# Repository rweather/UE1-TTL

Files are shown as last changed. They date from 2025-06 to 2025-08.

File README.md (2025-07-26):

UE1 Computer in TTL
===================

## What is this?

This is an implementation of the [Usagi Electric UE1 vacuum tube computer architecture](https://github.com/Nakazoto/UEVTC/wiki)
in TTL logic.  It runs the same code as the original.

Here is the top and bottom of the version 1 prototype, just after running the
Fibonacci example (click for a larger image):

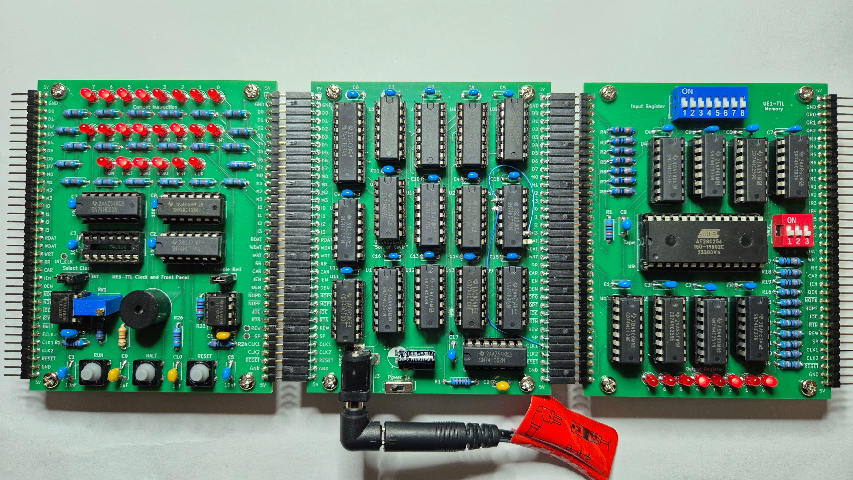
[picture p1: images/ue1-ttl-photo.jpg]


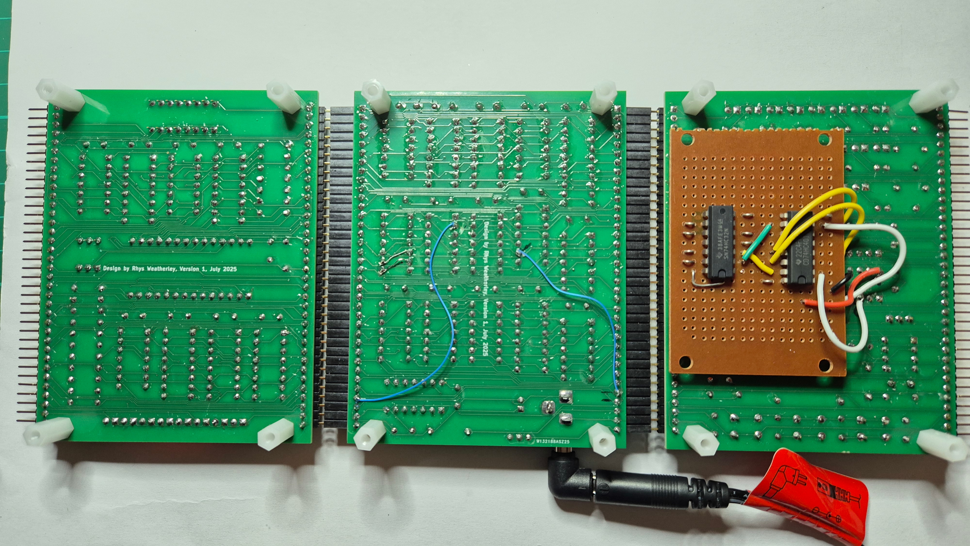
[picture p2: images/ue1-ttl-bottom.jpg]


I made some mistakes in the version 1 prototype that needed bodging.
The schematics and gerbers below have been updated to include the fixes.

## Specifications

* TTL logic, 555 timers, and EEPROM chips only.  No cheating with a modern
  microcontroller running an emulator.
* 1-bit processor core based on the UE14500 instruction set.
* 8-bit scratch register (general-purpose RAM).
* 8-bit output register.
* 7-bit input register.
* EEPROM that stores up to 8 program "tapes", each up to 4096 instructions.
  DIP switches select which program to run.
* 555-based clock that runs at frequencies between 0.7Hz and 480Hz.
* Run, Halt, and Reset buttons to control the computer.
* Blinkenlichten!
* Bell buzzer.
* Runs off a single 5V DC supply.

The computer is split across three PCB's, because:

* PCB's less than 100mm x 100mm in size are cheaper to get made.
* The aspect ratio of the boards is close to those of the wooden backing
  boards in the original UE1 to provide a similar visual aesthetic
  (although I need 3 boards compared with the original 2).
* It is easier to upgrade one of the boards without having to re-spin
  the other boards.

## Technical information

* [Theory of operation](doc/theory_of_operation.md)
* [Signals on the edge connectors](doc/edge_connectors.md)

### Clock and front panel board

* [Schematics](schematics/UE1-TTL-Clock/PDF/UE1-TTL-Clock.pdf)
* [Gerbers](schematics/UE1-TTL-Clock/Gerber)
* [Assembling and testing](doc/testing_clock.md)
* [Version 1 mistakes](doc/testing_clock.md#version-1-mistakes)

### Processor board

* [Schematics](schematics/UE14500-TTL/PDF/UE14500-TTL.pdf)
* [Gerbers](schematics/UE14500-TTL/Gerber)
* [Assembling and testing](doc/testing_processor.md)
* [Version 1 mistakes](doc/testing_processor.md#version-1-mistakes)

### Memory and I/O board

* [Schematics](schematics/UE1-TTL-Memory/PDF/UE1-TTL-Memory.pdf)
* [Gerbers](schematics/UE1-TTL-Memory/Gerber)
* [Assembling and testing](doc/testing_memory.md)
* [Version 1 mistakes](doc/testing_memory.md#version-1-mistakes)

## Programming the computer

To reprogram the computer it is necessary to remove the 32K AT28C256 tape
EEPROM from the memory board and flash in a new set of tape images using an
EEPROM programmer.

There can be up to 8 programs in the EEPROM, with DIP switches to select
which program to run.  Each program is up to 4096 instructions long,
which corresponds to about 10m of paper tape.  Each instruction consists
of a 4-bit opcode and a 4-bit memory address just like in the vacuum tube
based UE1.

Pad shorter programs with NOP0 instructions or replicate the program
multiple times to fill up the 4096 bytes of space.  There is a new
"rewind" opcode that can be used to loop short programs without
excessive NOP0's.  See the next section.

The "programs" directory contains some sample programs, together with a
Python script to pack up to 8 binaries into a single 32K EEPROM image.

## Instruction set

This computer uses the same [instruction set](https://github.com/Nakazoto/UEVTC/wiki/UE14500-Processor)
as the original computer.  The only difference is the introduction of a
"rewind" opcode which is encoded as "NOP0" with a memory address between
8 and 15 - bytes $08 to $0F in hexadecimal.

The rewind opcode causes the 12-bit program counter to reset back to 0
immediately, rather than waiting for the program counter to wrap around.
This can be convenient for short looping programs to avoid a long wait
for the loop to restart.

## Parts lists

In the parts lists below, "RLED" refers to the inline series resistor
for the LED's.  The value depends upon the type of LED you have, and can
be calculated from the LED's voltage drop (VLED) and rated current (ILED)
as follows:

    RLED = (5 - VLED) / ILED

For example, if your LED is rated for 1.9V and 10mA, then RLED should be
at least (5 - 1.9) / 0.01 = 310 ohms.  A 330 ohm resistor will do.
I recommend using LED's with 2mA or less current rating to avoid putting
too much strain on the TTL logic outputs.  I used 2mA LED's and RLED =
1800 ohms.

The IC's are listed as 74LS series, but you can use 74HC series instead.
Use the same series for all chips.

Parts lists for individual boards are listed first, and then a combined
parts list for the whole computer.

### Clock and front panel board

* 2 x 555 timer
* 1 x 74HC4017 decade counter
* 1 x 74LS74 dual D flip-flop
* 1 x 74LS02 quad NOR gate
* 1 x 74LS132 quad NAND gate with Schmitt trigger
* 2 x 10nF ceramic or monolithic capacitor
* 4 x 100nF ceramic or monolithic capacitor
* 4 x 1uF ceramic or monolithic capacitor
* 1 x 1M trimpot
* 2 x 1K resistor
* 1 x 3K3 resistor
* 1 x 4K7 resistor
* 1 x 10K resistor
* 1 x 100K resistor
* 22 x RLED resistor
* 22 x 3mm LED (colour of your choice)
* 1 x Buzzer with 7.6mm pin pitch
* 3 x 6mm momentary push button
* 1 x 3-way 2.54mm pin header
* 1 x 2-way 2.54mm pin header
* 2 x 2.54mm jumper
* 2 x 36-pin right-angle terminal header
* 2 x 8-pin DIP socket
* 3 x 14-pin DIP socket
* 1 x 16-pin DIP socket

### Processor board

* 3 x 74LS00 quad NAND gate
* 3 x 74LS02 quad NOR gate
* 2 x 74LS08 quad AND gate
* 3 x 74LS74 dual D flip-flop
* 1 x 74LS86 quad XOR gate
* 2 x 74LS138 3-to-8 line decoder
* 1 x 74LS251 8-line to 1-line multiplexer
* 1 x 74LS374 8-bit register
* 1 x 100uF electrolytic capacitor
* 1 x 1uF ceramic or monolithic capacitor
* 16 x 100nF ceramic or monolithic capacitor
* 1 x 10K resistor
* 1 x SPDT 2.54mm slide switch
* 1 x 2.5mm DC barrel jack
* 2 x 36-pin right-angle terminal socket
* 12 x 14-pin DIP socket
* 3 x 16-pin DIP socket
* 1 x 20-pin DIP socket

### Memory and I/O board

* 1 x AT28C256 32K x 8 EEPROM
* 1 x 74LS32 quad OR gate
* 1 x 74LS139 dual 2-to-4 line decoder
* 2 x 74LS251 8-line to 1-line multiplexer
* 2 x 74LS259 8-bit addressable latch
* 2 x 74LS393 dual binary 4-bit counter
* 9 x 100nF ceramic or monolithic capacitor
* 1 x 10K resistor
* 10 x 100K resistor
* 8 x RLED resistor
* 8 x 3mm LED (colour of your choice)
* 1 x 8-way DIP switches
* 1 x 3-way DIP switches
* 2 x 36-pin right-angle terminal header
* 3 x 14-pin DIP socket
* 5 x 16-pin DIP socket
* 1 x 28-pin DIP socket (15.24mm pitch width)

I recommend using a socket for the 28-pin EEPROM even if you don't use
sockets for the other chips.  You will need to easily remove the EEPROM to
reprogram it.

## Combined part list

This section combines all three lists into one to make it easier to
order the parts for the whole computer.  As stated before, 74HC series
chips can be used in place of 74LS.

* 1 x AT28C256 32K x 8 EEPROM
* 2 x 555 timer
* 1 x 74HC4017 decade counter
* 3 x 74LS00 quad NAND gate
* 4 x 74LS02 quad NOR gate
* 2 x 74LS08 quad AND gate
* 1 x 74LS32 quad OR gate
* 4 x 74LS74 dual D flip-flop
* 1 x 74LS86 quad XOR gate
* 1 x 74LS132 quad NAND gate with Schmitt trigger
* 2 x 74LS138 3-to-8 line decoder
* 1 x 74LS139 dual 2-to-4 line decoder
* 3 x 74LS251 8-line to 1-line multiplexer
* 2 x 74LS259 8-bit addressable latch
* 1 x 74LS374 8-bit register
* 2 x 74LS393 dual binary 4-bit counter
* 1 x 100uF electrolytic capacitor
* 5 x 1uF ceramic or monolithic capacitor
* 2 x 10nF ceramic or monolithic capacitor
* 29 x 100nF ceramic or monolithic capacitor
* 1 x 1M trimpot
* 2 x 1K resistor
* 1 x 3K3 resistor
* 1 x 4K7 resistor
* 3 x 10K resistor
* 11 x 100K resistor
* 30 x RLED resistor
* 30 x 3mm LED (colour of your choice)
* 1 x SPDT 2.54mm slide switch
* 1 x 2.5mm DC barrel jack
* 1 x Buzzer with 7.6mm pin pitch
* 3 x 6mm momentary push button
* 1 x 3-way 2.54mm pin header
* 1 x 2-way 2.54mm pin header
* 2 x 2.54mm jumper
* 1 x 8-way DIP switches
* 1 x 3-way DIP switches
* 4 x 36-pin terminal header (for clock and memory boards)
* 2 x 36-pin terminal socket (for CPU board)
* 2 x 8-pin DIP socket
* 18 x 14-pin DIP socket
* 9 x 16-pin DIP socket
* 1 x 20-pin DIP socket
* 1 x 28-pin DIP socket (15.24mm pitch width)

I recommend using a socket for the 28-pin EEPROM even if you don't use
sockets for the other chips.  You will need to easily remove the EEPROM to
reprogram it.

## License

<p xmlns:cc="http://creativecommons.org/ns#" xmlns:dct="http://purl.org/dc/terms/"><span property="dct:title">UE1 TTL</span> by <span property="cc:attributionName">Rhys Weatherley</span> is licensed under <a href="http://creativecommons.org/licenses/by-nc-sa/4.0/?ref=chooser-v1" target="_blank" rel="license noopener noreferrer" style="display:inline-block;">Attribution-NonCommercial-ShareAlike 4.0 International</a></p>

## Contact

For more information on this project, to report bugs, or to suggest
improvements, please contact the author Rhys Weatherley via
[email](mailto:rhys.weatherley@gmail.com).

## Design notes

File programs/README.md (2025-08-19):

This directory contains a 32K ROM image `UE1TEST.ROM` that can be used
to test the functionality of the UE1-TTL computer.

The ROM can hold up to eight programs, that are selected using DIP
switches on the memory board:

* 0 - UE1FIBO - Calculates the Fibonacci sequence up to 21, by Usagi Electric.
* 1 - UE1MATH - Performs addition and subtraction, by Usagi Electric.
* 2 - UE1\_DIAPER1 - Tests the entire instruction set except input and output.
* 3 - UE1\_DIAPER2 - Tests input and output.
* 4 - MUL5X5 - Multiplies two 5-bit numbers to produce a 10-bit result.
* 5 - DIV8x4 - Divides an 8-bit number by a 4-bit number to give an 8-bit quotient and a 4-bit remainder.
* 6 - UE1LIFE - 1-D game of life by decle.
* 7 - Rabbit example.

The Python script `ue1-ttl-pack.py` packs eight program images into a
single 32K ROM image.  It can be used to create ROM images with new programs.

The Rabbit example (program 7) is intended for use with an 8x8 dot matrix
LED display module that uses the MAX7221 LED driver chip.  The 3594
instructions of the program bit-bang out the SPI commands for displaying
"HELLORLD" followed by a picture of a rabbit.  See the Python script
"rabbit-gen.py" for more information on how to wire up the module.

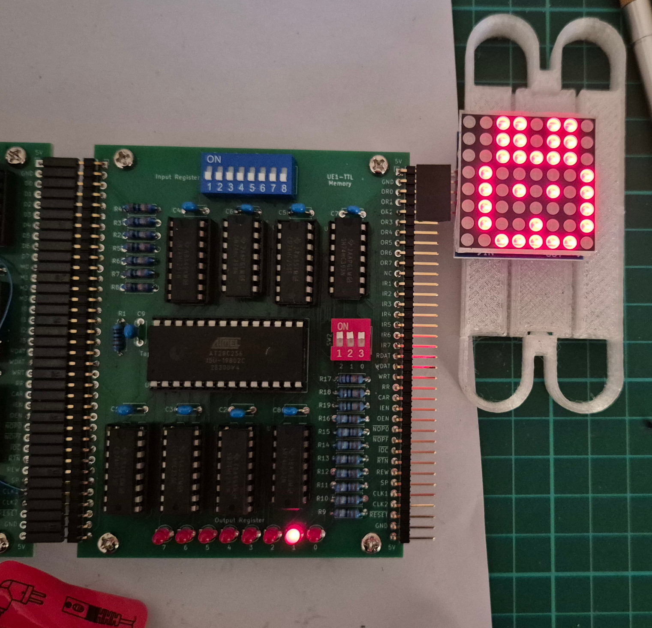
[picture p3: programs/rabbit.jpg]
UE1 Rabbit


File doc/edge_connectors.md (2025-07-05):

Signals on the Edge Connectors
==============================

The signals on the edge connectors are mostly passed as-is through to
each board.  There are some exceptions on the left-hand side of the
clock board and on the right-hand side of the memory board.

In the table below, "A/B" indicates that the pin has function "A" on
the left-hand side of a board and function "B" on the right-hand
side of a board.  "NC" indicates "not connected".

<table border="1">
<tr><td><b>Pin</b></td><td><b>Clock</b></td><td><b>Processor</b></td><td><b>Memory</b></td><td><b>Description</b></td></tr>
<tr><td>1</td><td>5V</td><td>5V</td><td>5V</td><td>Power</td></tr>
<tr><td>2</td><td>GND</td><td>GND</td><td>GND</td><td>Ground</td></tr>
<tr><td>3</td><td>D0</td><td>D0</td><td>D0/OR0</td><td>Bit 0 of the unbuffered tape instruction, or output register bit 0</td></tr>
<tr><td>4</td><td>D1</td><td>D1</td><td>D1/OR0</td><td>Bit 1 of the unbuffered tape instruction, or output register bit 1</td></tr>
<tr><td>5</td><td>D2</td><td>D2</td><td>D2/OR0</td><td>Bit 2 of the unbuffered tape instruction, or output register bit 2</td></tr>
<tr><td>6</td><td>D3</td><td>D3</td><td>D3/OR0</td><td>Bit 3 of the unbuffered tape instruction, or output register bit 3</td></tr>
<tr><td>7</td><td>D4</td><td>D4</td><td>D4/OR0</td><td>Bit 4 of the unbuffered tape instruction, or output register bit 4</td></tr>
<tr><td>8</td><td>D5</td><td>D5</td><td>D5/OR0</td><td>Bit 5 of the unbuffered tape instruction, or output register bit 5</td></tr>
<tr><td>9</td><td>D6</td><td>D6</td><td>D6/OR0</td><td>Bit 6 of the unbuffered tape instruction, or output register bit 6</td></tr>
<tr><td>10</td><td>D7</td><td>D7</td><td>D7/OR0</td><td>Bit 7 of the unbuffered tape instruction, or output register bit 7</td></tr>
<tr><td>11</td><td>MEM0</td><td>MEM0</td><td>MEM0/NC</td><td>Bit 0 of the buffered memory address</td></tr>
<tr><td>12</td><td>MEM1</td><td>MEM1</td><td>MEM1/IR1</td><td>Bit 1 of the buffered memory address, or input register bit 1</td></tr>
<tr><td>13</td><td>MEM2</td><td>MEM2</td><td>MEM2/IR2</td><td>Bit 2 of the buffered memory address, or input register bit 2</td></tr>
<tr><td>14</td><td>MEM3</td><td>MEM3</td><td>MEM3/IR3</td><td>Bit 3 of the buffered memory address, or input register bit 3</td></tr>
<tr><td>15</td><td>INST0</td><td>INST0</td><td>NC/IR4</td><td>Bit 0 of the buffered instruction opcode, or input register bit 4</td></tr>
<tr><td>16</td><td>INST1</td><td>INST1</td><td>NC/IR5</td><td>Bit 1 of the buffered instruction opcode, or input register bit 5</td></tr>
<tr><td>17</td><td>INST2</td><td>INST2</td><td>NC/IR6</td><td>Bit 2 of the buffered instruction opcode, or input register bit 6</td></tr>
<tr><td>18</td><td>INST3</td><td>INST3</td><td>NC/IR7</td><td>Bit 3 of the buffered instruction opcode, or input register bit 7</td></tr>
<tr><td>19</td><td>RD_DATA</td><td>RD_DATA</td><td>RD_DATA</td><td>Read data line, output from memory, input to processor</td></tr>
<tr><td>20</td><td>WR_DATA</td><td>WR_DATA</td><td>WR_DATA</td><td>Write data line, output from processor, input to memory</td></tr>
<tr><td>21</td><td>WRITE</td><td>WRITE</td><td>WRITE</td><td>Write control signal to memory, latch on falling edge</td></tr>
<tr><td>22</td><td>RR</td><td>RR</td><td>RR</td><td>State of the result register RR</td></tr>
<tr><td>23</td><td>CAR</td><td>CAR</td><td>CAR</td><td>State of the carry register CAR</td></tr>
<tr><td>24</td><td>IEN</td><td>IEN</td><td>IEN</td><td>State of the input enable register IEN</td></tr>
<tr><td>25</td><td>OEN</td><td>OEN</td><td>OEN</td><td>State of the output enable register OEN</td></tr>
<tr><td>26</td><td>OP_NOP0</td><td>OP_NOP0</td><td>OP_NOP0</td><td>Low when a NOP0 instruction is being executed</td></tr>
<tr><td>27</td><td>OP_NOPF</td><td>OP_NOPF</td><td>OP_NOPF</td><td>Low when a NOPF/HLT instruction is being executed</td></tr>
<tr><td>28</td><td>OP_IOC</td><td>OP_IOC</td><td>OP_IOC</td><td>Low when a IOC/BEL instruction is being executed</td></tr>
<tr><td>29</td><td>OP_RTN</td><td>OP_RTN</td><td>OP_RTN</td><td>Low when a RTN instruction is being executed</td></tr>
<tr><td>30</td><td>HALTED/REWIND</td><td>REWIND</td><td>REWIND</td><td>High when a rewind instruction is being executed, or the active-low halt signal on the left-hand side of the clock board</td></tr>
<tr><td>31</td><td>EXT_CLK/SPARE</td><td>SPARE</td><td>SPARE</td><td>Spare signal that is passed to all boards, or the external clock on the left-hand side of the clock board</td></tr>
<tr><td>32</td><td>CLK1</td><td>CLK1</td><td>CLK1</td><td>CLK1 pulse for the two-phase clock</td></tr>
<tr><td>33</td><td>CLK2</td><td>CLK2</td><td>CLK2</td><td>CLK2 pulse for the two-phase clock</td></tr>
<tr><td>34</td><td>RESET</td><td>RESET</td><td>RESET</td><td>Active-low signal to reset the system</td></tr>
<tr><td>35</td><td>GND</td><td>GND</td><td>GND</td><td>Ground</td></tr>
<tr><td>36</td><td>5V</td><td>5V</td><td>5V</td><td>Power</td></tr>
</table>

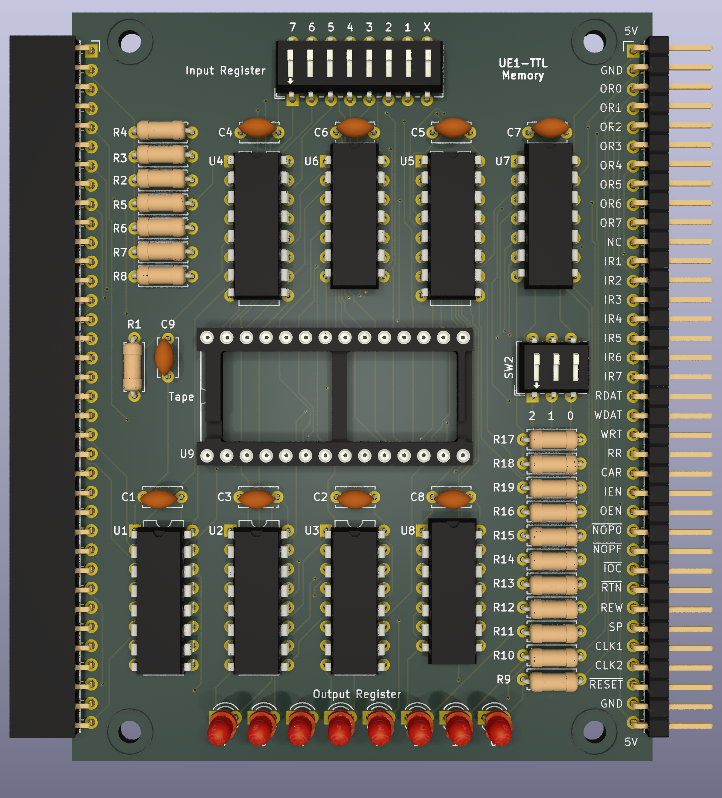
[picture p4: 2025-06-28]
images/kicad-3d-memory-board.png

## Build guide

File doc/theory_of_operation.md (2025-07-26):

UE1 TTL Computer Theory of Operation
====================================

## Overview

This page explains the theory of operation of the TTL version of the UE1.

The design is not gate-compatible with the original NOR gate heavy
vacuum tube computer.  I wimped out and used dedicated TTL chips for
flip-flops, AND/OR/NAND/XOR gates, multiplexers, decoders, memory chips, etc.
The design runs the same code, but not in the same way.

In the sections below, "P/Un" is used to refer to IC's on the processor
board, "C/Un" is used to refer to IC's on the clock board, and
"M/Un" is used to refer to IC's on the memory board.

## Clock

The processor requires a two-phase clock, delivered on the CLK1 and CLK2
pins of the edge connector.  The waveforms look like this:

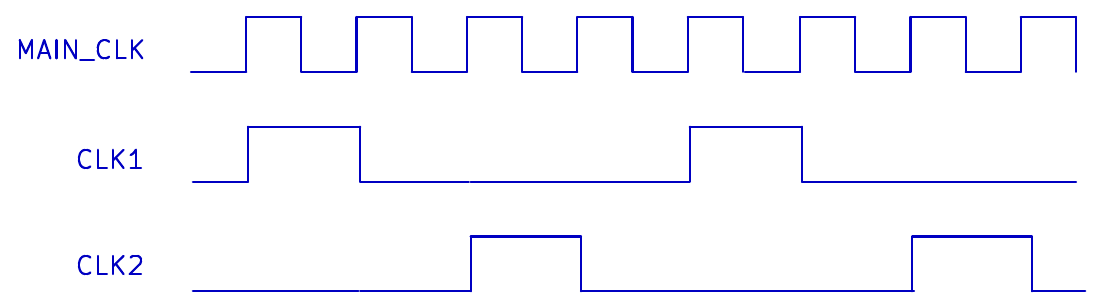
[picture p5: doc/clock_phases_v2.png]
Clock Phases


* Rising edge of CLK1 - Load the next instruction into the instruction register.
* Falling edge of CLK1 - Perform the instruction; update registers and memory.
* Rising edge of CLK2 - Update the SKIP register.
* Falling edge of CLK2 - Increment the program counter / tape position.

The original UE1 also has a two-phase clock, which it achieves with an
RC delay on CLK1 to produce CLK2.  The two clock pulses overlap which
makes it closer to one clock cycle per instruction than my design.

The clock board derives CLK1 and CLK2 from the MAIN\_CLK signal.
C/U3 on the clock board is a 555 timer that provides the MAIN\_CLK
between 0.7Hz and 480Hz.  This is divided by four by C/U2 to create
CLK1 and CLK2:

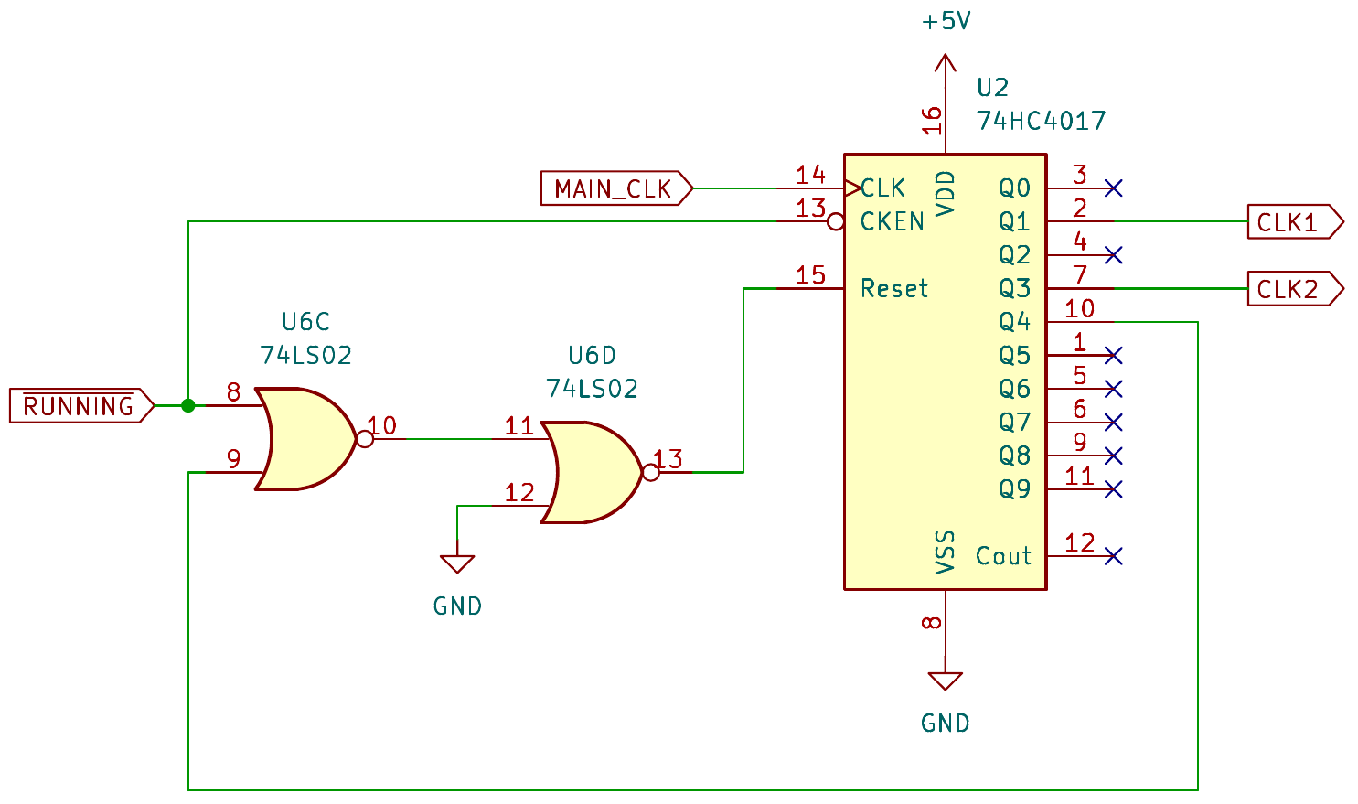
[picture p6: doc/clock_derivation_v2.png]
Clock Derivation


The /RUNNING signal forces both clocks to zero when the machine halts
by holding C/U2 in reset and disabling the clock input.  The clock
resumes with CLK1 preceding CLK2 when /RUNNING goes high.

If /RUNNING goes high in the middle of a CLK1 pulse or before the rising
edge of CLK2, then the current instruction will be only partially executed.

The maximum CPU speed is 120 instructions per second.  If you want to run the
computer faster than that, there are two options:

* Change C4 in the clock circuit from 1uF to something smaller.  Changing it
  to 100nF will give a 10x improvement in performance.
* Move the "Select Clock" jumper to the EXT position and inject your
  own MAIN\_CLK from off-board.

My previous clock design in version 1 used a 74LS74 flip-flop and AND gates to
generate CLK1 and CLK2 with a divide-by-two setup:

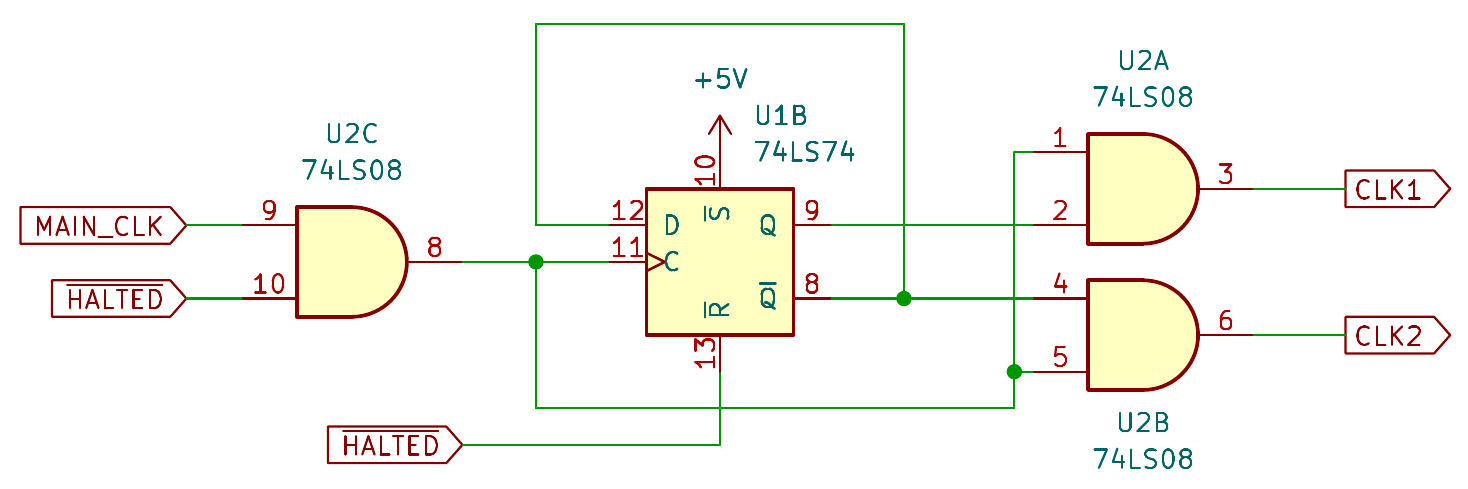
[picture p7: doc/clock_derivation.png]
Clock Derivation Version 1


This caused clock gitches all over the place, causing double increments on
the program counter, false memory writes, and other problems.  The waveform
looked something like this:

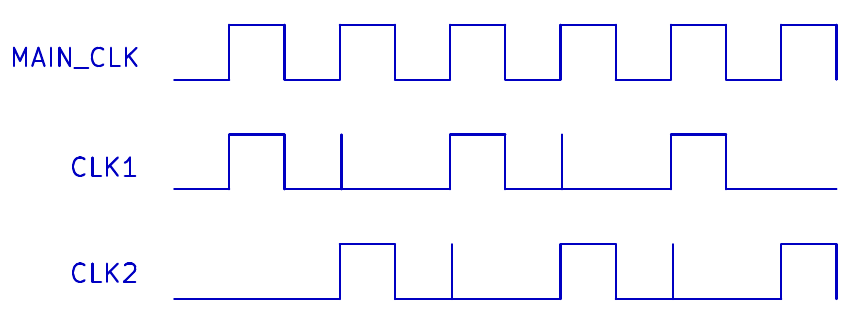
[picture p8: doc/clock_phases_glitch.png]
Glitching Clock Phases


Never gate your clock!  I know that now!

## Run/Stop Control

The Run/Stop circuit on the clock board handles the "Run" and "Halt"
push buttons.  When the computer resets at power-on, the system
will eventually settle into a state with /HALTED low and /RUNNING high.
Pressing "Run" will change /RUNNING to low, /HALTED to high, and the
two-phase clock will start ticking.

The "Reset" button is on the clock board, but its RC network is on
the CPU board.  "Run", "Halt", and "Reset" have different R values in
their RC networks.  All of them will be low at power-on, with "Run"
going high first, then "Halt", and finally "Reset".

Pressing "Reset" will halt the computer, reset all registers, and set
the program counter back to zero.  Pressing "Halt" halts the computer
but preserves the registers and program counter.

C/U5 interlocks the "Run" and "Halt" buttons so that if both are
pressed at the same time, "Halt" will win the battle.  The /NOPF
signal from the CPU board will cause the system to halt on the
falling edge of CLK2.  C/U5 consists of Schmitt-triggered NAND gates to
ensure that the /RUN and /STOP signals are nice and square.

There is a bug with this design.  If the "Run" button is held down,
the program will run until halt and then start running again.  "Run" and
"Halt" should only act on a low-going edge, not on a low level.
Press "Run" fast enough and it isn't an issue, for now.

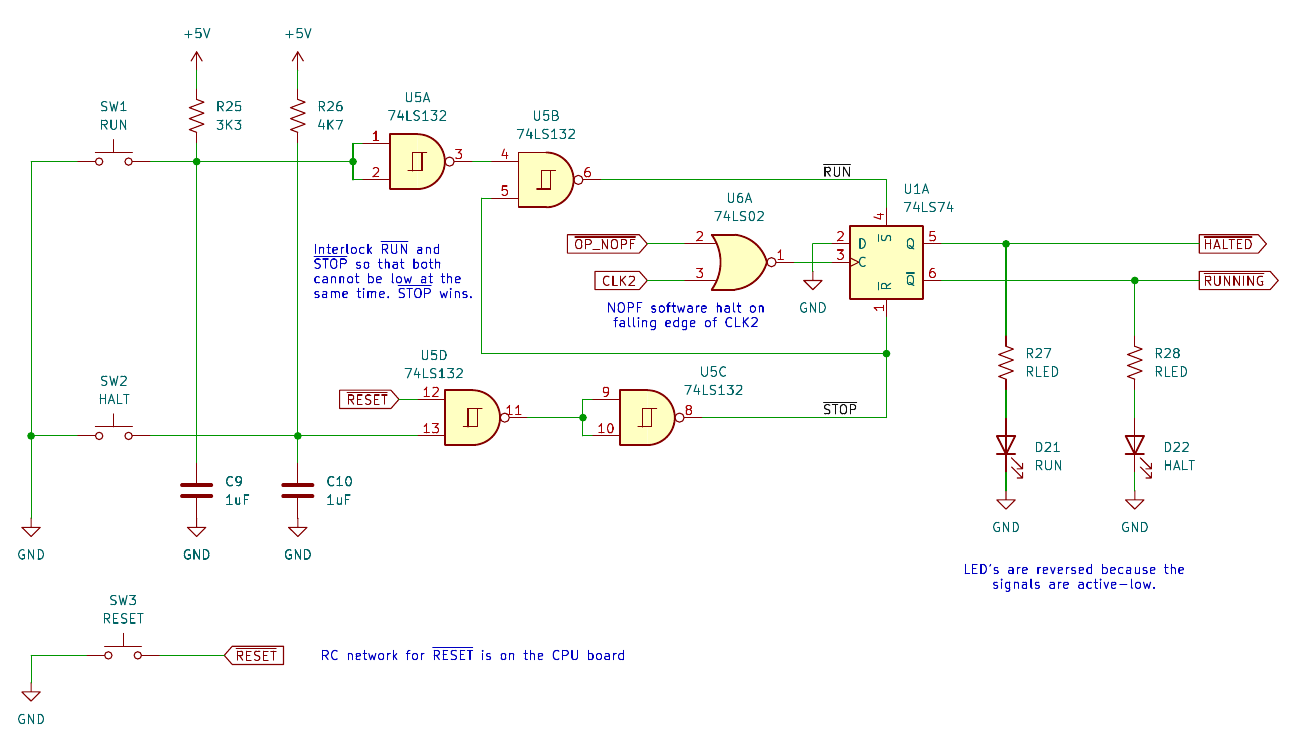
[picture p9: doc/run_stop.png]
Run/Stop Control


## Single-Stepping

The clock board does not have a method to single-step instructions,
as at the time I could not figure out how to generate a single pair of
CLK1/CLK2 pulses and then stop.

For debugging, you can hook up an external clock using a push button.
The button needs to be pressed four times to execute a single
instruction.  This is what the circuit looks like:

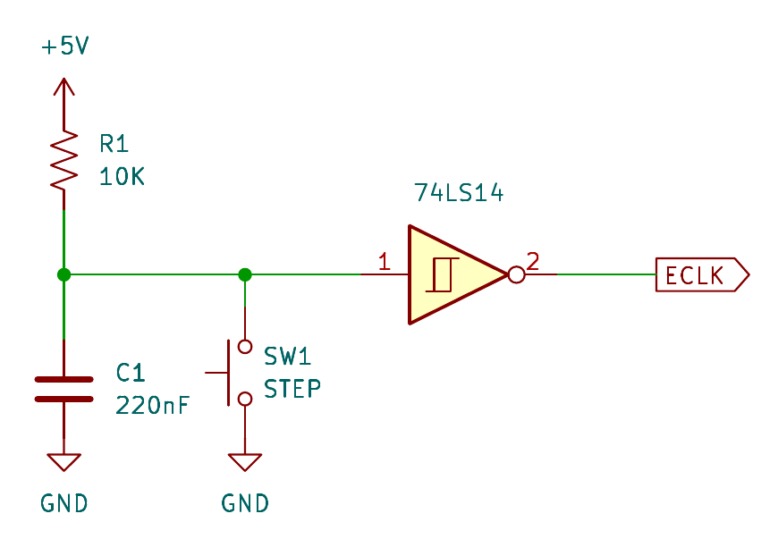
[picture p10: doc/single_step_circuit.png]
Single-Step


Shift the "Select Clock" jumper to the EXT side of the 3-pin header
to use this setup.

## Instruction Register

On the rising edge of CLK1, the next instruction is loaded into P/U4, a
74LS374 8-bit register.  The instruction data itself comes from the
memory board on the D0 to D7 pins.  P/U4 buffers the instruction and
makes the buffered memory address available to the memory board on
MEM0 to MEM3.

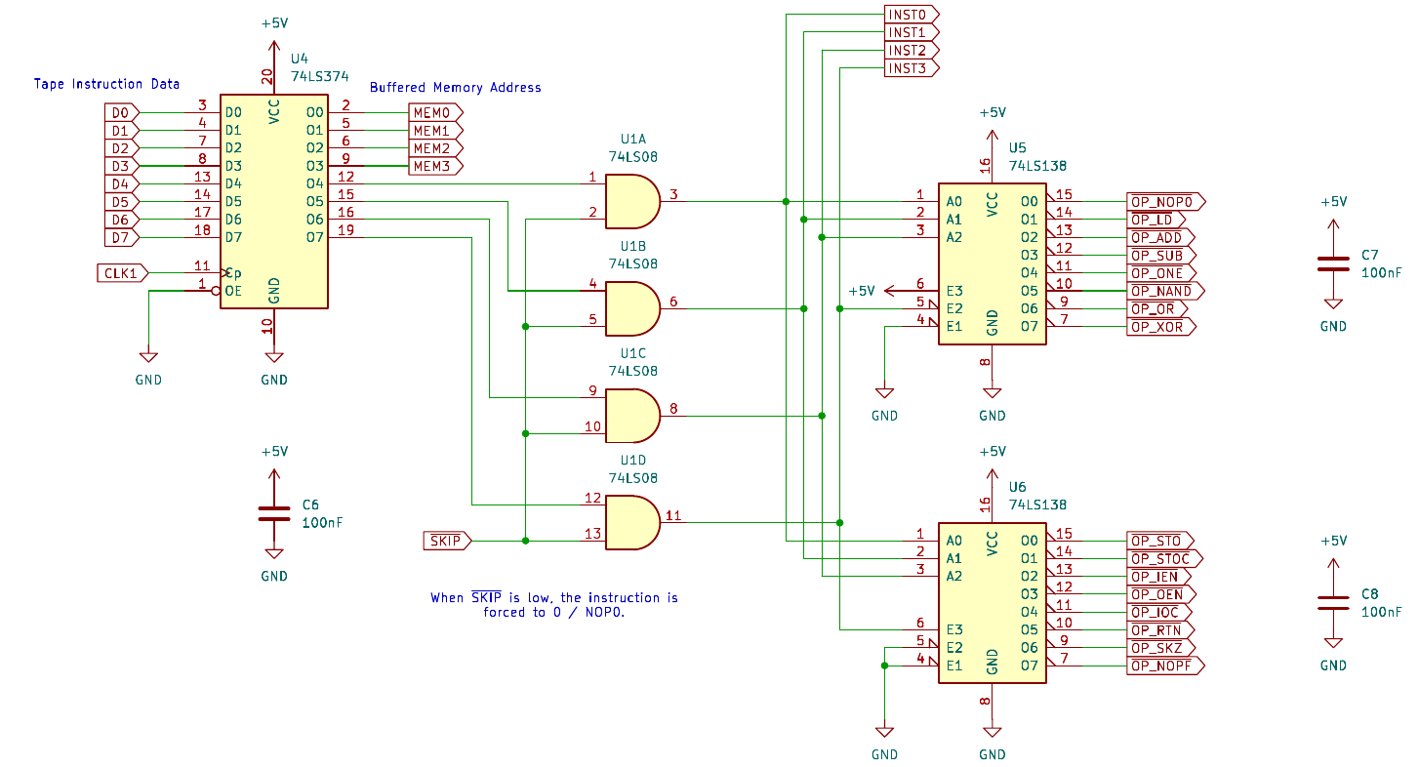
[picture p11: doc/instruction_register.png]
Instruction Register


If the SKIP register is set to 1, then /SKIP is set to 0.  The quad AND
gate P/U1 forces the instruction opcode to NOP0 / 0 when SKIP is set.

Once the instruction has been buffered in P/U4 and optionally zero'ed
by P/U1, the four lines INST0 to INST3 are decoded by P/U5 and P/U6 to
produce active-low control lines for each of the opcode types.
These go to various places on the rest of the processor board.

## Rewind Instruction

The program size on the "tape" is 4096 bytes.  The program can be padded
with NOP0 instructions but that will take a very long time to loop
around if the program is short.

To address this, the computer extends the UE1 instruction set with a
"rewind" instruction, which forces the program counter to reset to zero
immediately under program control.  The following circuit on the
processor board decodes the rewind instruction:

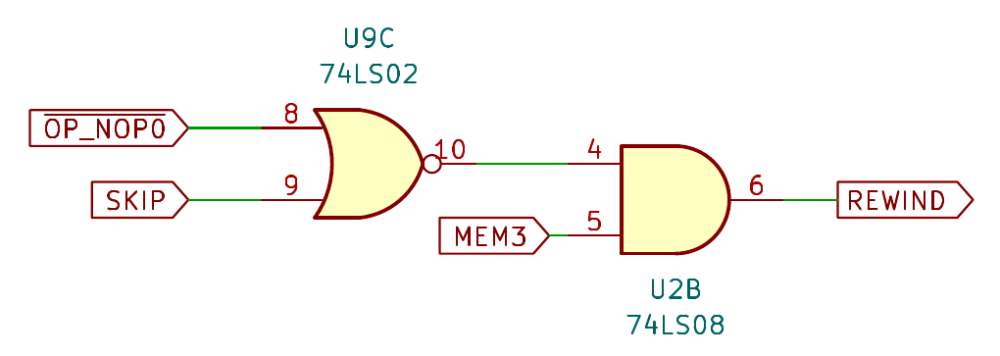
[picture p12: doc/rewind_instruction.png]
Rewind Instruction


The opcode for "rewind" is any value between $08 and $0F hexadecimal.
These are NOP0 instructions, but they also have the side-effect of
rewinding the tape back to the start of the program.

The rewind request will be ignored if the SKIP register is set, which
offers the possibility of "if" statements that can jump back to the start
of the tape early if some condition is true.

Because of the simple decoding method used, there are 8 different rewind
instructions.  This is a bit wasteful, but there may be a use for this.
Instead of rewinding back to the start of the tape, rewind to one of
8 fixed locations on the tape as determined by MEM0, MEM1, and MEM2.

With a 4096-byte program size, jump locations could be equally spaced
every 512 bytes.  Think of it as a poor man's jump instruction.  The code
would need to be laid out to put the jump labels at multiples of 512,
but that isn't hard.  The current memory board doesn't do this,
but replacement memory boards could.

Note: There is a slight bug in my implementation of "rewind" that can
cause instructions to be skipped when they shouldn't be.  It is easy
to work around the problem with slight modifications to the code,
or by disabling "rewind" entirely.  See [this page](testing_memory.md#version-1-mistakes) for more information.

## Registers

RR, CAR, IEN, OEN, and SKIP are implemented in 74LS74 flip-flops.
All except SKIP are clocked on the falling edge of CLK1.  SKIP is
clocked on the rising edge of CLK2.  The following circuit is for RR
(CAR is similar):

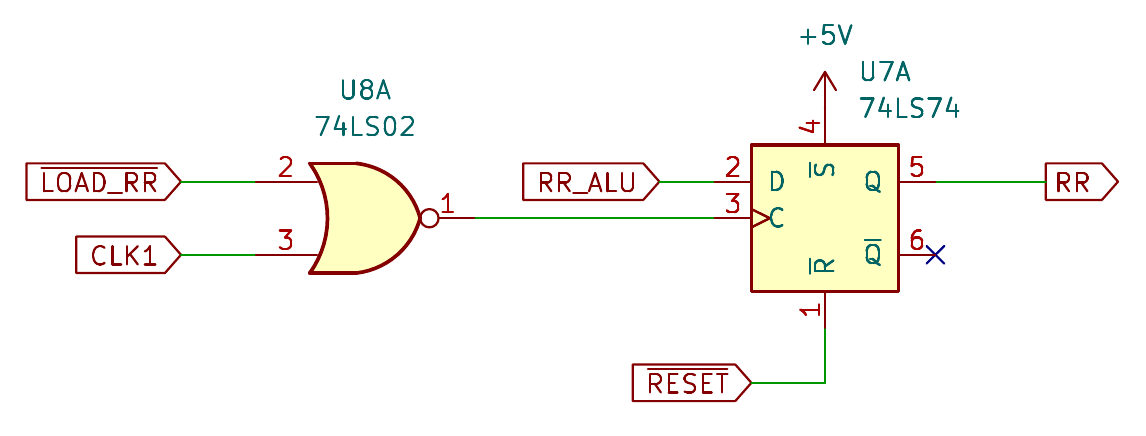
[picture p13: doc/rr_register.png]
RR Register


RR\_ALU is the output of the ALU, described in the next section.
/LOAD\_RR goes low for any ALU instruction: LD, ADD, SUB, ONE,
NAND, OR, and XOR.

The input enable register (IEN) gates the RD\_DATA signal from the
memory board to force DATA\_ALU to zero if IEN is zero:

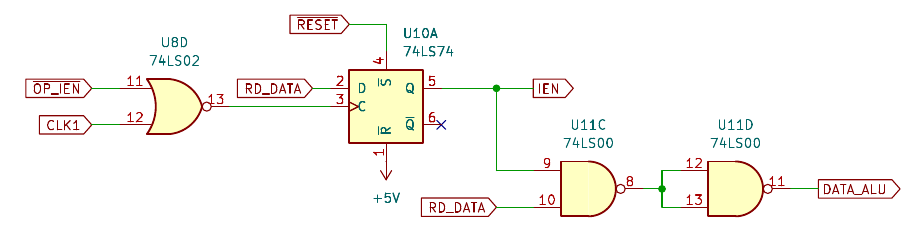
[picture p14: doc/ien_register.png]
IEN Register


The output enable register (OEN) generates a WRITE pulse when a STO or
STOC instruction is encountered and OEN is 1.  The value WR\_DATA
is latched on the falling edge of WRITE:

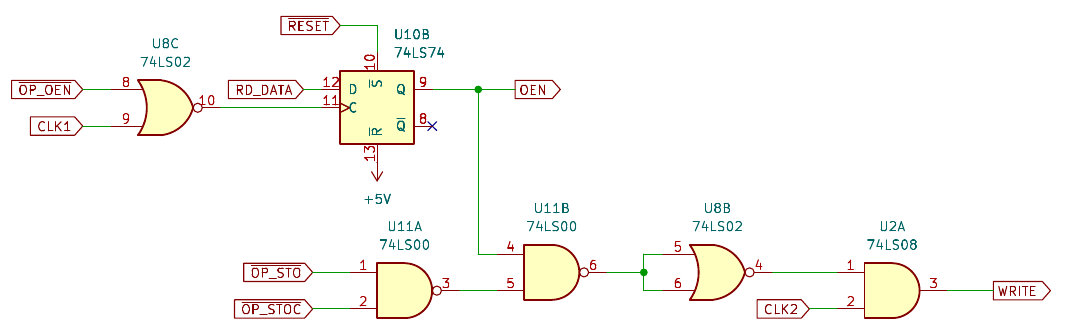
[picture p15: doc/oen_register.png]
OEN Register


Store Value

A new value for SKIP is evaluated every instruction cycle on the
rising edge of CLK2.  If /OP\_RTN is low, then SKIP is set to 1.
If /OP\_SKZ is low and RR is low, then SKIP is set to 1.
If neither case is true, then SKIP is set to 0.

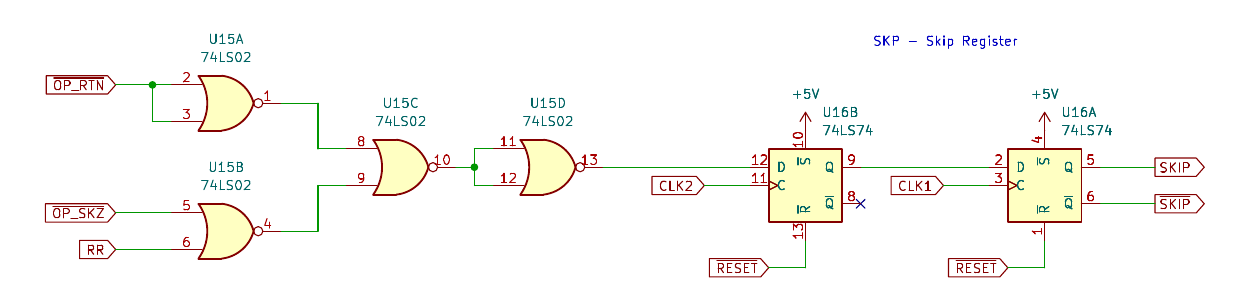
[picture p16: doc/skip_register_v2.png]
Skip Register


The SKIP value is "double-buffered" by two flip-flops.  This ensures
that the state of SKIP does not affect the instruction register until
the next instruction is loaded on the rising edge of CLK1.  Without
the double buffering, it is possible for skipped instructions to
"un-skip" in the middle of instruction execution.

## Arithmetic and Logic Unit

The core of the ALU is a network of gates that computes the result
of the ADD, SUB, NAND, OR, and XOR instructions in parallel:

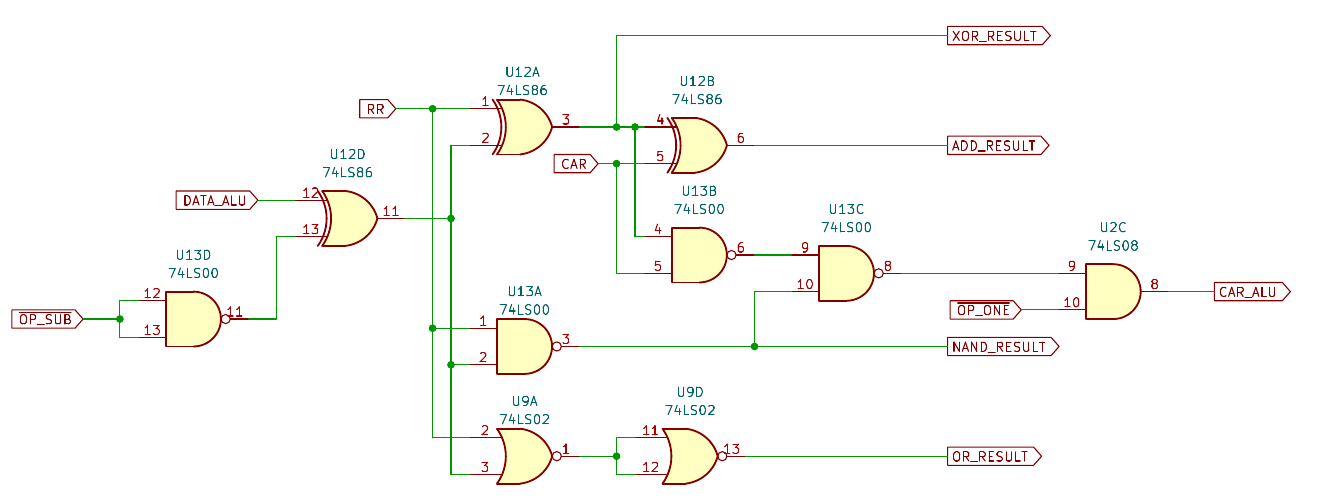
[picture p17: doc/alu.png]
Arithmetic and Logic Unit


The result is then fed into the multiplexer P/U14 to select the
value to store back to RR based on the current opcode:

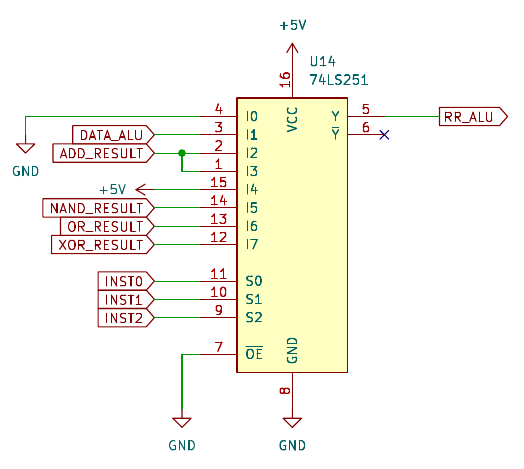
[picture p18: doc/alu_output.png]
Arithmetic and Logic Unit Output


## Bell

The bell circuit uses a 555 timer to generate a monostable pulse
to drive a buzzer when the /OP\_IOC control line goes low.

This circuit was partially a mistake.  I probably should have used a drive
transistor on the output of the 555 to handle the 30mA or so of buzzer current.
I managed to get away with it and the bell does work when running programs.

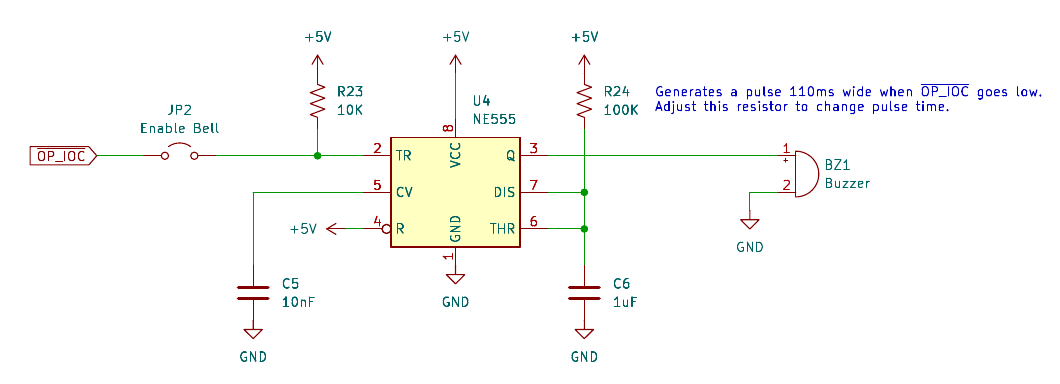
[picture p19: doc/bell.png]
Bell Circuit


I tried to wire the 555 timer up in monostable mode to generate a 110ms pulse
on the falling edge of /OP\_IOC.  This didn't work!  The bell sounds when
/OP\_IOC is low and doesn't stop until it goes high again.  In practice
this isn't a problem at low instruction execution speeds so I left it alone.

## Tape

Up to eight programs are stored in a AT28C256 32K x 8 EEPROM, each
4096 bytes in size.  The specific program to run is selected with DIP
switches via PGM0, PGM1, and PGM2.

The program counter / tape position is generated by a 12-bit counter chain
made up of M/U6 and M/U7.  When the processor resets, or a "rewind"
instruction is encountered, the counters reset to zero.

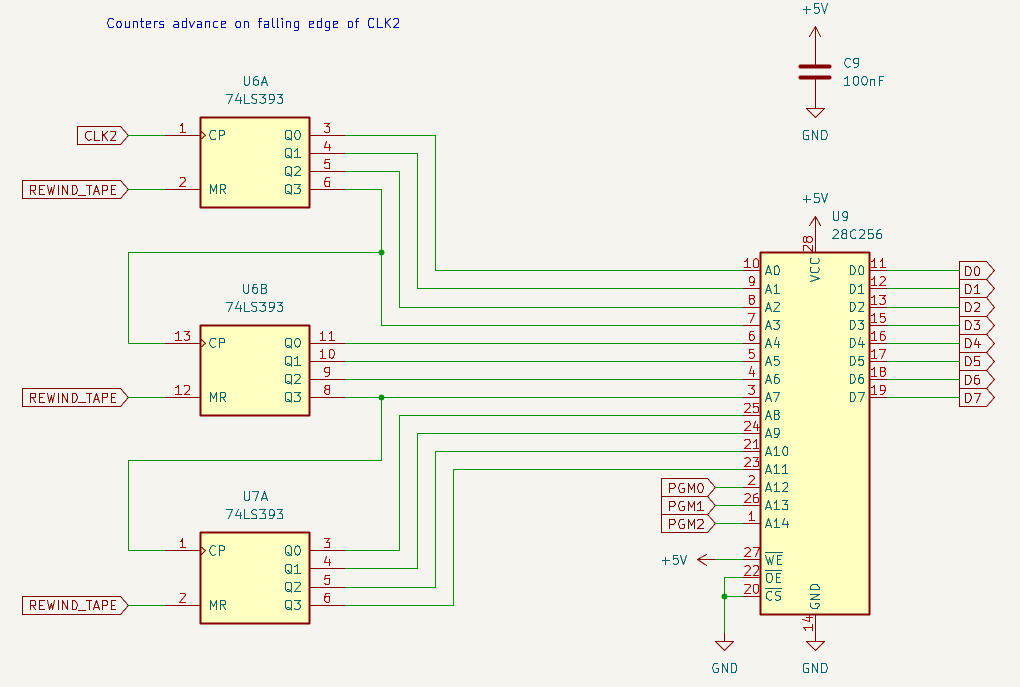
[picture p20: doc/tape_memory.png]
Tape Memory


## Scratch Register

The 8 bits of memory for the scratch register are implemented by M/U2,
a 74LS259 8-bit addressable latch.  Each bit can be written individually,
based on the memory address in MEM0, MEM1, and MEM2.

The latch is followed up by the 74LS251 multiplexer M/U3 which selects a
single bit for delivery back to the processor board as RD\_DATA.

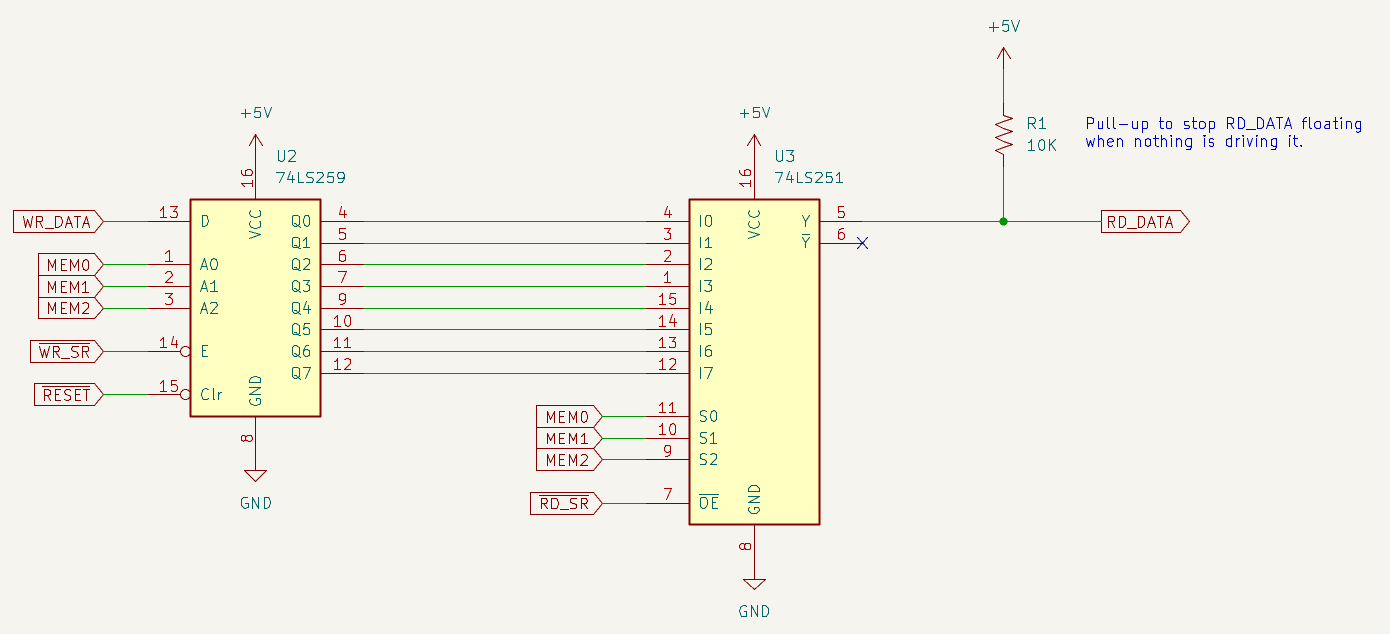
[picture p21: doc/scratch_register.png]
Scratch Register


## Input Register

The input register consists of seven DIP switches to provide the on/off
state of each bit, plus a 74LS251 multiplexer to select the specific bit to
deliver to the processor board as RD\_DATA.

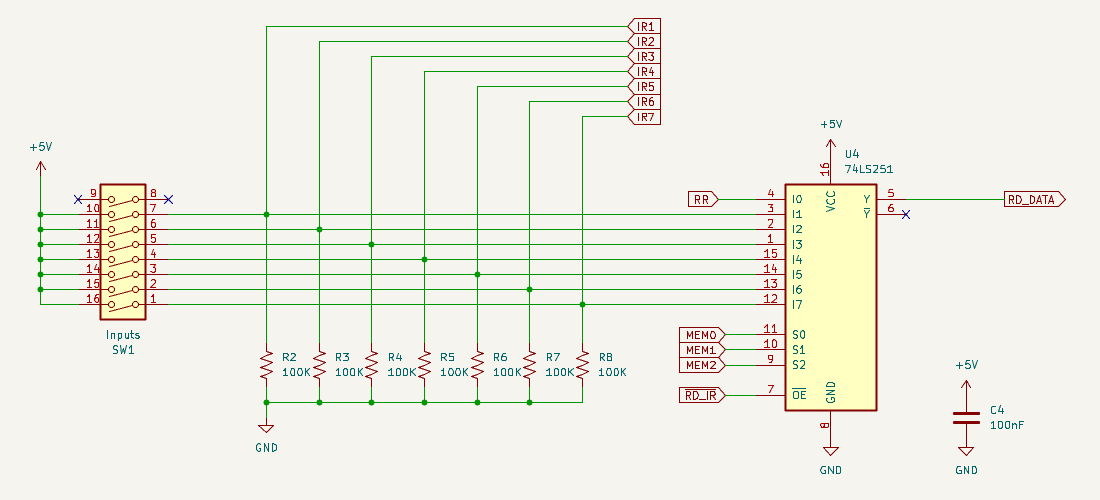
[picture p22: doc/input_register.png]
Input Register


The seven input bits are available on the right-hand side pin header on
the memory board.  The on-board DIP switches for the inputs must be in the
OFF position when injecting signals from off-board or a direct short
between 5V and GND may occur.

## Output Register

The output register consists of a 74LS259 8-bit addressable latch and a
bunch of LED's to show the output state.  The eight output bits are available
on the right-hand side pin header of the memory board for expansion purposes.

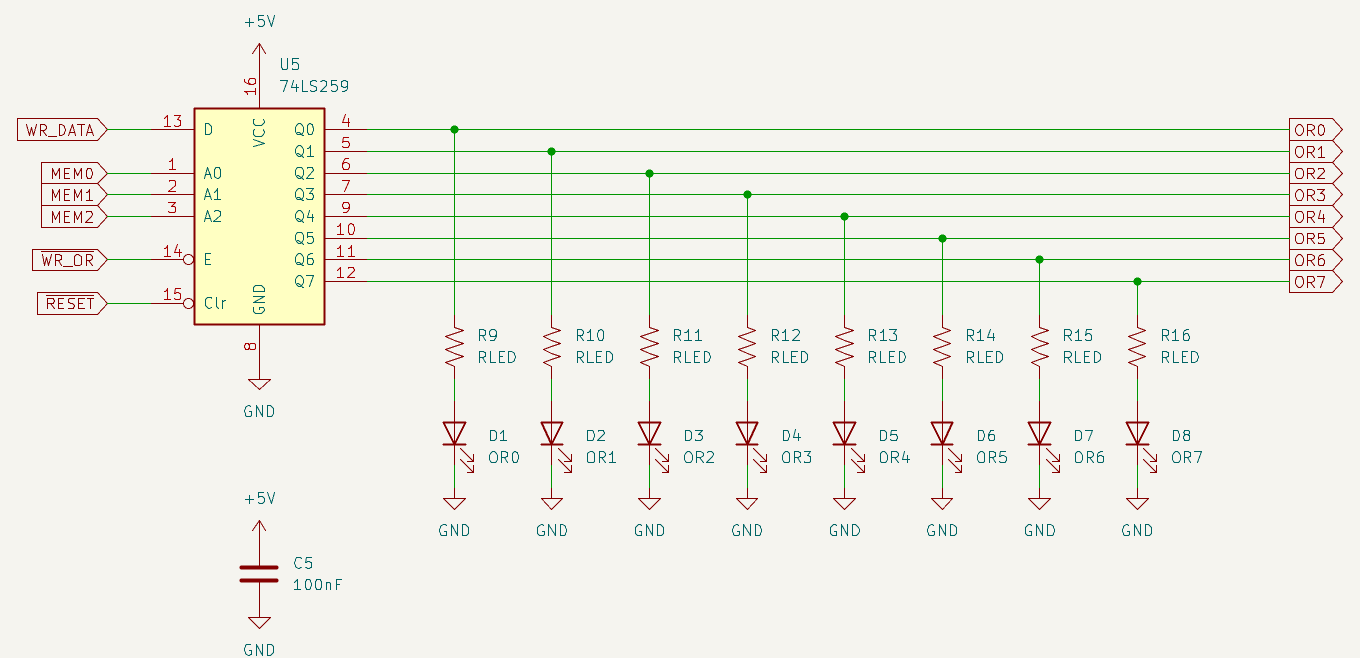
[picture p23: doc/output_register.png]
Output Register


## Future Possibilities

The computer is modular in design so that each of the three boards
can be replaced.  Want a different instruction set?  Replace the
processor board.  What a different memory map?  Replace the memory board.

The input and output register bits are available on the right-hand
side pin header for connecting to external devices.

A better program counter design could implement multiple jump targets
for the "rewind" instruction, as described earlier.

## Bugs

I made several mistakes in version 1 of the design.  They are documented
on these pages:

* [Clock board mistakes](testing_clock.md#version-1-mistakes)
* [Processor board mistakes](testing_processor.md#version-1-mistakes)
* [Memory board mistakes](testing_memory.md#version-1-mistakes)

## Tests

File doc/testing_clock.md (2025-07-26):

Assembling and Testing the Clock Board
======================================

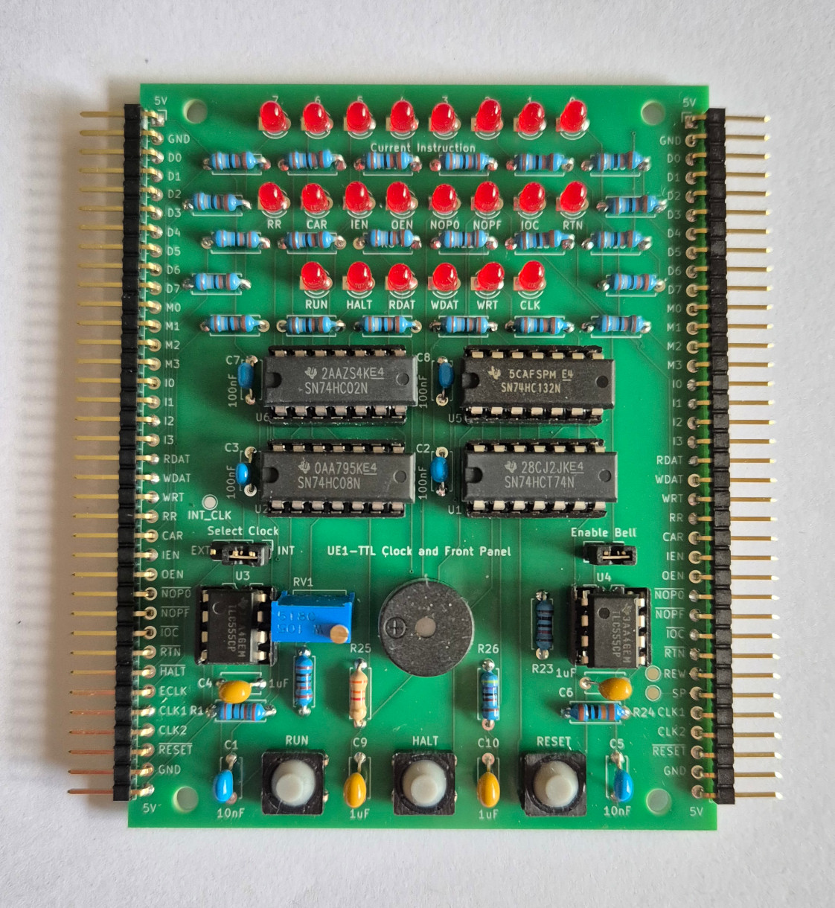
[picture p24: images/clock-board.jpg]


Note: The above photo is the version 1 prototype.  U2 was changed to a
4017 decade counter in the second version, as I made a mistake in the
clock circuit in version 1.

## Parts

* 2 x 555 timer
* 1 x 74HC4017 decade counter
* 1 x 74LS74 dual D flip-flop
* 1 x 74LS02 quad NOR gate
* 1 x 74LS132 quad NAND gate with Schmitt trigger
* 2 x 10nF ceramic or monolithic capacitor
* 4 x 100nF ceramic or monolithic capacitor
* 4 x 1uF ceramic or monolithic capacitor
* 1 x 1M trimpot
* 2 x 1K resistor
* 1 x 3K3 resistor
* 1 x 4K7 resistor
* 1 x 10K resistor
* 1 x 100K resistor
* 22 x RLED resistor (choose to suit the properties of the LED's)
* 22 x 3mm LED (colour of your choice)
* 1 x Buzzer with 7.6mm pin pitch
* 3 x 6mm momentary push button
* 1 x 3-way 2.54mm pin header
* 1 x 2-way 2.54mm pin header
* 2 x 2.54mm jumper
* 2 x 36-pin right-angle terminal header
* 2 x 8-pin DIP socket
* 3 x 14-pin DIP socket
* 1 x 16-pin DIP socket

The IC's are listed as 74LS series, but you can use 74HC series instead.
Use the same series for all chips.

## Assembling

Start in the usual way with the low profile components and work up in height:

* Resistors; most of the values are marked, except the LED series resistors.
* Pin headers along the left and right edges
* LED's, short lead in the square hole (cathode) and long lead into the
  round hole (anode).
* Run, Halt, and Reset push buttons
* IC sockets
* Capacitors, noting the three different values of 10nF, 100nF, and 1uF that
  are marked on the board.
* Buzzer
* 3-pin and 2-pin headers
* Variable resistor RV1
* Add a jumper on the INT side of the "Select Clock" 3-pin header
* Add a jumper to the "Enable Bell" 2-pin header

Do a quick test with a multimeter to make sure there is no short
between 5V and ground.  Then insert the IC's into the sockets:

* U1 - 74LS74
* U2 - 74HC4017
* U3 - 555
* U4 - 555
* U5 - 74LS132
* U6 - 74LS02

## Testing

## Stop/Run

Connect 5V and GND to a bench power supply.  Also jumper /RESET and /NOPF
to 5V temporarily.  If you don't do this, the Stop/Run circuit may get
stuck in halt due to the floating pins.

Turn the power on and the halt light should turn on.

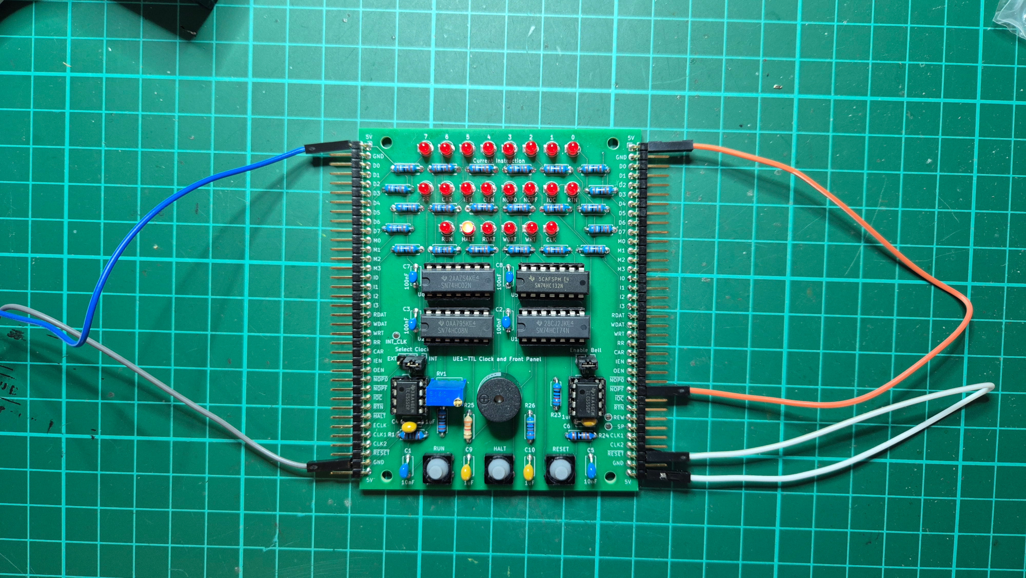
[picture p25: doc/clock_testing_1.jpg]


Press RUN, the halt light should turn off, the run light should turn on,
and the clock light should start blinking.  If this doesn't happen,
turn off the board, check that the IC's are in the right sockets and
that there are no shorts or bad solder joints on the board.

Press HALT, then RUN, and back again a few times to check that clock
starts and stops as expected when the buttons are pressed.

## Clock

Press RUN.  Adjust RV1 and check that the blink rate changes with resistance.
An oscilloscope can be used to check it.  Connect the probe to the
INT\_CLK test point and adjust RV1.  It should be possible to adjust
the frequency up to 480Hz.  Note that the CLK light blinks at a quarter the
rate of INT\_CLK.

Connect an oscilloscope to CLK1 and CLK2 on the edge connectors,
press RUN, and check that the clock phases alternate properly:

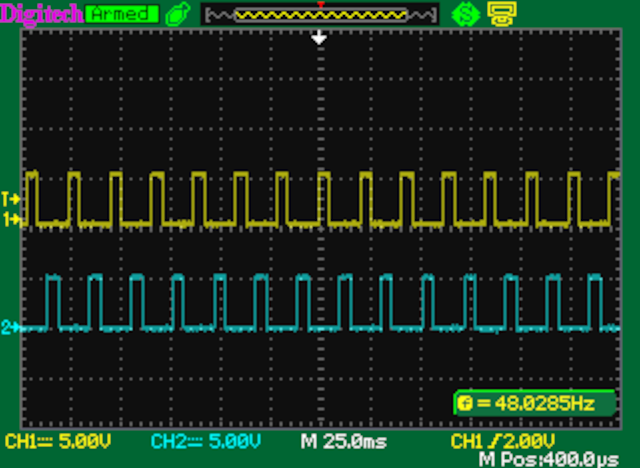
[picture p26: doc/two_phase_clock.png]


## LED's

Most of the LED's are connected to pins on the edge pin headers, so they
can be tested one at a time by connecting either 5V or GND to each pin.

Current instruction:

* Bit 0 - M0 - active-high, connect to 5V
* Bit 1 - M1 - active-high
* Bit 2 - M2 - active-high
* Bit 3 - M3 - active-high
* Bit 4 - I0 - active-high
* Bit 5 - I1 - active-high
* Bit 6 - I2 - active-high
* Bit 7 - I3 - active-high

Active-high control lines (connect to 5V): RR, CAR, IEN, OEN, RDAT, WDAT, WRT.

Active-low control lines (connect to GND): NOP0, NOPF, IOC, RTN.

The buzzer should also beep when you connect IOC to GND.

Next: [Assembling and testing the processor board](testing_processor.md).

## Version 1 mistakes

I made some mistakes in the version 1 prototype of the clock board.

The bell sounds continuously while IOC is low.  It was supposed to trigger a
single 110ms wide pulse one each time IOC went low.  Clearly I don't understand
how 555 timers work in anything except astable mode.  It isn't too bad though;
the bell will sound for a single instruction time before IOC goes high again.
If the computer's clock speed is low enough, the bell sounds OK.
So I left it as-is.

The bigger problem was that my 2-phase clock design was totally wrong.
I thought I was being clever using a 74LS74 flip-flop and some AND
gates to derive the two-phase clock:

Clock Derivation

Never gate your clock!  There were phantom pulses all over the place,
leading to double-increments of the program counter, malfunctioning
memory writes, and so on.  The signals were supposed to look like this:

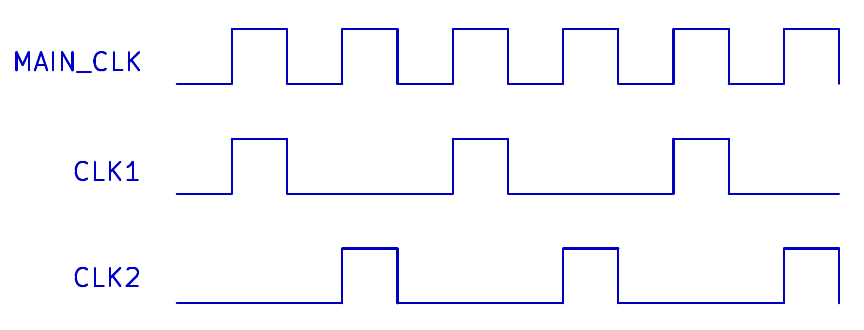
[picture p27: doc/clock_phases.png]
Clock Phases


Instead I ended up with something like this:

Glitching Clock Phases

I switched to using a 4017 decade counter in the second version of the
clock board, which generates cleaner clock pulses.  The downside is that
the clock circuit is now divide-by-4 instead of divide-by-2, which makes the
maximum speed 120 instructions per second instead of 240.

If C4 in the clock circuit is reduced from 1uF to 100nF, the system gets a
10x boost in clock speed, making the maximum speed 1200 instructions per
second instead.  So the divide-by-4 isn't too terrible.  Use 470nF for
C4 if you want something closer to the original design speed of 240
instructions per second.

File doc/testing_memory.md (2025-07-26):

Assembling and Testing the Memory and I/O Board
===============================================

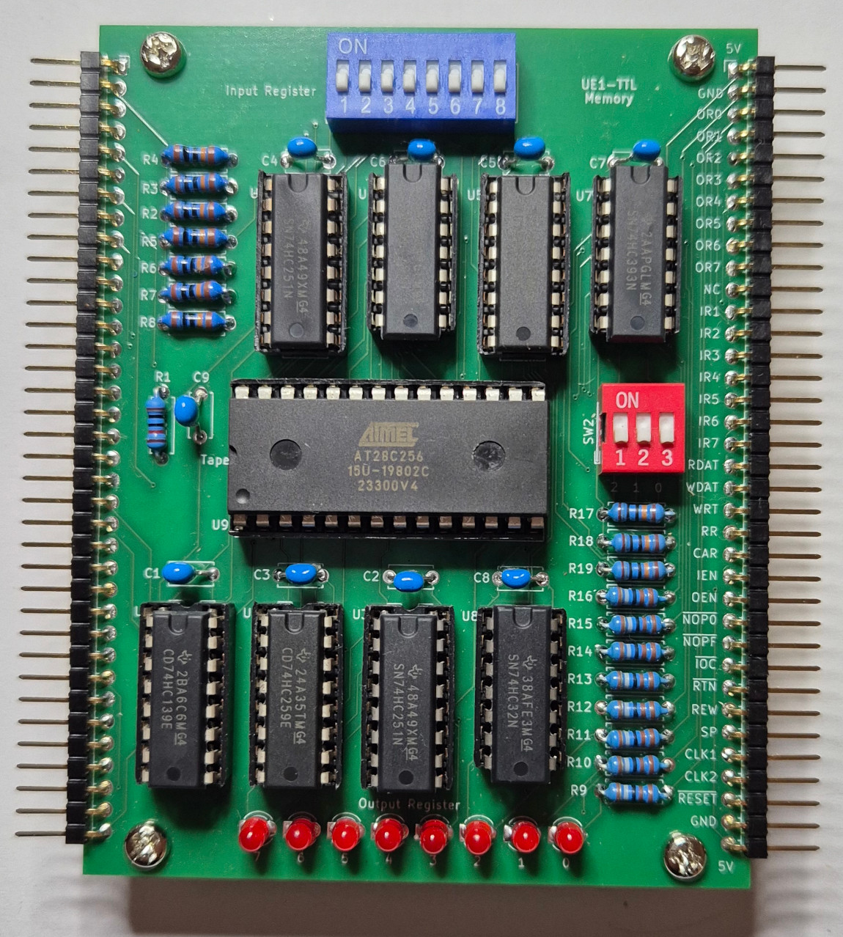
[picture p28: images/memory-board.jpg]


Note: Build the [clock board](testing_clock.md) and
[processor board](testing_processor.md) first.

## Parts

* 1 x AT28C256 32K x 8 EEPROM
* 1 x 74LS32 quad OR gate
* 1 x 74LS139 dual 2-to-4 line decoder
* 2 x 74LS251 8-line to 1-line multiplexer
* 2 x 74LS259 8-bit addressable latch
* 2 x 74LS393 dual binary 4-bit counter
* 9 x 100nF ceramic or monolithic capacitor
* 1 x 10K resistor
* 10 x 100K resistor
* 8 x RLED resistor (choose to suit the properties of the LED's)
* 8 x 3mm LED (colour of your choice)
* 1 x 8-way DIP switches
* 1 x 3-way DIP switches
* 2 x 36-pin right-angle terminal header
* 3 x 14-pin DIP socket
* 5 x 16-pin DIP socket
* 1 x 28-pin DIP socket (15.24mm pitch width)

The IC's are listed as 74LS series, but you can use 74HC series instead.
Use the same series for all chips.

I recommend using a socket for the 28-pin EEPROM even if you don't use
sockets for the other chips.  You will need to easily remove the EEPROM to
reprogram it.

## Assembling

Start in the usual way with the low profile components and work up in height:

* Resistors
* Pin headers along the left and right edges
* LED's
* IC sockets
* Capacitors, which are all 100nF
* DIP switches

Do a quick test with a multimeter to make sure there is no short
between 5V and ground.  Then insert the IC's into the sockets:

* U1 - 74LS139
* U2 - 74LS259
* U3 - 74LS251
* U4 - 74LS251
* U5 - 74LS259
* U6 - 74LS393
* U7 - 74LS393
* U8 - 73LS32
* U9 - AT28C256

## Testing

Connect the clock, processor, and memory boards together.  The processor
board goes in the middle.

Burn a 32K x 8 EEPROM with the contents of the "UE1TEST.ROM" file in the
"programs" directory of this repository.

Select program 0 on the three DIP switches on the right of the memory
board.  Then turn the computer on.  Press the RUN button and the program
should start running.

Program 0 of the test image is Usagi Electric's classic "UE1FIBO"
example, which calculates Fibonacci up to 21.  You should see the
output register LED's count 1, 2, 3, 5, 8, 13, and then 21.  The
program should then ring the bell and halt.

If this doesn't work, then you will probably need to get the oscilloscope
out and debug it.

If it does work, then select program 2, press RESET and then RUN.
This runs the "UE1 DIAPER1" test program, which tests the entire
instruction set of the UE1 looking for faults.  See the source file
"programs/UE1\_DIAPER1\_V2.ASM" for instructions.

If "UE1 DIAPER1" passes, then select program 3, press RESET and then RUN.
This is the "UE1 DIAPER2" program which tests inputs and outputs.
The values on input switches IR1 to IR7 are copied to OR1 to OR7 every
loop iteration.  OR0 will be set to the even parity of the other 7 bits.

If programs 0, 2, and 3 all work, then congratulations!  You have a
working computer!

## Version 1 mistakes

There is a minor issue with the "rewind" instruction which isn't fatal.
If the second instruction after a SKZ involves a memory address with
bit 3 set, an extra skip might occur.  This is due to clock glitches in the
generation of the rewind signal.

For most code, this isn't an issue.  It is usually possible to modify the
code to work around it.  Either by modifying the problematic instruction
to use a different memory address, or by inserting extra "NOP0 SR0"
instructions.  Here is an example:

    SKZ RR
    NOPF SR0
    ONE RR      ; Problem happens here, use "ONE SR0" instead.

If modifying the code is not possible, then pull U8 out of its socket
and short pins 8 and 9 together.  This will disable the "rewind"
instruction entirely.

I haven't created a version 2 of the memory board yet, because the
rewind issue is fairly minor.

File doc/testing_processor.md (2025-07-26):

Assembling and Testing the Processor Board
==========================================

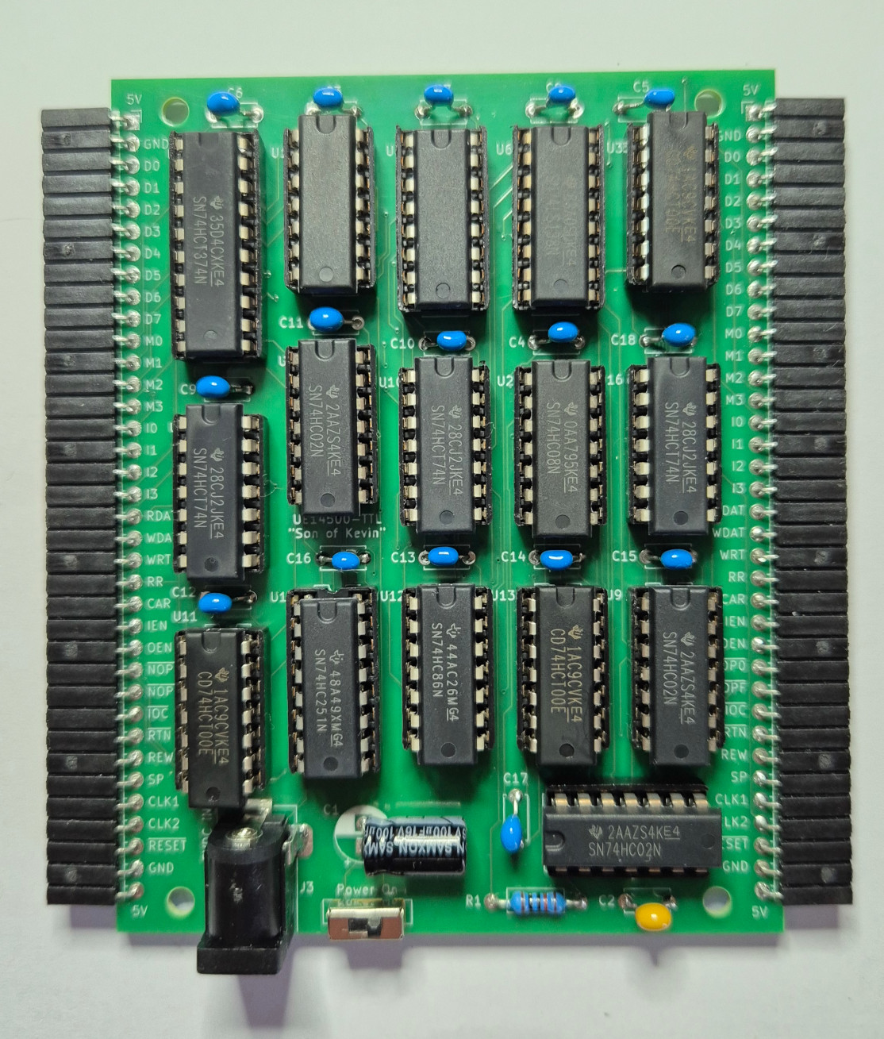
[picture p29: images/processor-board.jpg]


Note: Build the [clock board](testing_clock.md) first.

## Parts

* 3 x 74LS00 quad NAND gate
* 3 x 74LS02 quad NOR gate
* 2 x 74LS08 quad AND gate
* 3 x 74LS74 dual D flip-flop
* 1 x 74LS86 quad XOR gate
* 2 x 74LS138 3-to-8 line decoder
* 1 x 74LS251 8-line to 1-line multiplexer
* 1 x 74LS374 8-bit register
* 1 x 100uF electrolytic capacitor
* 1 x 1uF ceramic or monolithic capacitor
* 16 x 100nF ceramic or monolithic capacitor
* 1 x 10K resistor
* 1 x SPDT 2.54mm slide switch
* 1 x 2.5mm DC barrel jack
* 2 x 36-pin right-angle terminal socket
* 12 x 14-pin DIP socket
* 3 x 16-pin DIP socket
* 1 x 20-pin DIP socket

The IC's are listed as 74LS series, but you can use 74HC series instead.
Use the same series for all chips.

## Assembling

Start in the usual way with the low profile components and work up in height:

* 10K resistor R1
* Pin sockets along the left and right edges
* IC sockets
* Capacitors; C1 is 100uF electrolytic, C2 is 1uF, all others are 100nF.
* SPDT slide switch
* 2.5mm DC barrel jack

Do a quick test with a multimeter to make sure there is no short
between 5V and ground.  Then insert the IC's into the sockets:

* U1 - 74LS08
* U2 - 74LS08
* U3 - 74LS00
* U4 - 74LS374
* U5 - 74LS138
* U6 - 74LS138
* U7 - 74LS74
* U8 - 74LS02
* U9 - 74LS02
* U10 - 74LS74
* U11 - 74LS00
* U12 - 74LS86
* U13 - 74LS00
* U14 - 74LS251
* U15 - 74LS02
* U16 - 74LS74

## Testing

Make sure the power switch is in the right position and then power on the
board on its own with a bench power supply set to 5V.  The current draw
should be in the tens of milliamps at most.

Power off the board and connect it to the clock board.  Then re-power
the two boards together.

Some of the lights should turn on.  The instruction will be random
because the memory board is not connected.  Press and hold the RUN button
and the LED's should blink like crazy.  When you release the button
the machine will probably halt with NOPF set.  It may run for a while
on random instructions.

Press the RESET button.  RR and CAR should turn off.  IEN and OEN should
turn on.  This should confirm that the processor is basically working.
We will need memory to test anything else.

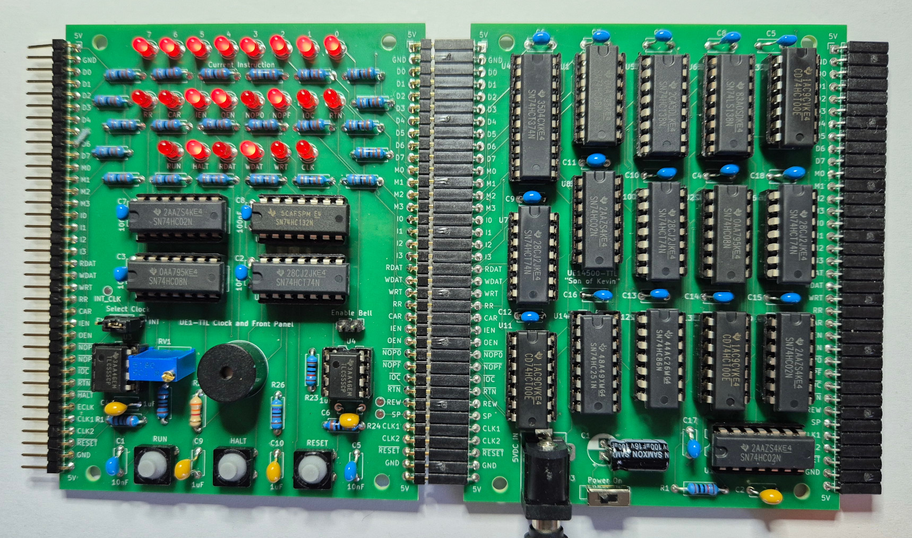
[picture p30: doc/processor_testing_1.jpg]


Next: [Assembling and testing the memory board](testing_memory.md).

## Version 1 mistakes

I made a mistake in the generation of the WRITE signal.  I was gating it
based on CLK1 to trigger memory writes on the falling edge of CLK1:

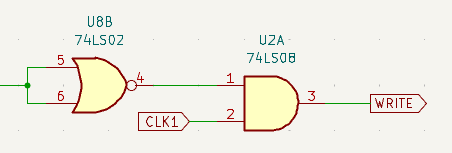
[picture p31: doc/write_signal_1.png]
Write Signal Version 1


However, this could cause invalid data to be written to memory when the next
instruction was loaded on the following CLK1 rising edge.  Moving WRITE
to CLK2 fixes the problem:

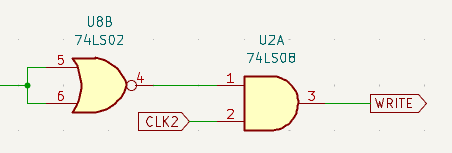
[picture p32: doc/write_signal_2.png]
Write Signal Version 2


This is fixed in the schematic and gerbers for version 2 of the processor board.

As a consequence of moving the WRITE signal to the falling edge of CLK2,
the SKZ instruction stopped working.  The SKIP state could reset
mid-instruction, causing the current skipped instruction to "un-skip".

This is the original skip circuit:

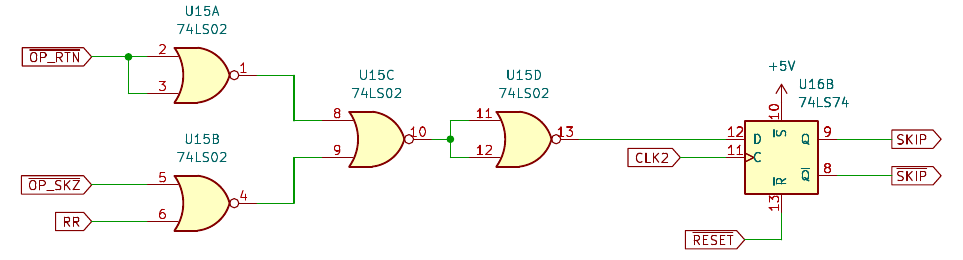
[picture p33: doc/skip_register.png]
Skip Register Version 1


And this is the updated version, which "double-buffers" the SKIP value:

Skip Register Version 2

The SKIP register is updated on the rising edge of CLK2 as before,
but the value does not become active until the rising edge of CLK1
during the next instruction.  This avoids an "un-skip" occurring in
the middle of an instruction.

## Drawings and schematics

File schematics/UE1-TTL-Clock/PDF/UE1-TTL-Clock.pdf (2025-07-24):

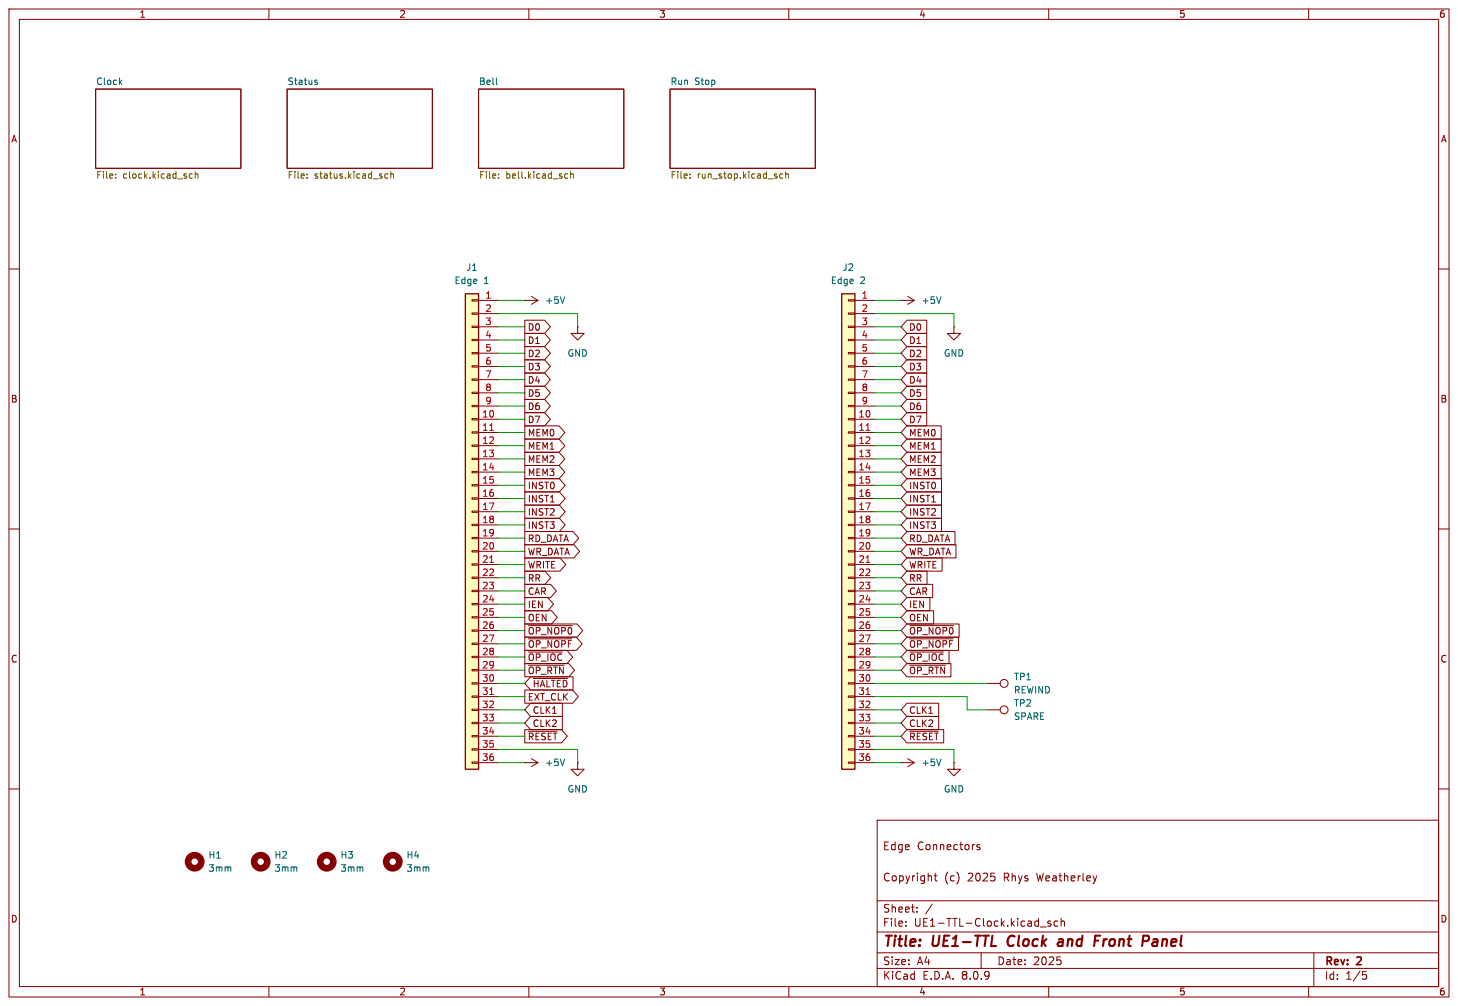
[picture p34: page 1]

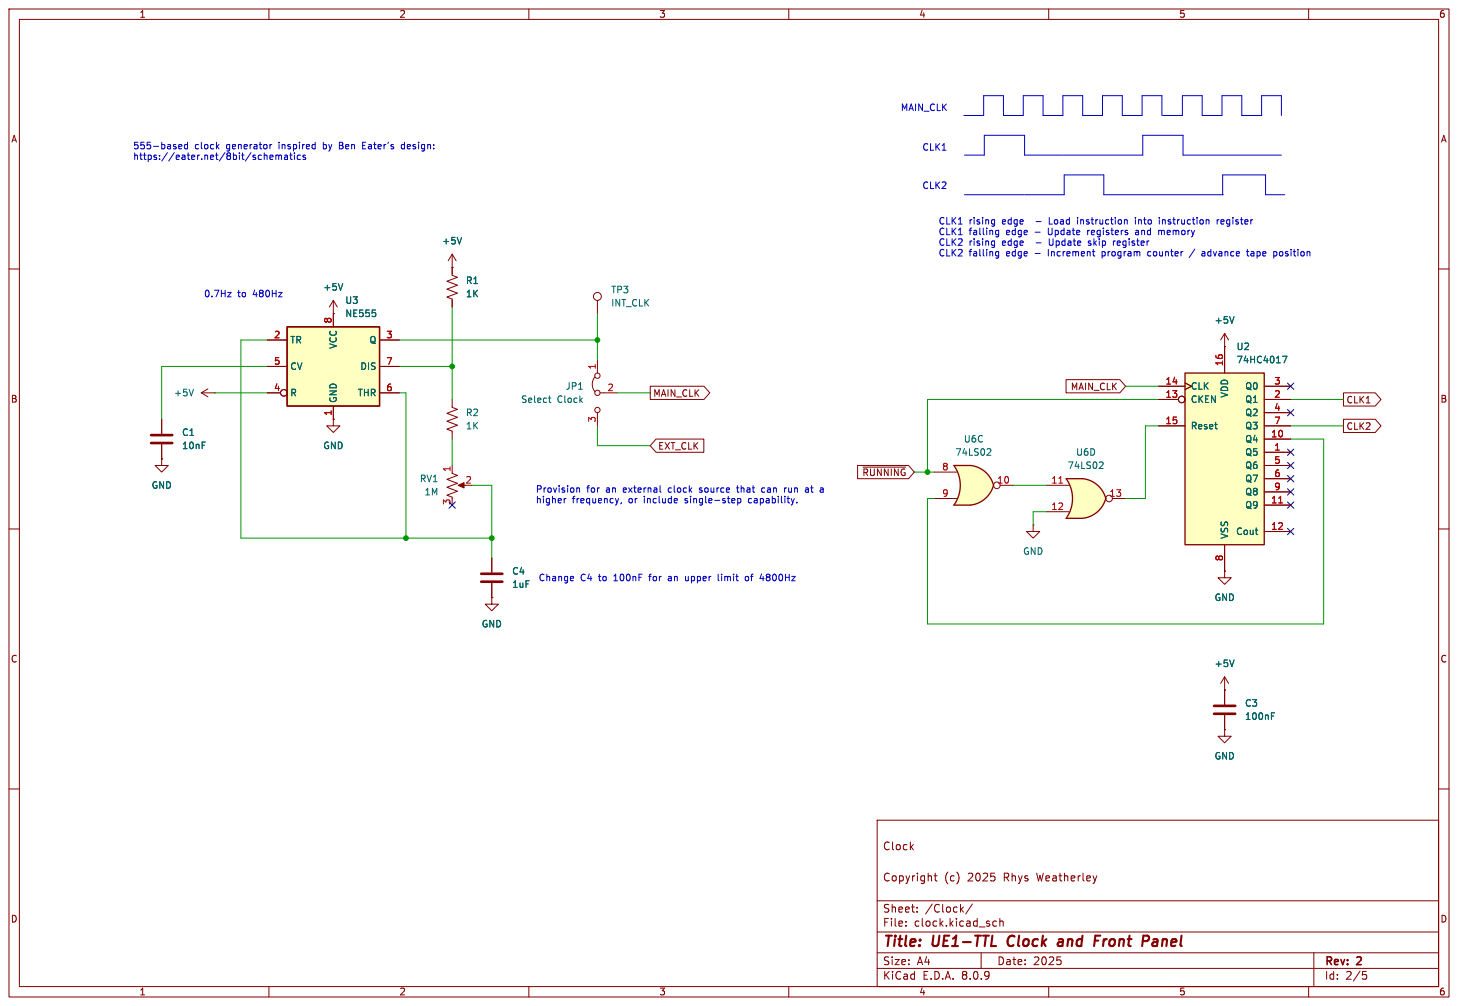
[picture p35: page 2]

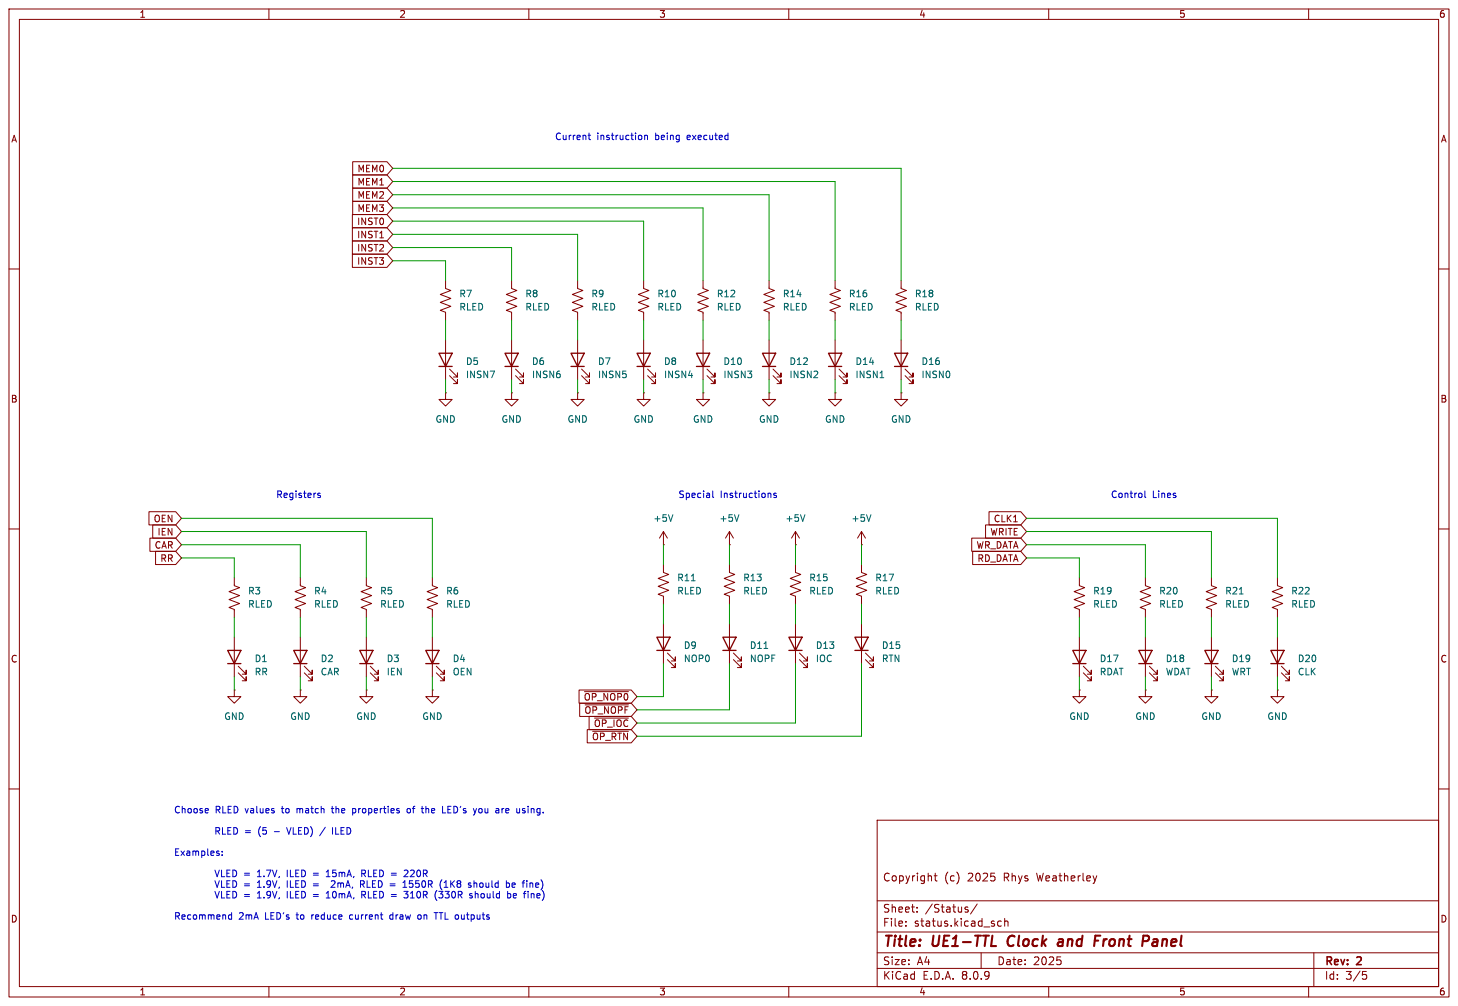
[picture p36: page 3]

Examples: VLED = 1.7V, ILED = 15mA, RLED = 220R

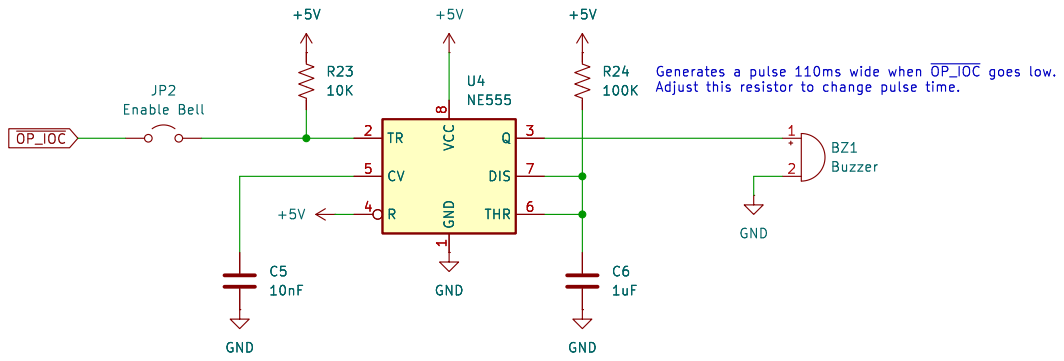
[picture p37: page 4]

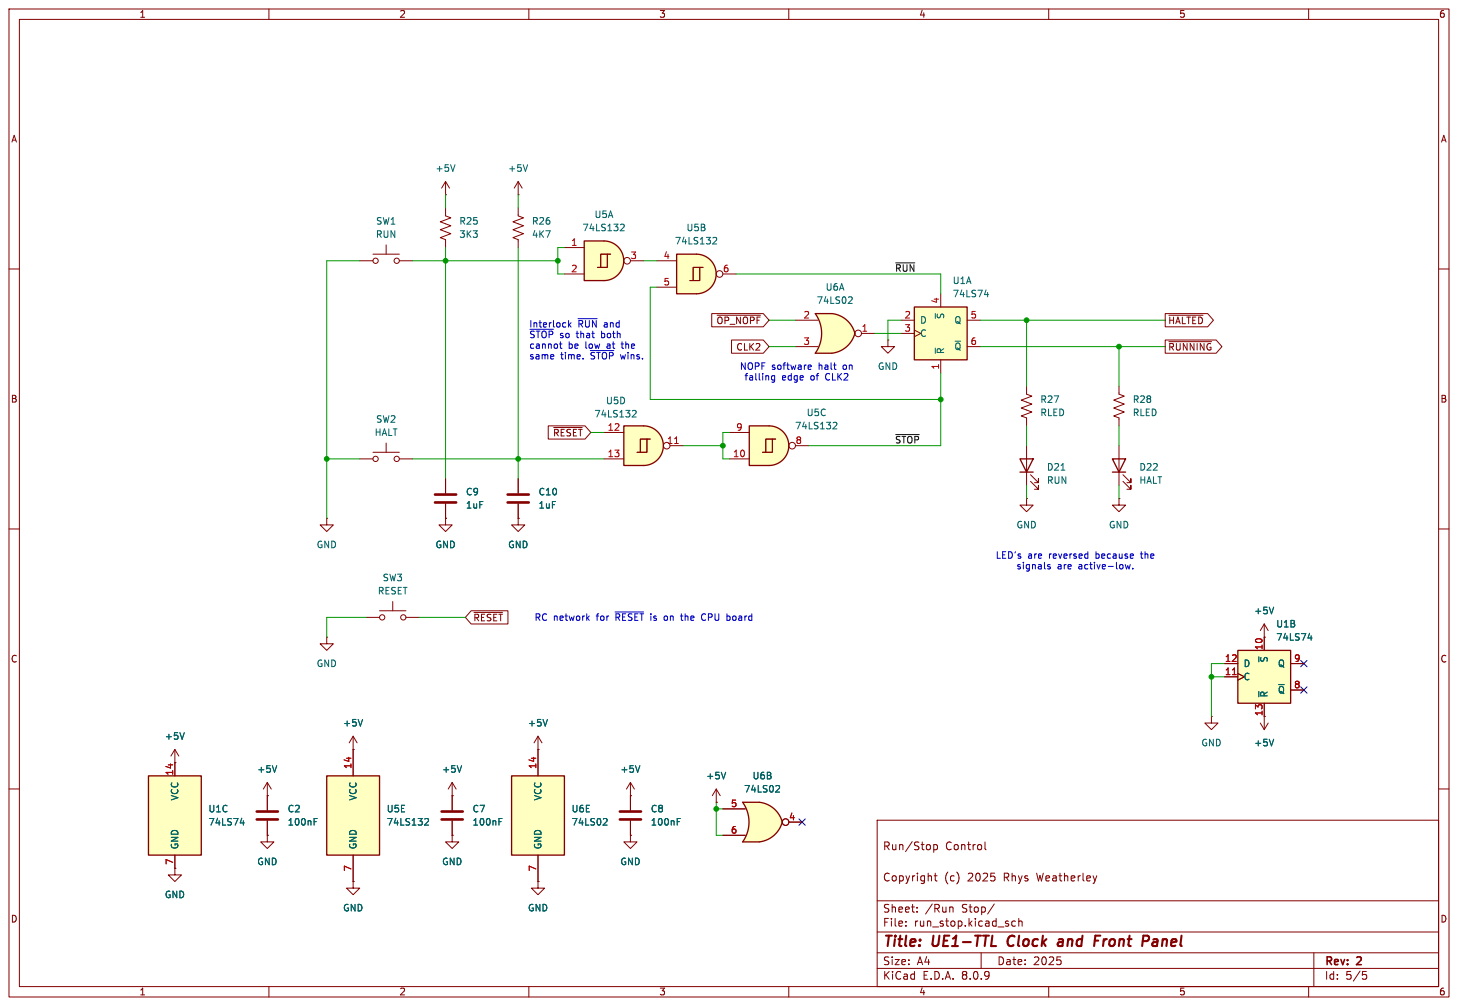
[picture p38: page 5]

cannot be low at the

signals are active-low. NOPF software halt on

Id: 5/5 Title: UE1-TTL Clock and Front Panel File: run_stop.kicad_sch Sheet: /Run Stop/

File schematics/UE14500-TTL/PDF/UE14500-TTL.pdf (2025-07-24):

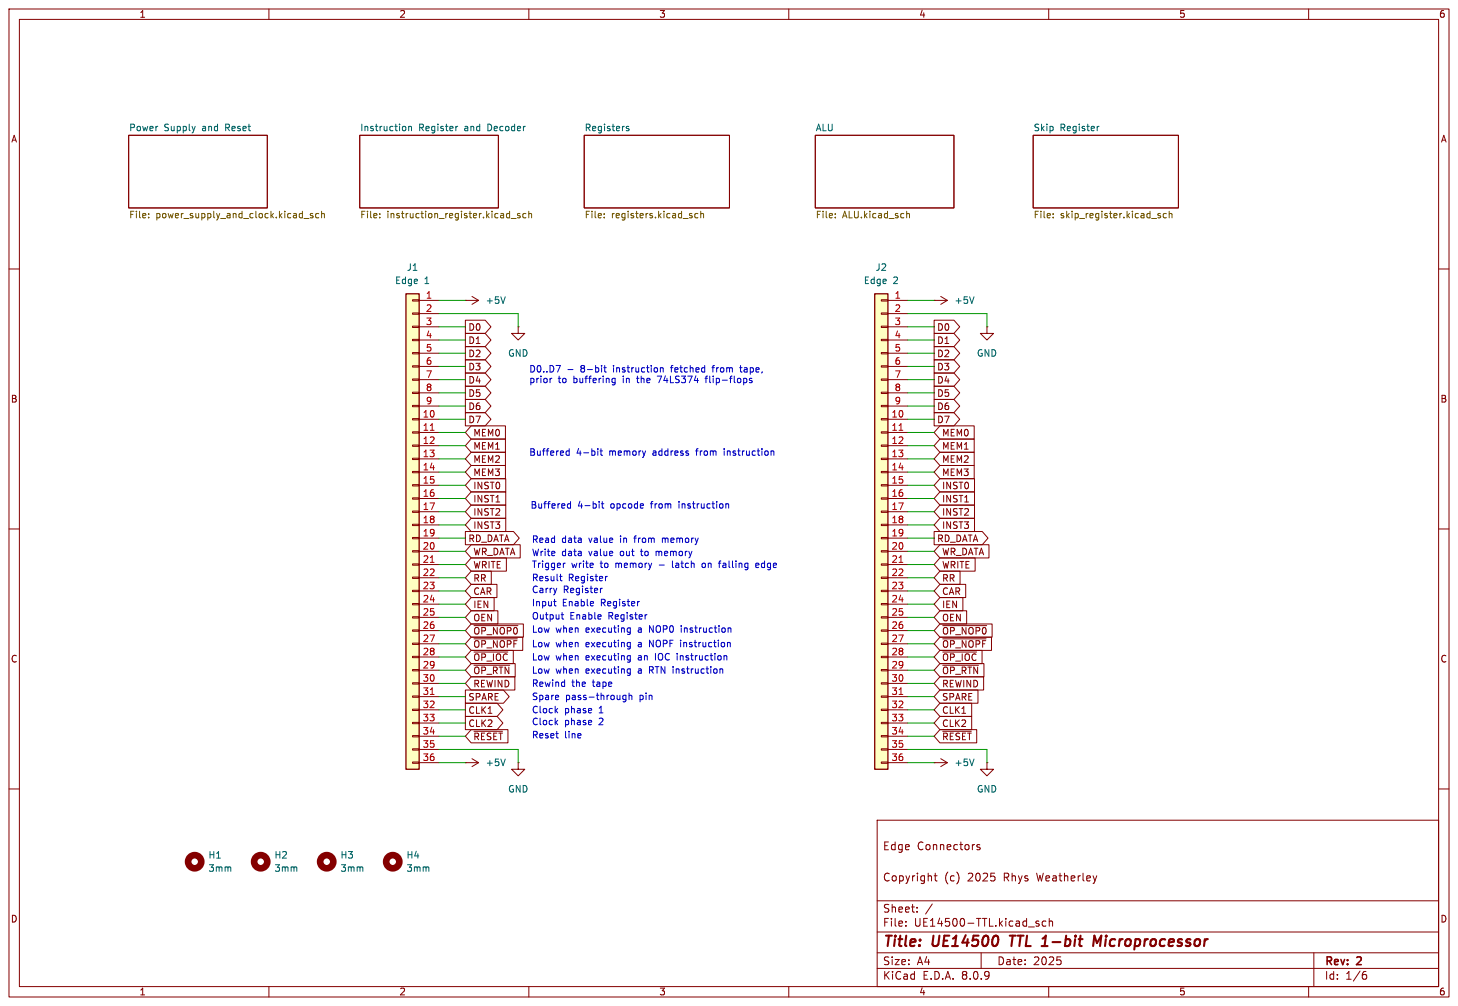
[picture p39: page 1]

Power Supply and Reset File: power_supply_and_clock.kicad_sch

Skip Register File: skip_register.kicad_sch ALU

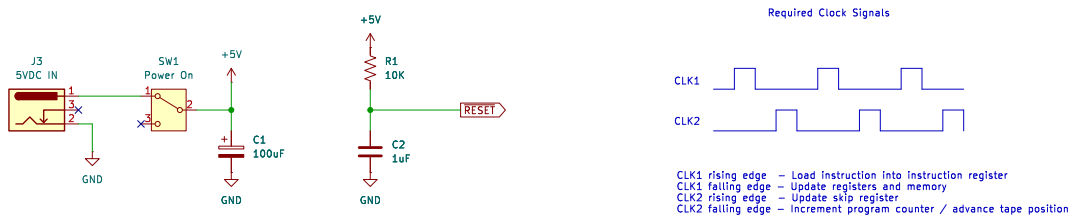
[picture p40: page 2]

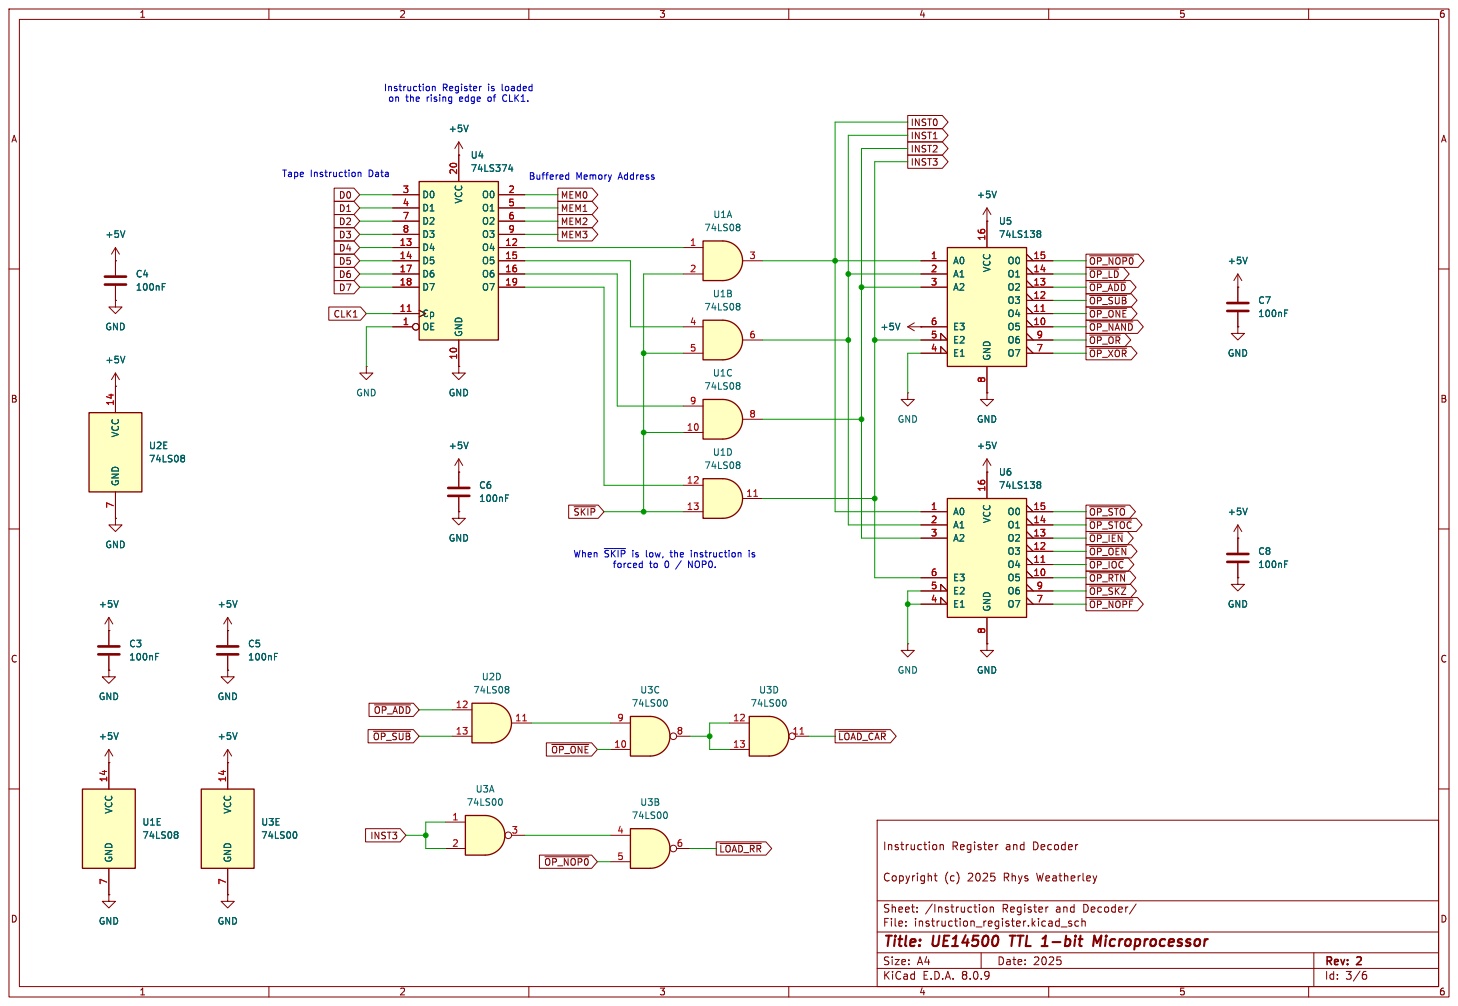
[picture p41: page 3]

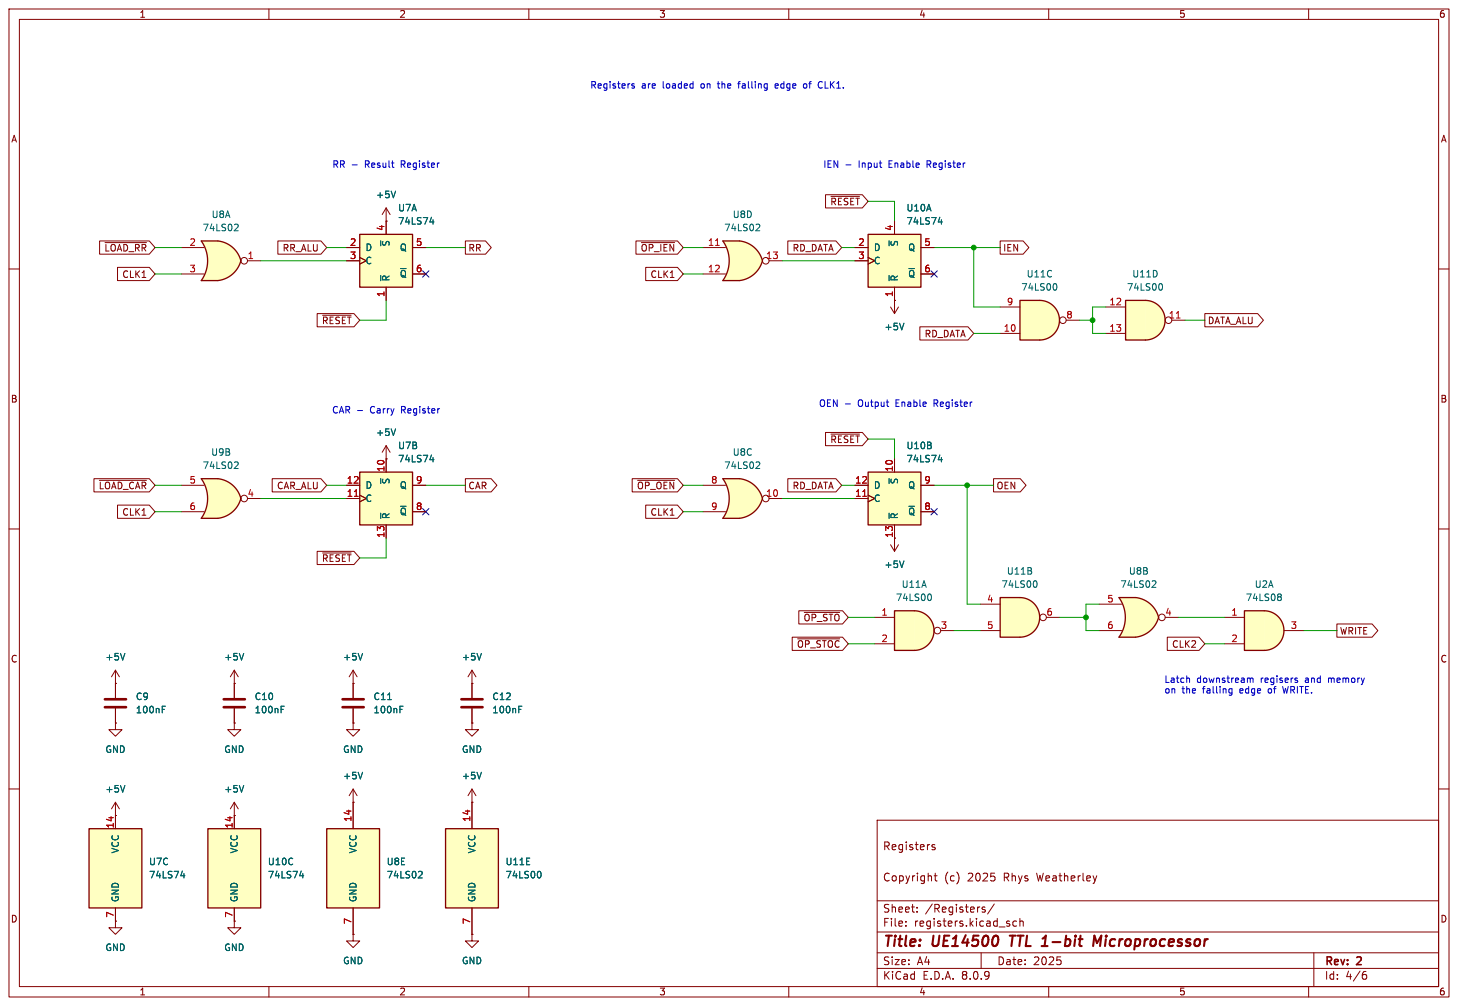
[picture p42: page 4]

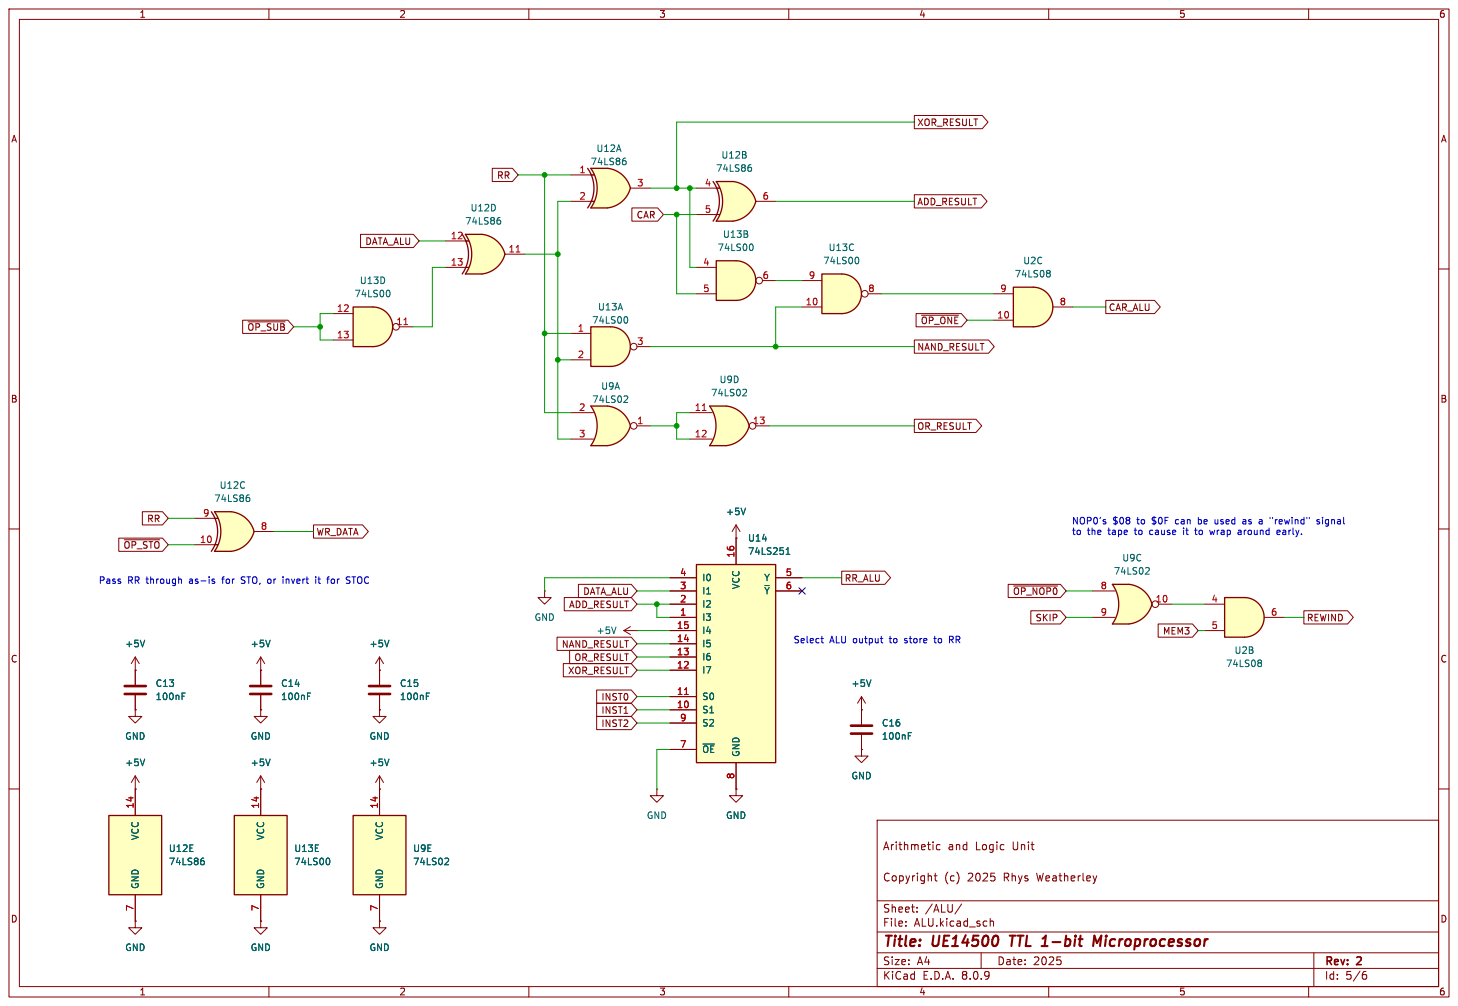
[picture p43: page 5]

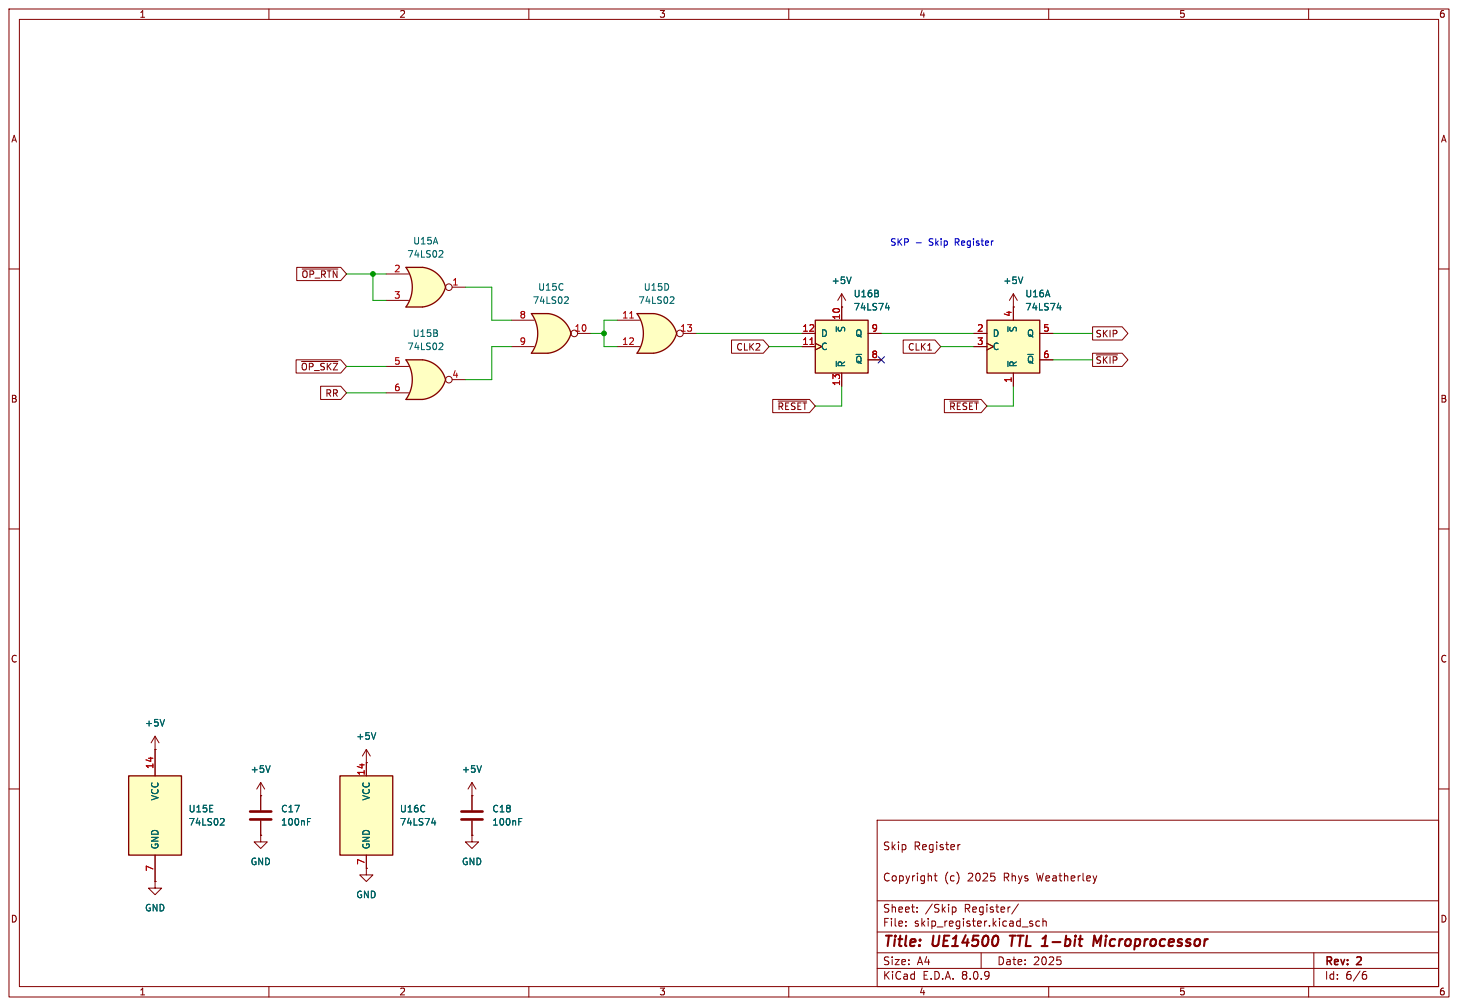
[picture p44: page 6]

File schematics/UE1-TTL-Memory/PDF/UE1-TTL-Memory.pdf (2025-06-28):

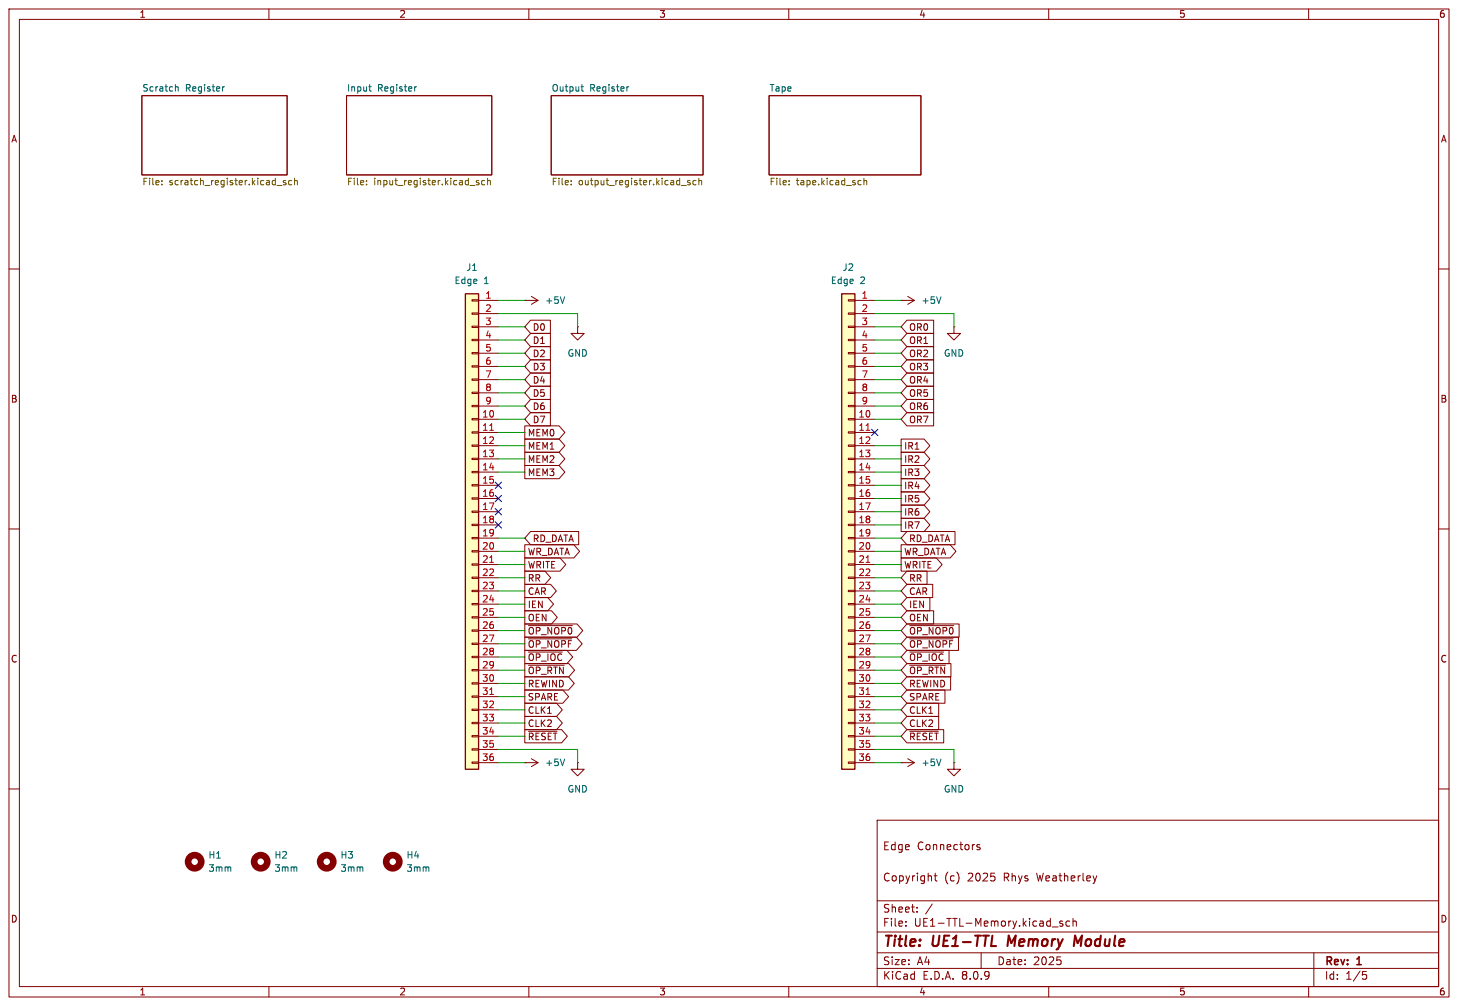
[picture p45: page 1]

Id: 1/5 Title: UE1-TTL Memory Module


Id: 2/5 Title: UE1-TTL Memory Module


Id: 3/5 Title: UE1-TTL Memory Module


Examples: VLED = 1.7V, ILED = 15mA, RLED = 220R

Id: 4/5 Title: UE1-TTL Memory Module


File: tape.kicad_sch Sheet: /Tape/
Id: 5/5 Title: UE1-TTL Memory Module

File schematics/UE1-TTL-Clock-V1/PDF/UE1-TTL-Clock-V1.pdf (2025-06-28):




Examples: VLED = 1.7V, ILED = 15mA, RLED = 220R



cannot be low at the

signals are active-low. GND

LED's are reversed because the

Id: 5/5 Title: UE1-TTL Clock and Front Panel File: run_stop.kicad_sch Sheet: /Run Stop/

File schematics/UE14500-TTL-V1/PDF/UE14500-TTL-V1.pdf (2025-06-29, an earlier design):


Power Supply and Reset File: power_supply_and_clock.kicad_sch

Skip Register File: skip_register.kicad_sch ALU






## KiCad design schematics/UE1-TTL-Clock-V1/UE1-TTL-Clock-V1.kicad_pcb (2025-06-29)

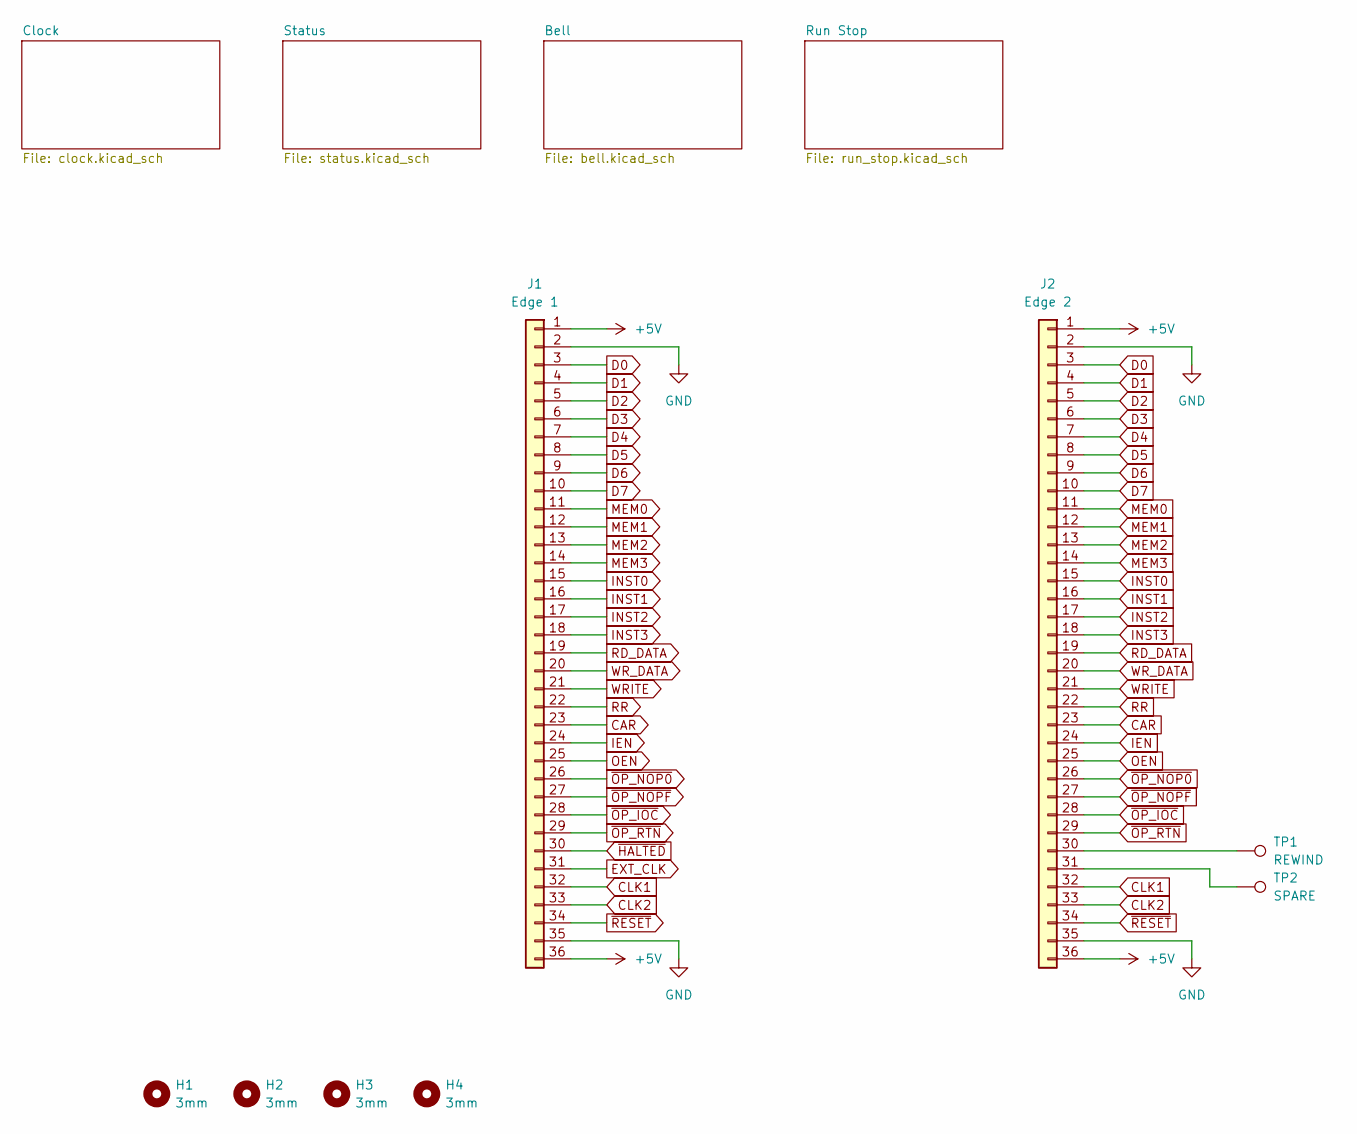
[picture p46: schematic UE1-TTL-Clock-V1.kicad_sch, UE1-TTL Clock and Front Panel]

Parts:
H1, H2, H3, H4: 3mm; MountingHole_3mm
J1: Edge 1; PinSocket_1x36_P2.54mm_Horizontal
J2: Edge 2; PinHeader_1x36_P2.54mm_Horizontal
TP1: REWIND; TestPoint_Pad_D1.5mm
TP2: SPARE; TestPoint_Pad_D1.5mm

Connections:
+5V: J1.1, J1.36, J2.1, J2.36; also elsewhere on the board
CAR: J1.23, J2.23; also elsewhere on the board
CLK1: J1.32, J2.32; also elsewhere on the board
CLK2: J1.33, J2.33; also elsewhere on the board
D0: J1.3, J2.3
D1: J1.4, J2.4
D2: J1.5, J2.5
D3: J1.6, J2.6
D4: J1.7, J2.7
D5: J1.8, J2.8
D6: J1.9, J2.9
D7: J1.10, J2.10
EXT_CLK: J1.31; also elsewhere on the board
GND: J1.2, J1.35, J2.2, J2.35; also elsewhere on the board
IEN: J1.24, J2.24; also elsewhere on the board
INST0: J1.15, J2.15; also elsewhere on the board
INST1: J1.16, J2.16; also elsewhere on the board
INST2: J1.17, J2.17; also elsewhere on the board
INST3: J1.18, J2.18; also elsewhere on the board
MEM0: J1.11, J2.11; also elsewhere on the board
MEM1: J1.12, J2.12; also elsewhere on the board
MEM2: J1.13, J2.13; also elsewhere on the board
MEM3: J1.14, J2.14; also elsewhere on the board
unnamed: J2.30, TP1.1
unnamed: J2.31, TP2.1
OEN: J1.25, J2.25; also elsewhere on the board
RD_DATA: J1.19, J2.19; also elsewhere on the board
RR: J1.22, J2.22; also elsewhere on the board
WRITE: J1.21, J2.21; also elsewhere on the board
WR_DATA: J1.20, J2.20; also elsewhere on the board
~HALTED: J1.30; also elsewhere on the board
~OP_IOC: J1.28, J2.28; also elsewhere on the board
~OP_NOP0: J1.26, J2.26; also elsewhere on the board
~OP_NOPF: J1.27, J2.27; also elsewhere on the board
~OP_RTN: J1.29, J2.29; also elsewhere on the board
~RESET: J1.34, J2.34; also elsewhere on the board

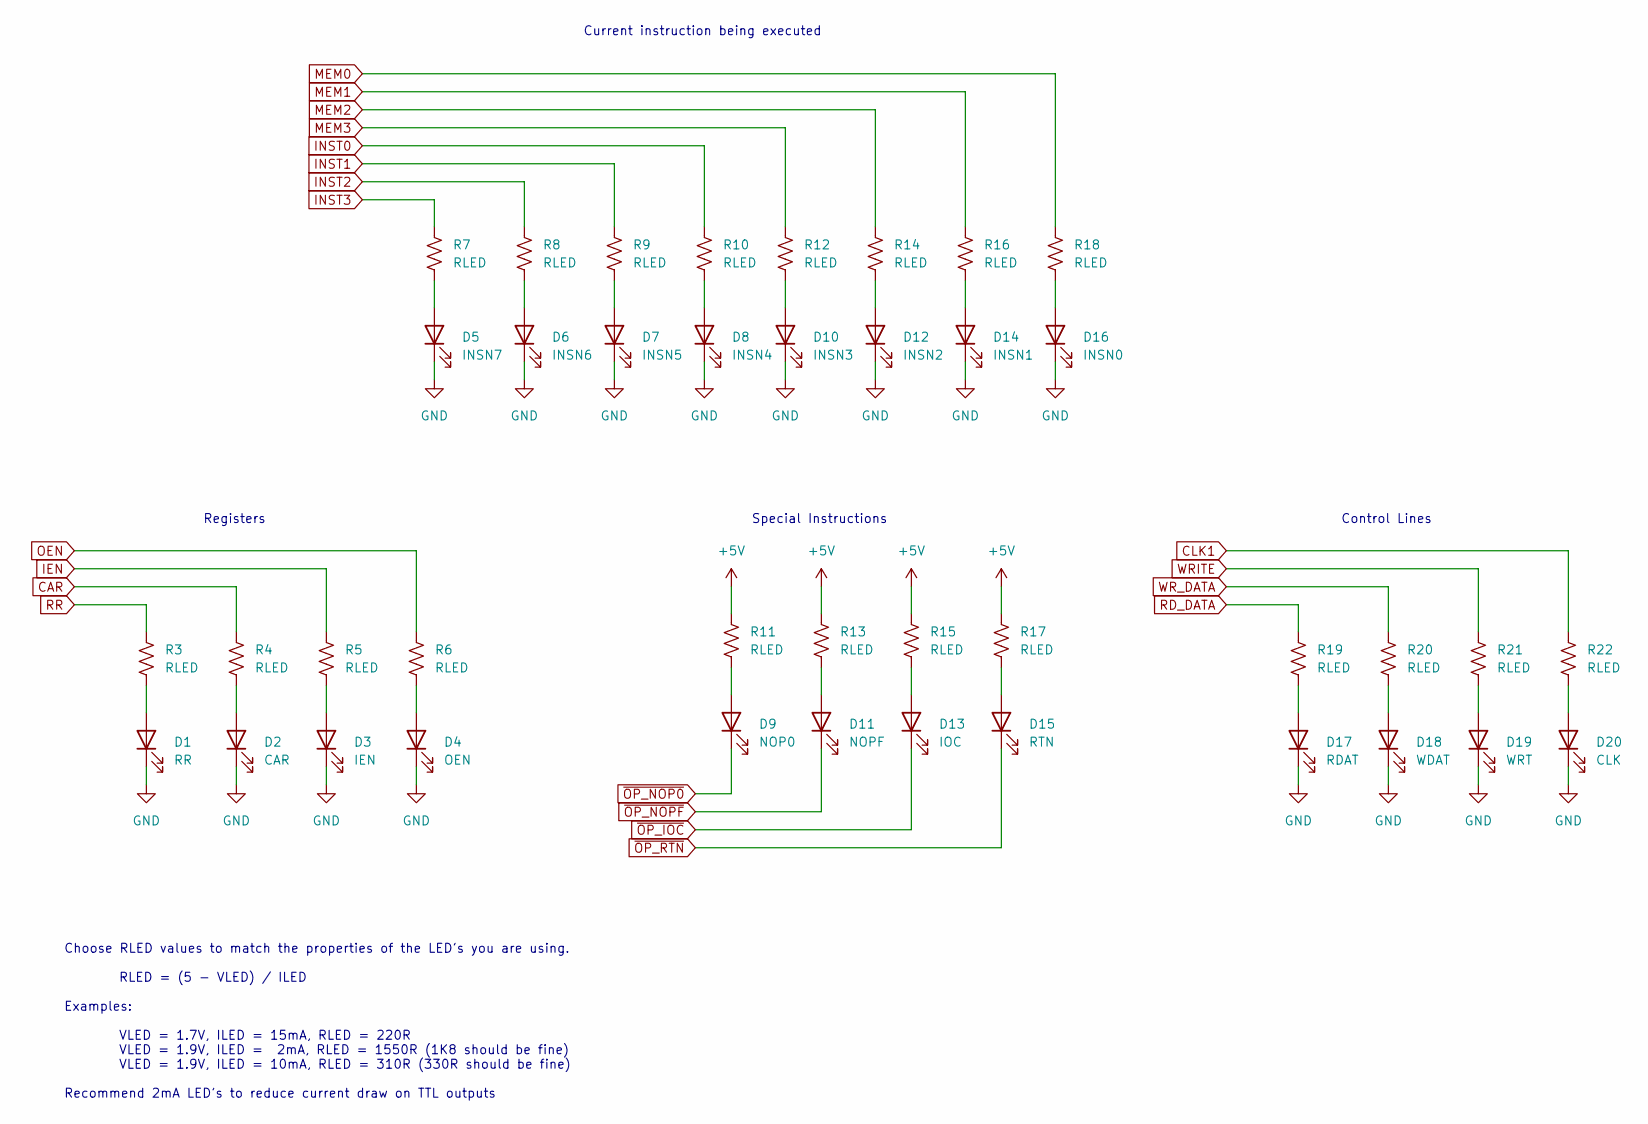
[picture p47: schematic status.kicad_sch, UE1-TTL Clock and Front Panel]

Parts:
D1: RR; LED_D3.0mm
D2: CAR; LED_D3.0mm
D3: IEN; LED_D3.0mm
D4: OEN; LED_D3.0mm
D5: INSN7; LED_D3.0mm
D6: INSN6; LED_D3.0mm
D7: INSN5; LED_D3.0mm
D8: INSN4; LED_D3.0mm
D9: NOP0; LED_D3.0mm
D10: INSN3; LED_D3.0mm
D11: NOPF; LED_D3.0mm
D12: INSN2; LED_D3.0mm
D13: IOC; LED_D3.0mm
D14: INSN1; LED_D3.0mm
D15: RTN; LED_D3.0mm
D16: INSN0; LED_D3.0mm
D17: RDAT; LED_D3.0mm
D18: WDAT; LED_D3.0mm
D19: WRT; LED_D3.0mm
D20: CLK; LED_D3.0mm
R3, R4, R5, R6, R7, R8, R9, R10, R11, R12, R13, R14, R15, R16, R17, R18, R19, R20, R21, R22: RLED; R_Axial_DIN0207_L6.3mm_D2.5mm_P7.62mm_Horizontal

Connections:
+5V: R11.1, R13.1, R15.1, R17.1; also elsewhere on the board
CAR: R4.1; also elsewhere on the board
CLK1: R22.1; also elsewhere on the board
GND: D1.1 (K), D2.1 (K), D3.1 (K), D4.1 (K), D5.1 (K), D6.1 (K), D7.1 (K), D8.1 (K), D10.1 (K), D12.1 (K), D14.1 (K), D16.1 (K), D17.1 (K), D18.1 (K), D19.1 (K), D20.1 (K); also elsewhere on the board
IEN: R5.1; also elsewhere on the board
INST0: R10.1; also elsewhere on the board
INST1: R9.1; also elsewhere on the board
INST2: R8.1; also elsewhere on the board
INST3: R7.1; also elsewhere on the board
MEM0: R18.1; also elsewhere on the board
MEM1: R16.1; also elsewhere on the board
MEM2: R14.1; also elsewhere on the board
MEM3: R12.1; also elsewhere on the board
unnamed: D1.2 (A), R3.2
unnamed: D2.2 (A), R4.2
unnamed: D3.2 (A), R5.2
unnamed: D4.2 (A), R6.2
unnamed: D5.2 (A), R7.2
unnamed: D6.2 (A), R8.2
unnamed: D7.2 (A), R9.2
unnamed: D8.2 (A), R10.2
unnamed: D9.2 (A), R11.2
unnamed: D10.2 (A), R12.2
unnamed: D11.2 (A), R13.2
unnamed: D12.2 (A), R14.2
unnamed: D13.2 (A), R15.2
unnamed: D14.2 (A), R16.2
unnamed: D15.2 (A), R17.2
unnamed: D16.2 (A), R18.2
unnamed: D17.2 (A), R19.2
unnamed: D18.2 (A), R20.2
unnamed: D19.2 (A), R21.2
unnamed: D20.2 (A), R22.2
OEN: R6.1; also elsewhere on the board
RD_DATA: R19.1; also elsewhere on the board
RR: R3.1; also elsewhere on the board
WRITE: R21.1; also elsewhere on the board
WR_DATA: R20.1; also elsewhere on the board
~OP_IOC: D13.1 (K); also elsewhere on the board
~OP_NOP0: D9.1 (K); also elsewhere on the board
~OP_NOPF: D11.1 (K); also elsewhere on the board
~OP_RTN: D15.1 (K); also elsewhere on the board

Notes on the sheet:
Choose RLED values to match the properties of the LED's you are using. RLED = (5 - VLED) / ILED Examples: VLED = 1.7V, ILED = 15mA, RLED = 220R VLED = 1.9V, ILED = 2mA, RLED = 1550R (1K8 should be fine) VLED = 1.9V, ILED = 10mA, RLED = 310R (330R should be fine) Recommend 2mA LED's to reduce curren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
Registers
Special Instructions
Control Lines
Current instruction being executed

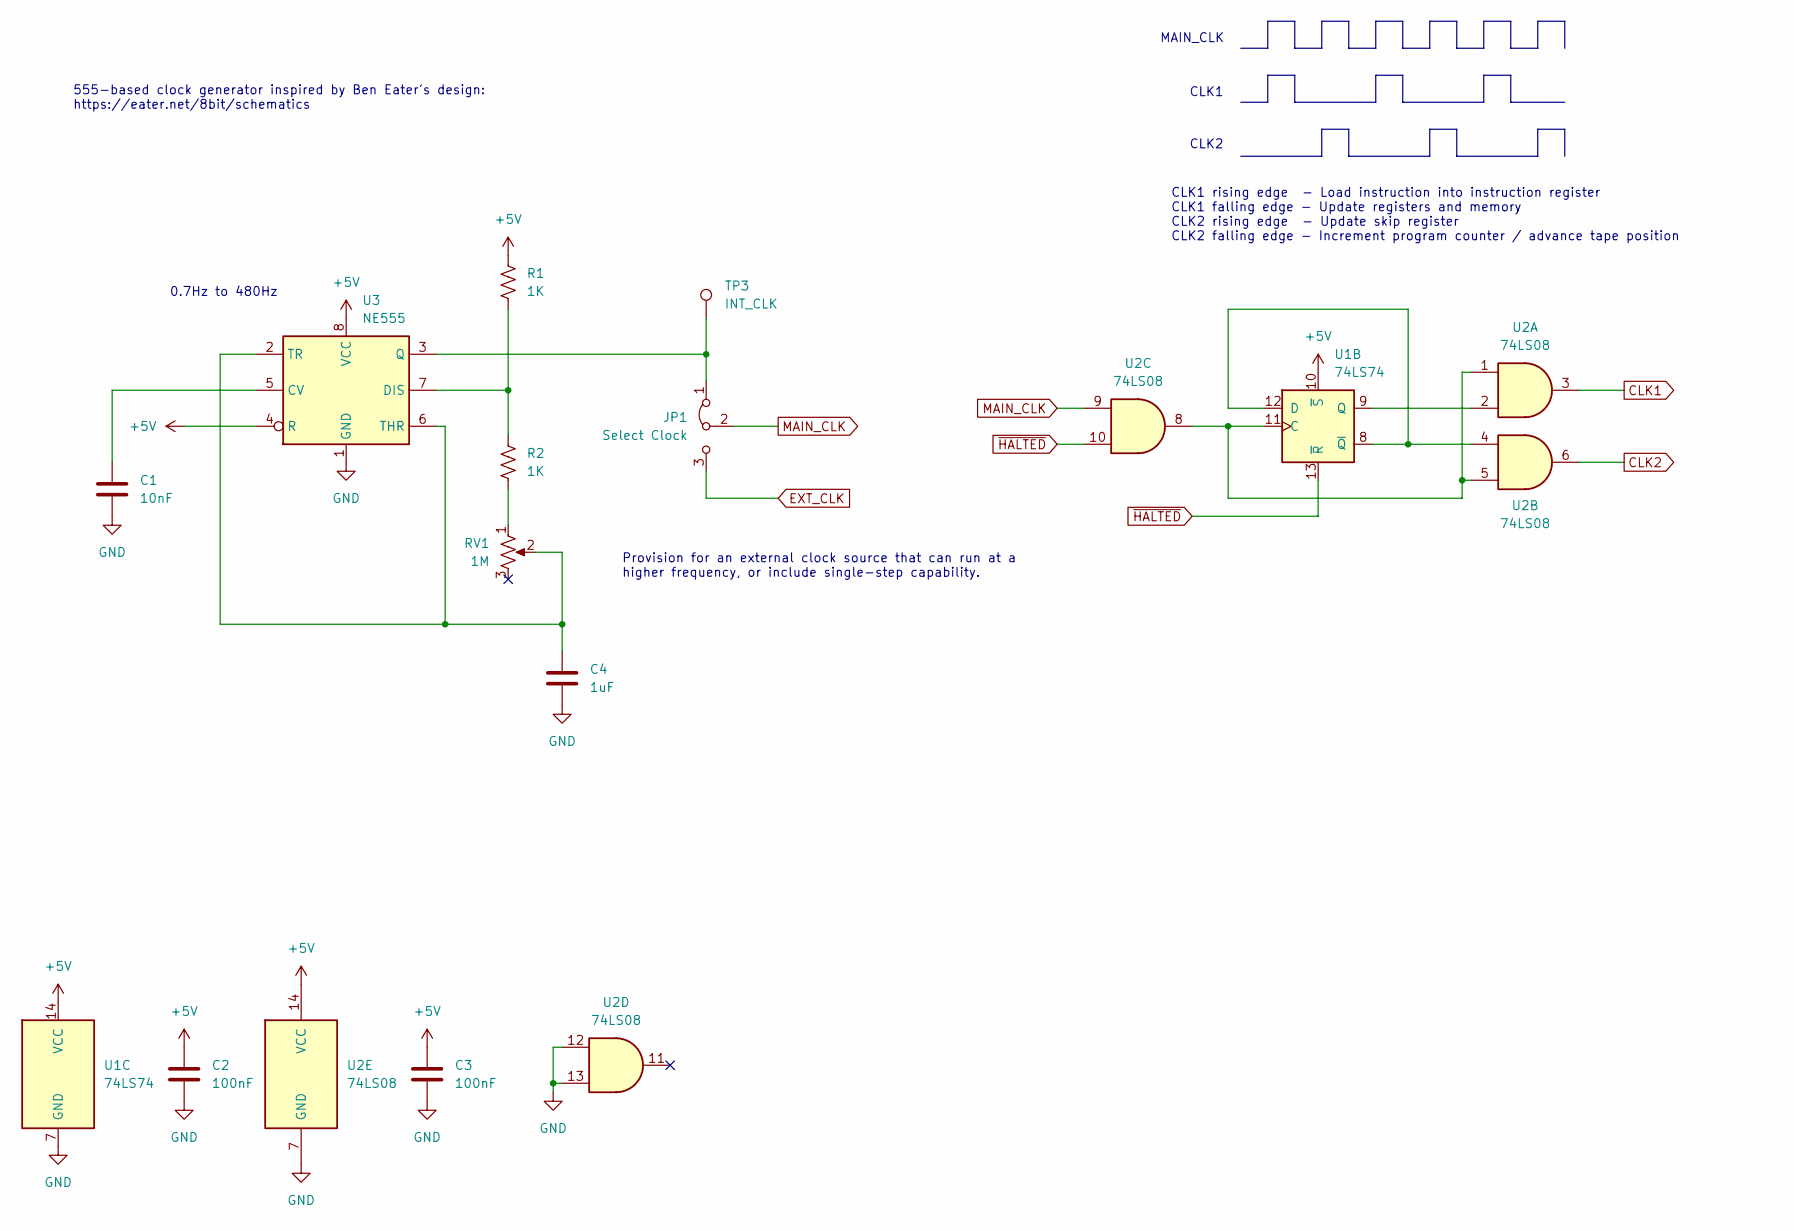
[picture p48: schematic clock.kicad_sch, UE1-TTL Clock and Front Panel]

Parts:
C1: 10nF; C_Disc_D5.0mm_W2.5mm_P5.00mm
C2, C3: 100nF; C_Disc_D5.0mm_W2.5mm_P5.00mm
C4: 1uF; C_Disc_D5.0mm_W2.5mm_P5.00mm
JP1: Select Clock; PinHeader_1x03_P2.54mm_Vertical
R1, R2: 1K; R_Axial_DIN0207_L6.3mm_D2.5mm_P7.62mm_Horizontal
RV1: 1M; Potentiometer_Bourns_3266Y_Vertical
TP3: INT_CLK; TestPoint_Pad_D1.5mm
U1: 74LS74; DIP-14_W7.62mm
U2: 74LS08; DIP-14_W7.62mm
U3: NE555; DIP-8_W7.62mm

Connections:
+5V: C2.1, C3.1, R1.1, U1.10 (~S), U1.14 (VCC), U2.14 (VCC), U3.4 (R), U3.8 (VCC); also elsewhere on the board
CLK1: U2.3; also elsewhere on the board
CLK2: U2.6; also elsewhere on the board
EXT_CLK: JP1.3 (B); also elsewhere on the board
GND: C1.2, C2.2, C3.2, C4.2, U1.7 (GND), U2.7 (GND), U2.12, U2.13, U3.1 (GND); also elsewhere on the board
MAIN_CLK: JP1.2 (C), U2.9
unnamed: JP1.1 (A), TP3.1, U3.3 (Q)
unnamed: R2.2, RV1.1
unnamed: U1.11 (C), U2.1, U2.5, U2.8
unnamed: U1.8 (~Q), U1.12 (D), U2.4
unnamed: U1.9 (Q), U2.2
unnamed: C1.1, U3.5 (CV)
unnamed: R1.2, R2.1, U3.7 (DIS)
unnamed: C4.1, RV1.2, U3.2 (TR), U3.6 (THR)
~HALTED: U1.13 (~R), U2.10; also elsewhere on the board

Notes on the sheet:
0.7Hz to 480Hz
Provision for an external clock source that can run at a higher frequency, or include single-step capability.
CLK1 rising edge - Load instruction into instruction register CLK1 falling edge - Update registers and memory CLK2 rising edge - Update skip register CLK2 falling edge - Increment program counter / advance tape position
555-based clock generator inspired by Ben Eater's design: https://eater.net/8bit/schematics
MAIN_CLK
CLK2
CLK1

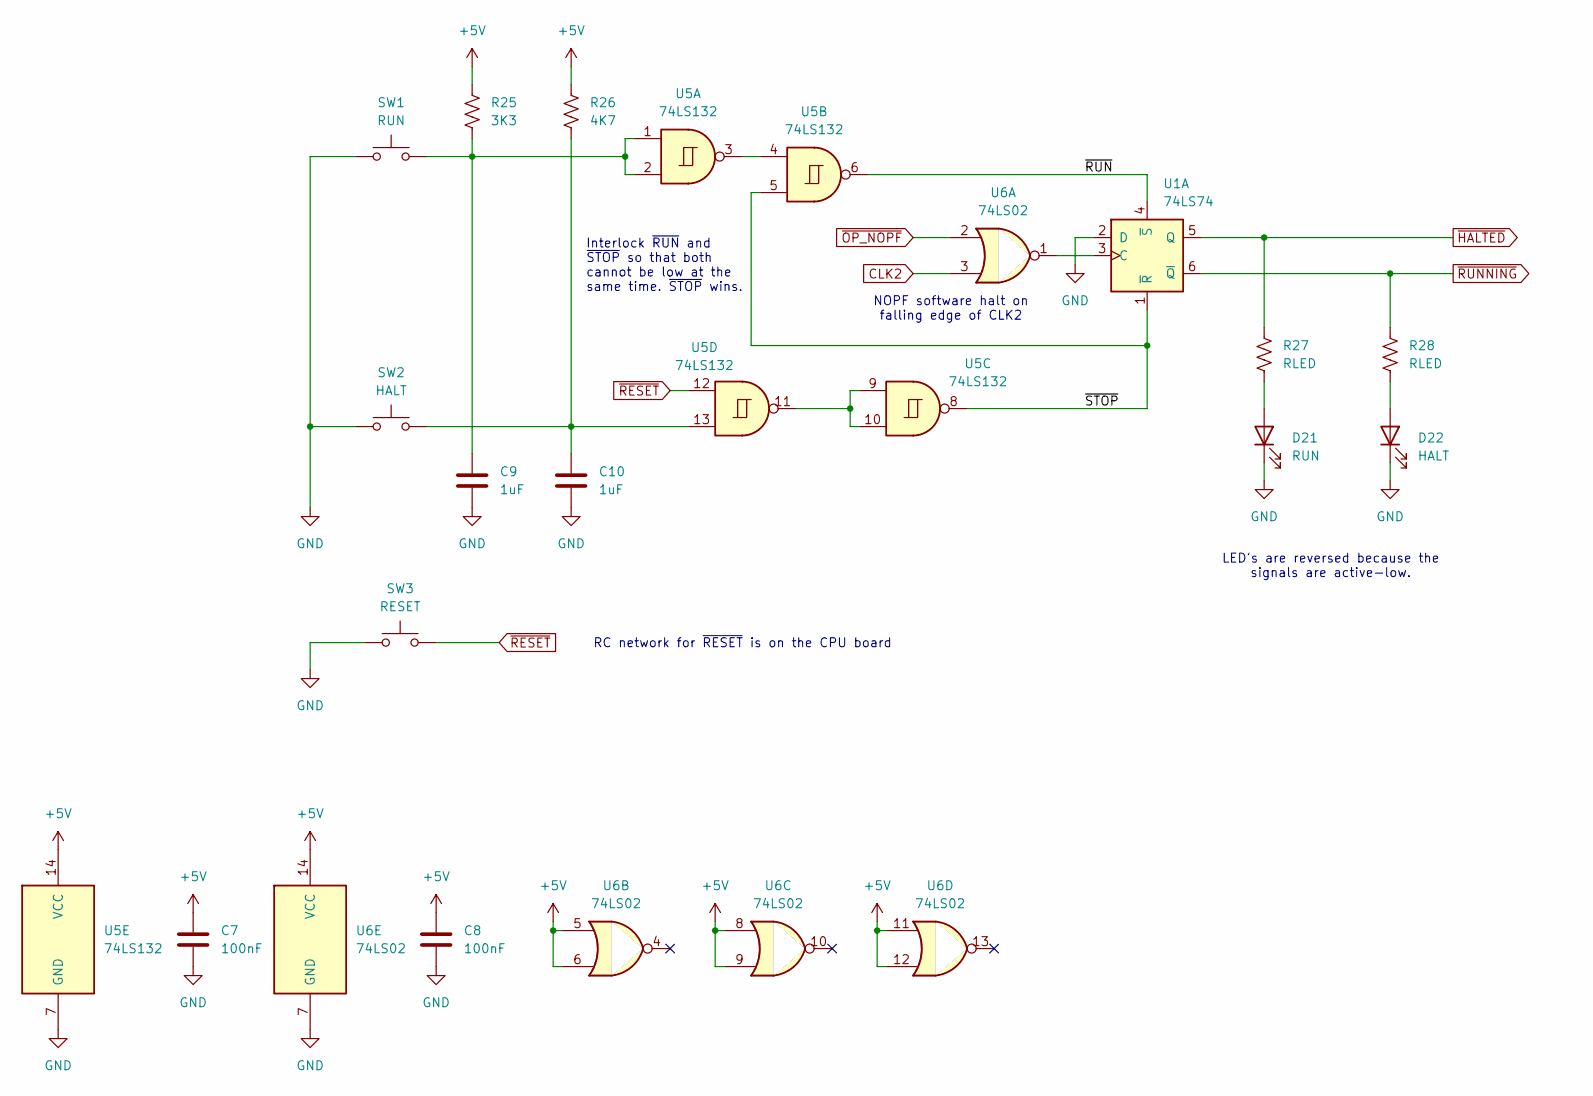
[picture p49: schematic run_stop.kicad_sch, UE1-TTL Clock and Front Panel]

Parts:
C7, C8: 100nF; C_Disc_D5.0mm_W2.5mm_P5.00mm
C9, C10: 1uF; C_Disc_D5.0mm_W2.5mm_P5.00mm
D21: RUN; LED_D3.0mm
D22: HALT; LED_D3.0mm
R25: 3K3; R_Axial_DIN0207_L6.3mm_D2.5mm_P7.62mm_Horizontal
R26: 4K7; R_Axial_DIN0207_L6.3mm_D2.5mm_P7.62mm_Horizontal
R27, R28: RLED; R_Axial_DIN0207_L6.3mm_D2.5mm_P7.62mm_Horizontal
SW1: RUN; SW_PUSH_6mm
SW2: HALT; SW_PUSH_6mm
SW3: RESET; SW_PUSH_6mm
U1: 74LS74; DIP-14_W7.62mm
U5: 74LS132; DIP-14_W7.62mm
U6: 74LS02; DIP-14_W7.62mm

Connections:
+5V: C7.1, C8.1, R25.1, R26.1, U5.14 (VCC), U6.5, U6.6, U6.8, U6.9, U6.11, U6.12, U6.14 (VCC); also elsewhere on the board
/Run Stop/~RUN: U1.4 (~S), U5.6
/Run Stop/~STOP: U1.1 (~R), U5.5, U5.8
CLK2: U6.3; also elsewhere on the board
GND: C7.2, C8.2, C9.2, C10.2, D21.1 (K), D22.1 (K), SW1.1, SW2.1, SW3.1, U1.2 (D), U5.7 (GND), U6.7 (GND); also elsewhere on the board
unnamed: C9.1, R25.2, SW1.2, U5.1, U5.2
unnamed: C10.1, R26.2, SW2.2, U5.13
unnamed: D21.2 (A), R27.2
unnamed: D22.2 (A), R28.2
unnamed: U1.3 (C), U6.1
unnamed: U5.3, U5.4
unnamed: U5.9, U5.10, U5.11
~HALTED: R27.1, U1.5 (Q); also elsewhere on the board
~OP_NOPF: U6.2; also elsewhere on the board
~RESET: SW3.2, U5.12; also elsewhere on the board
~RUNNING: R28.1, U1.6 (~Q)

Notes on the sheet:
RC network for ~{RESET} is on the CPU board
NOPF software halt on falling edge of CLK2
LED's are reversed because the signals are active-low.
Interlock ~{RUN} and ~{STOP} so that both cannot be low at the same time. ~{STOP} wins.

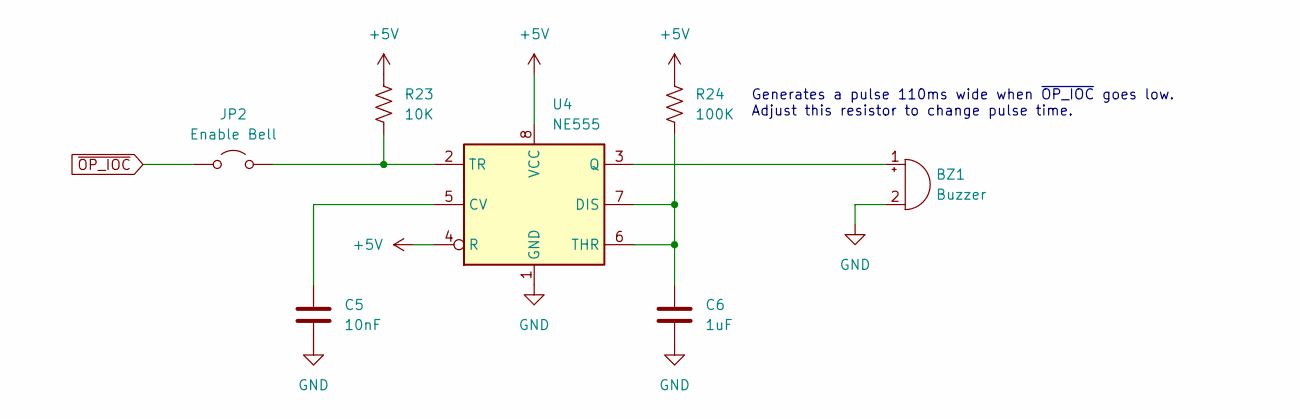
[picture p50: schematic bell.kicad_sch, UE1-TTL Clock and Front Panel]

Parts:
BZ1: Buzzer; Buzzer_12x9.5RM7.6
C5: 10nF; C_Disc_D5.0mm_W2.5mm_P5.00mm
C6: 1uF; C_Disc_D5.0mm_W2.5mm_P5.00mm
JP2: Enable Bell; PinHeader_1x02_P2.54mm_Vertical
R23: 10K; R_Axial_DIN0207_L6.3mm_D2.5mm_P7.62mm_Horizontal
R24: 100K; R_Axial_DIN0207_L6.3mm_D2.5mm_P7.62mm_Horizontal
U4: NE555; DIP-8_W7.62mm

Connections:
+5V: R23.1, R24.1, U4.4 (R), U4.8 (VCC); also elsewhere on the board
GND: BZ1.2 (-), C5.2, C6.2, U4.1 (GND); also elsewhere on the board
unnamed: BZ1.1 (+), U4.3 (Q)
unnamed: JP2.2 (B), R23.2, U4.2 (TR)
unnamed: C5.1, U4.5 (CV)
unnamed: C6.1, R24.2, U4.6 (THR), U4.7 (DIS)
~OP_IOC: JP2.1 (A); also elsewhere on the board

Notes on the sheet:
Generates a pulse 110ms wide when ~{OP_IOC} goes low. Adjust this resistor to change pulse time.

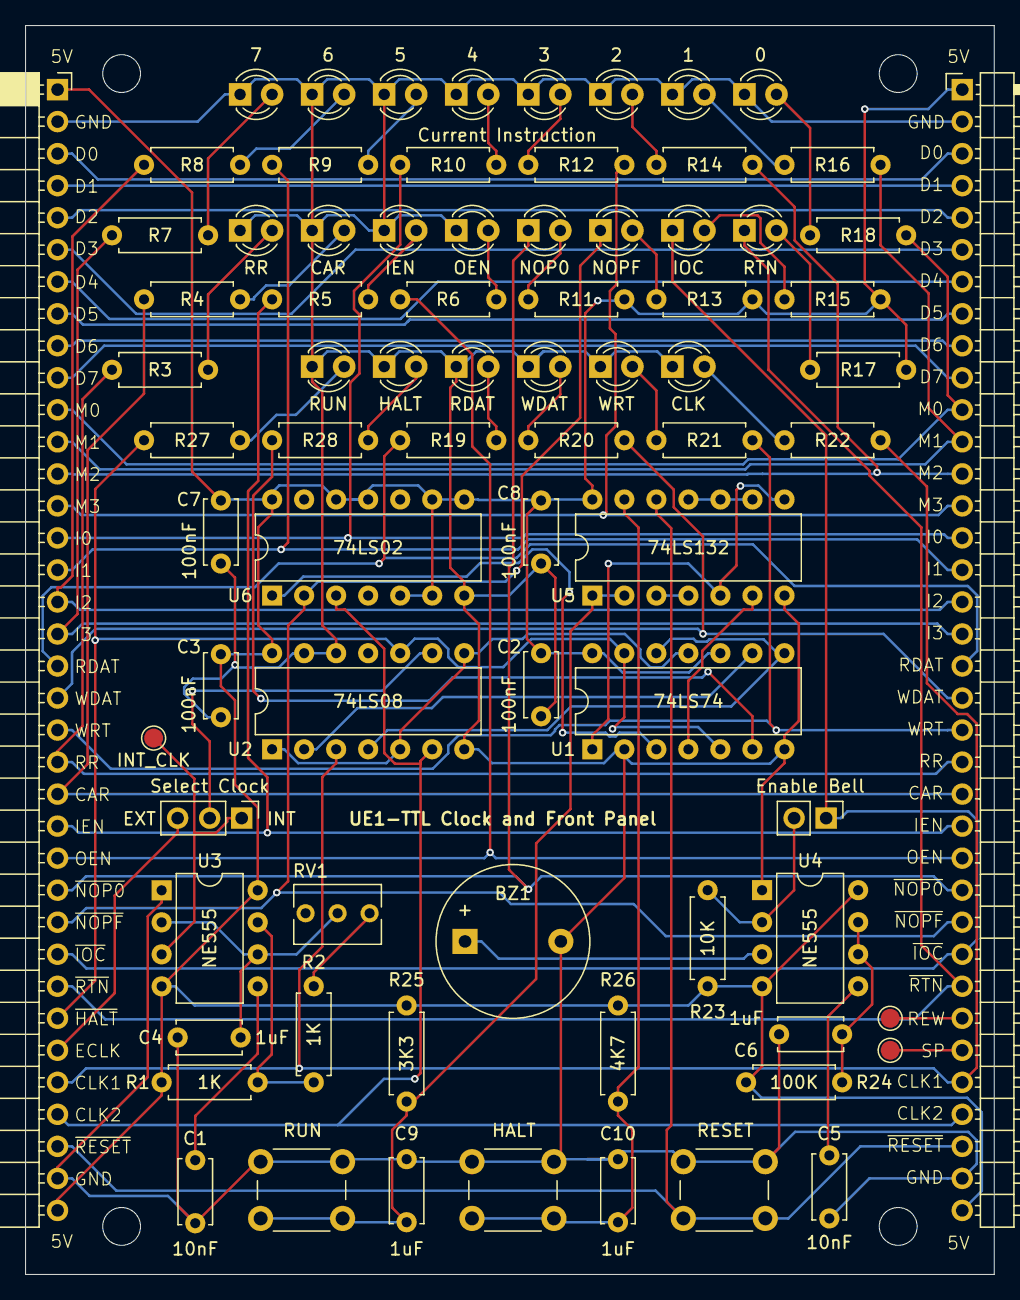
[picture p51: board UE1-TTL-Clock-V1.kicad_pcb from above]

Board: 2 copper layers, 76.8 x 99.1 mm, 82 parts (0 on the bottom side), 79 nets.

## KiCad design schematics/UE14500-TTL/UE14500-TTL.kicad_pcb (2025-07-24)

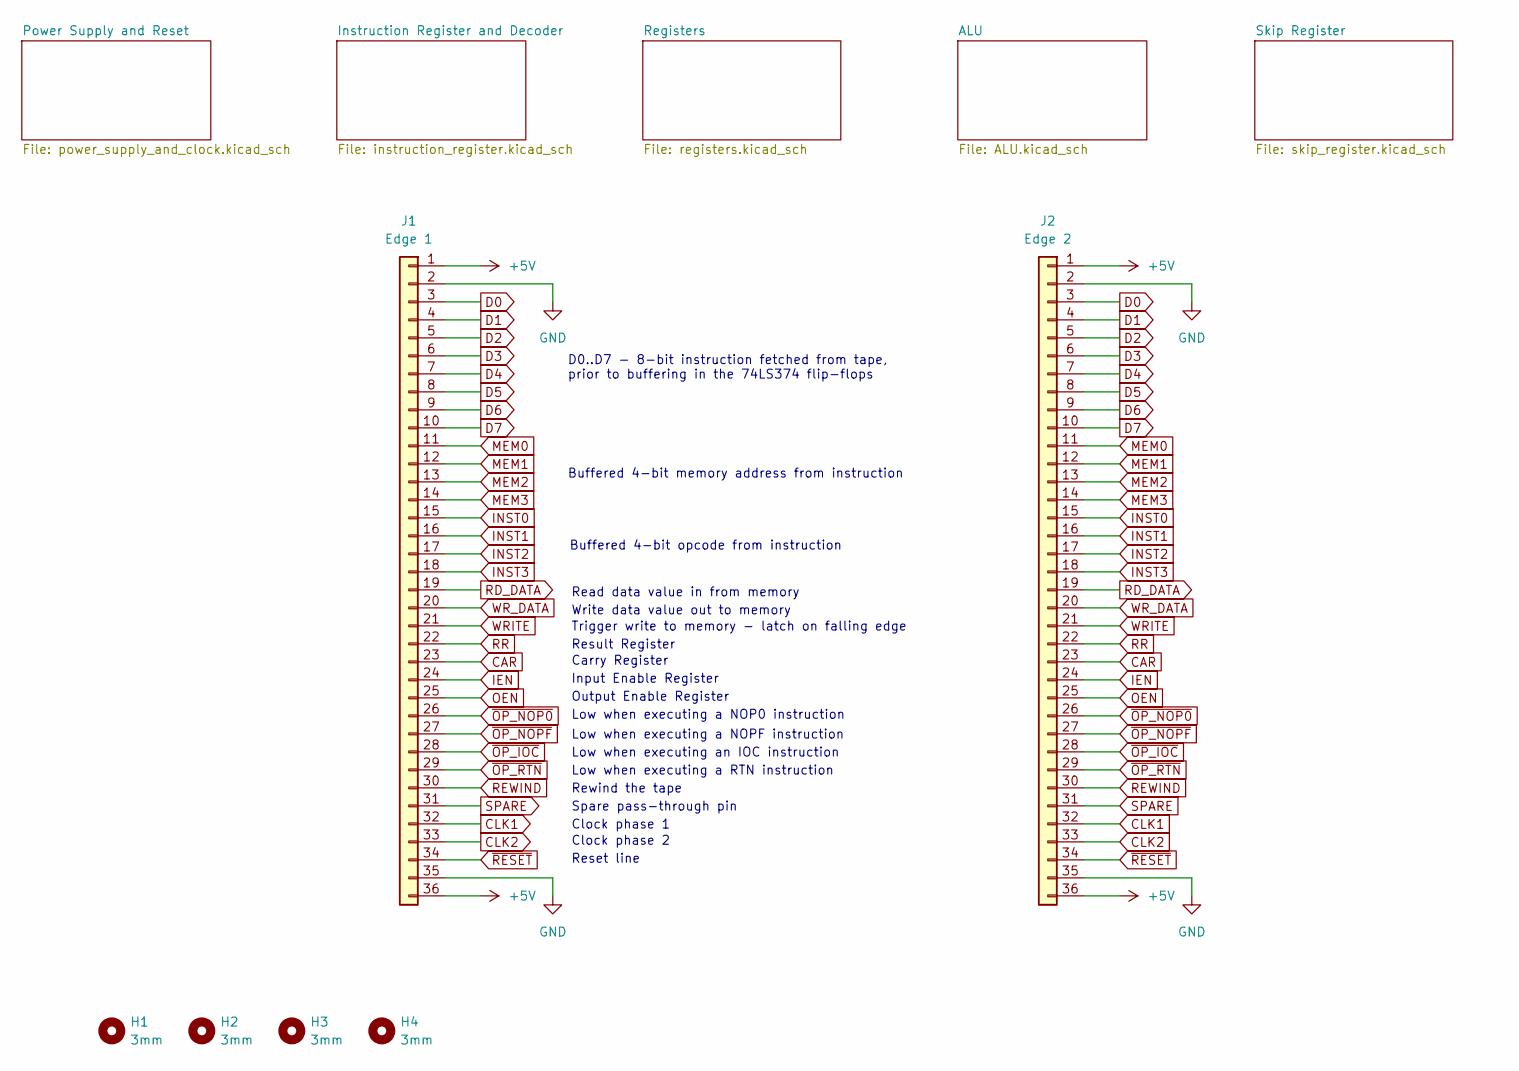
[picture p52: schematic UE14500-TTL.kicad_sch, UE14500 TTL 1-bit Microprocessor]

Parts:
H1, H2, H3, H4: 3mm; MountingHole_3mm
J1: Edge 1; PinSocket_1x36_P2.54mm_Horizontal
J2: Edge 2; PinHeader_1x36_P2.54mm_Horizontal

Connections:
+5V: J1.1, J1.36, J2.1, J2.36; also elsewhere on the board
CAR: J1.23, J2.23; also elsewhere on the board
CLK1: J1.32, J2.32; also elsewhere on the board
CLK2: J1.33, J2.33; also elsewhere on the board
D0: J1.3, J2.3; also elsewhere on the board
D1: J1.4, J2.4; also elsewhere on the board
D2: J1.5, J2.5; also elsewhere on the board
D3: J1.6, J2.6; also elsewhere on the board
D4: J1.7, J2.7; also elsewhere on the board
D5: J1.8, J2.8; also elsewhere on the board
D6: J1.9, J2.9; also elsewhere on the board
D7: J1.10, J2.10; also elsewhere on the board
GND: J1.2, J1.35, J2.2, J2.35; also elsewhere on the board
IEN: J1.24, J2.24; also elsewhere on the board
INST0: J1.15, J2.15; also elsewhere on the board
INST1: J1.16, J2.16; also elsewhere on the board
INST2: J1.17, J2.17; also elsewhere on the board
INST3: J1.18, J2.18; also elsewhere on the board
MEM0: J1.11, J2.11; also elsewhere on the board
MEM1: J1.12, J2.12; also elsewhere on the board
MEM2: J1.13, J2.13; also elsewhere on the board
MEM3: J1.14, J2.14; also elsewhere on the board
OEN: J1.25, J2.25; also elsewhere on the board
RD_DATA: J1.19, J2.19; also elsewhere on the board
REWIND: J1.30, J2.30; also elsewhere on the board
RR: J1.22, J2.22; also elsewhere on the board
SPARE: J1.31, J2.31
WRITE: J1.21, J2.21; also elsewhere on the board
WR_DATA: J1.20, J2.20; also elsewhere on the board
~OP_IOC: J1.28, J2.28; also elsewhere on the board
~OP_NOP0: J1.26, J2.26; also elsewhere on the board
~OP_NOPF: J1.27, J2.27; also elsewhere on the board
~OP_RTN: J1.29, J2.29; also elsewhere on the board
~RESET: J1.34, J2.34; also elsewhere on the board

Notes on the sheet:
Rewind the tape
Clock phase 2
Clock phase 1
Spare pass-through pin
Result Register
Output Enable Register
Low when executing a RTN instruction
Buffered 4-bit opcode from instruction
Low when executing a NOP0 instruction
Low when executing a NOPF instruction
D0..D7 - 8-bit instruction fetched from tape, prior to buffering in the 74LS374 flip-flops
Trigger write to memory - latch on falling edge
Reset line
Write data value out to memory
Input Enable Register
Read data value in from memory
Low when executing an IOC instruction
Carry Register
Buffered 4-bit memory address from instruction

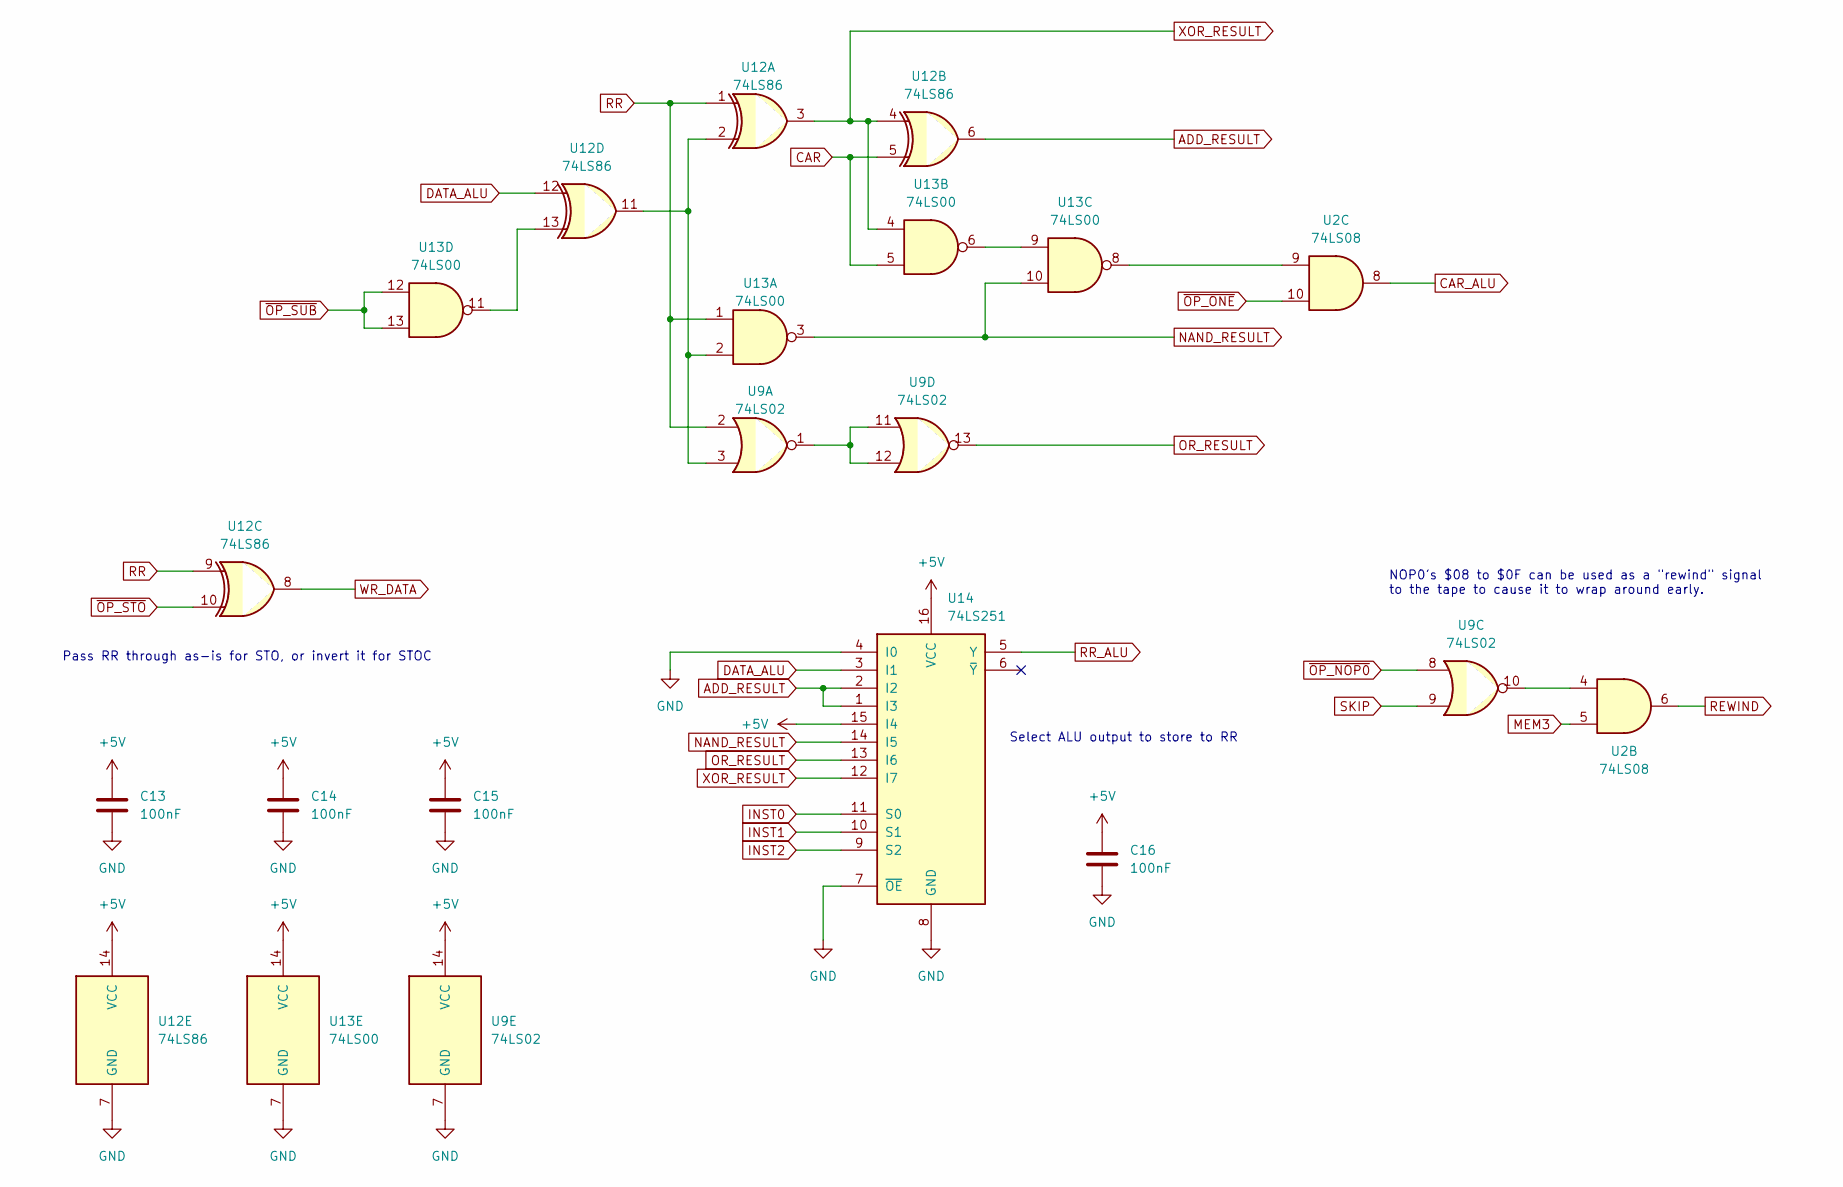
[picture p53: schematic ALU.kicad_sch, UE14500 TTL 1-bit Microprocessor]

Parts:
C13, C14, C15, C16: 100nF; C_Disc_D5.0mm_W2.5mm_P5.00mm
U2: 74LS08; DIP-14_W7.62mm
U9: 74LS02; DIP-14_W7.62mm
U12: 74LS86; DIP-14_W7.62mm
U13: 74LS00; DIP-14_W7.62mm
U14: 74LS251; DIP-16_W7.62mm

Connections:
+5V: C13.1, C14.1, C15.1, C16.1, U9.14 (VCC), U12.14 (VCC), U13.14 (VCC), U14.15 (I4), U14.16 (VCC); also elsewhere on the board
ADD_RESULT: U12.6, U14.1 (I3), U14.2 (I2)
CAR: U12.5, U13.5; also elsewhere on the board
CAR_ALU: U2.8; also elsewhere on the board
DATA_ALU: U12.12, U14.3 (I1); also elsewhere on the board
GND: C13.2, C14.2, C15.2, C16.2, U9.7 (GND), U12.7 (GND), U13.7 (GND), U14.4 (I0), U14.7 (~OE), U14.8 (GND); also elsewhere on the board
INST0: U14.11 (S0); also elsewhere on the board
INST1: U14.10 (S1); also elsewhere on the board
INST2: U14.9 (S2); also elsewhere on the board
MEM3: U2.5; also elsewhere on the board
NAND_RESULT: U13.3, U13.10, U14.14 (I5)
unnamed: U2.4, U9.10
unnamed: U9.1, U9.11, U9.12
unnamed: U9.3, U12.2, U12.11, U13.2
unnamed: U12.13, U13.11
unnamed: U13.6, U13.9
unnamed: U2.9, U13.8
OR_RESULT: U9.13, U14.13 (I6)
REWIND: U2.6; also elsewhere on the board
RR: U9.2, U12.1, U12.9, U13.1; also elsewhere on the board
RR_ALU: U14.5 (Y); also elsewhere on the board
SKIP: U9.9; also elsewhere on the board
WR_DATA: U12.8; also elsewhere on the board
XOR_RESULT: U12.3, U12.4, U13.4, U14.12 (I7)
~OP_NOP0: U9.8; also elsewhere on the board
~OP_ONE: U2.10; also elsewhere on the board
~OP_STO: U12.10; also elsewhere on the board
~OP_SUB: U13.12, U13.13; also elsewhere on the board

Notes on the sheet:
Select ALU output to store to RR
Pass RR through as-is for STO, or invert it for STOC
NOP0's $08 to $0F can be used as a "rewind" signal to the tape to cause it to wrap around early.

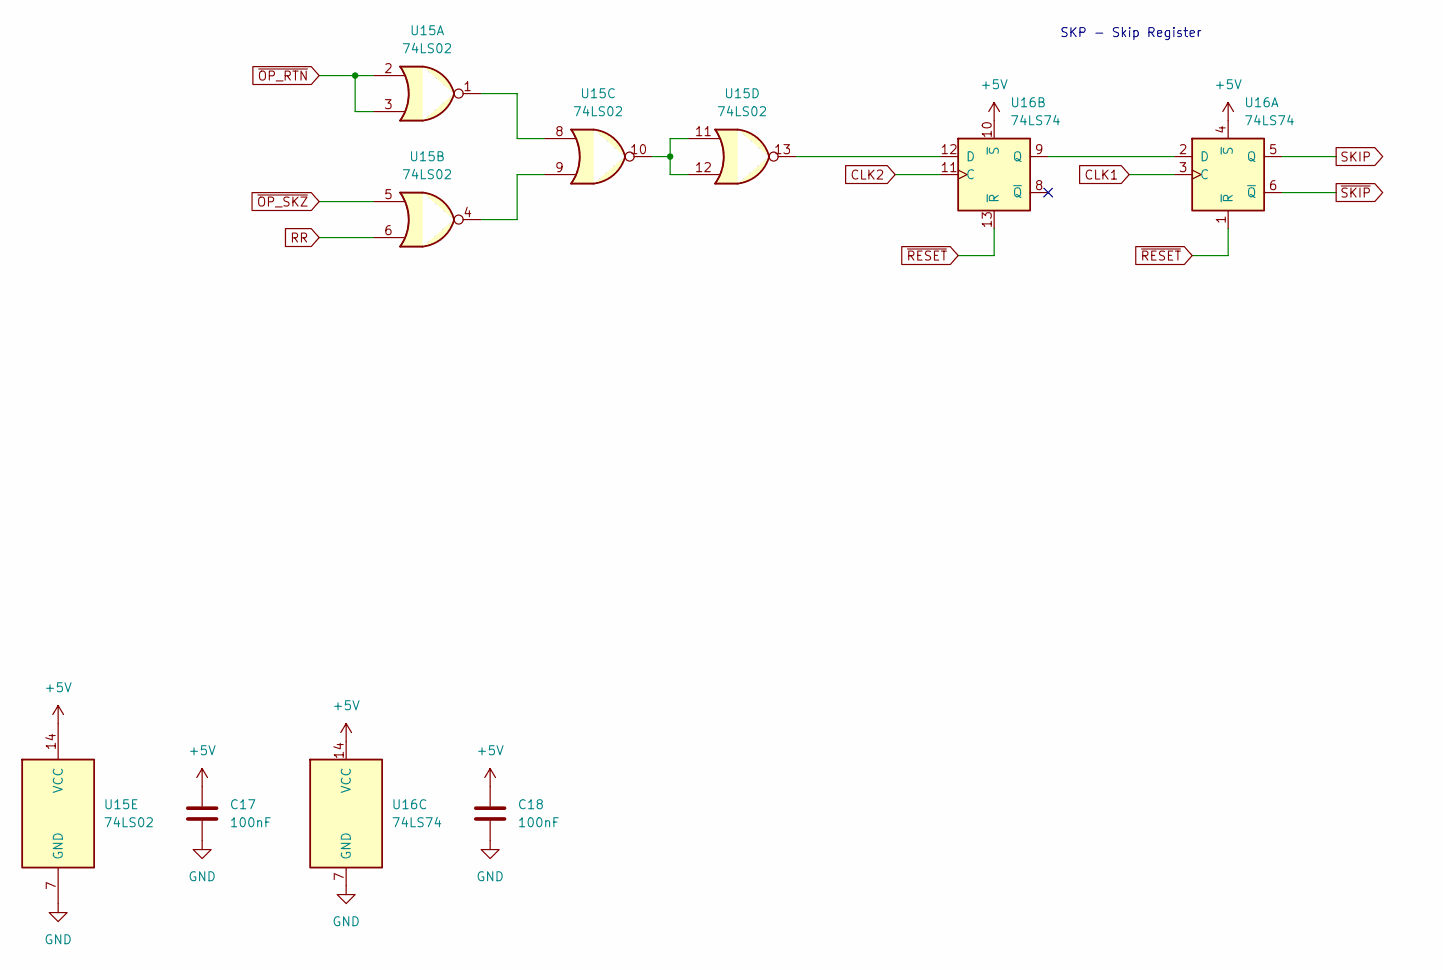
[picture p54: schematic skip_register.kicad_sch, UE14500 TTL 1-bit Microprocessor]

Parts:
C17, C18: 100nF; C_Disc_D5.0mm_W2.5mm_P5.00mm
U15: 74LS02; DIP-14_W7.62mm
U16: 74LS74; DIP-14_W7.62mm

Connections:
+5V: C17.1, C18.1, U15.14 (VCC), U16.4 (~S), U16.10 (~S), U16.14 (VCC); also elsewhere on the board
CLK1: U16.3 (C); also elsewhere on the board
CLK2: U16.11 (C); also elsewhere on the board
GND: C17.2, C18.2, U15.7 (GND), U16.7 (GND); also elsewhere on the board
unnamed: U15.1, U15.8
unnamed: U15.4, U15.9
unnamed: U15.10, U15.11, U15.12
unnamed: U16.2 (D), U16.9 (Q)
unnamed: U15.13, U16.12 (D)
RR: U15.6; also elsewhere on the board
SKIP: U16.5 (Q); also elsewhere on the board
~OP_RTN: U15.2, U15.3; also elsewhere on the board
~OP_SKZ: U15.5; also elsewhere on the board
~RESET: U16.1 (~R), U16.13 (~R); also elsewhere on the board
~SKIP: U16.6 (~Q); also elsewhere on the board

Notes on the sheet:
SKP - Skip Register

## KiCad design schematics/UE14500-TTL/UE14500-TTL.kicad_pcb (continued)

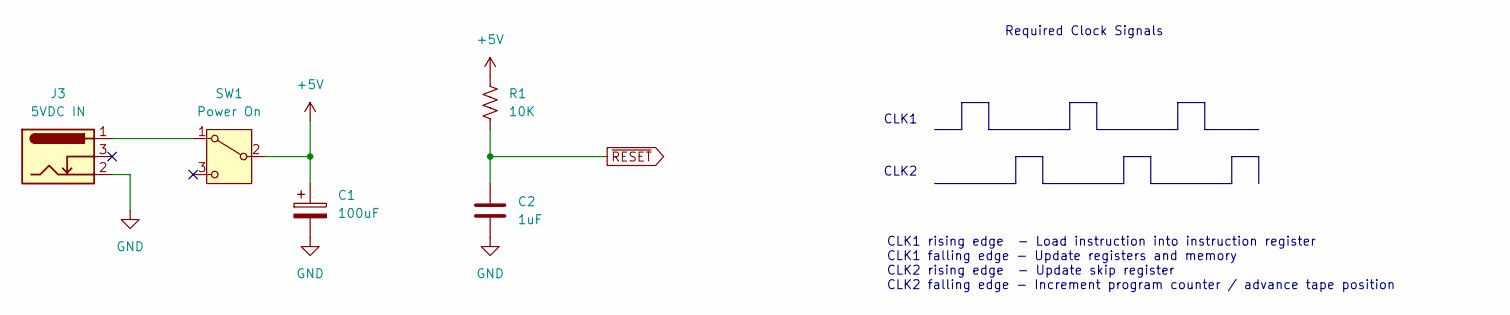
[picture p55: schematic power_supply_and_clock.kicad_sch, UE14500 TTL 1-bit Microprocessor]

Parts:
C1: 100uF; CP_Radial_D6.3mm_P2.50mm
C2: 1uF; C_Disc_D5.0mm_W2.5mm_P5.00mm
J3: 5VDC IN; BarrelJack_Horizontal
R1: 10K; R_Axial_DIN0207_L6.3mm_D2.5mm_P10.16mm_Horizontal
SW1: Power On; SW_Slide-03_Wuerth-WS-SLTV_10x2.5x6.4_P2.54mm

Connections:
+5V: C1.1, R1.2, SW1.2 (B); also elsewhere on the board
GND: C1.2, C2.2, J3.2; also elsewhere on the board
unnamed: J3.1, SW1.1 (A)
~RESET: C2.1, R1.1; also elsewhere on the board

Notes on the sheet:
CLK2
CLK1
CLK1 rising edge - Load instruction into instruction register CLK1 falling edge - Update registers and memory CLK2 rising edge - Update skip register CLK2 falling edge - Increment program counter / advance tape position
Required Clock Signals

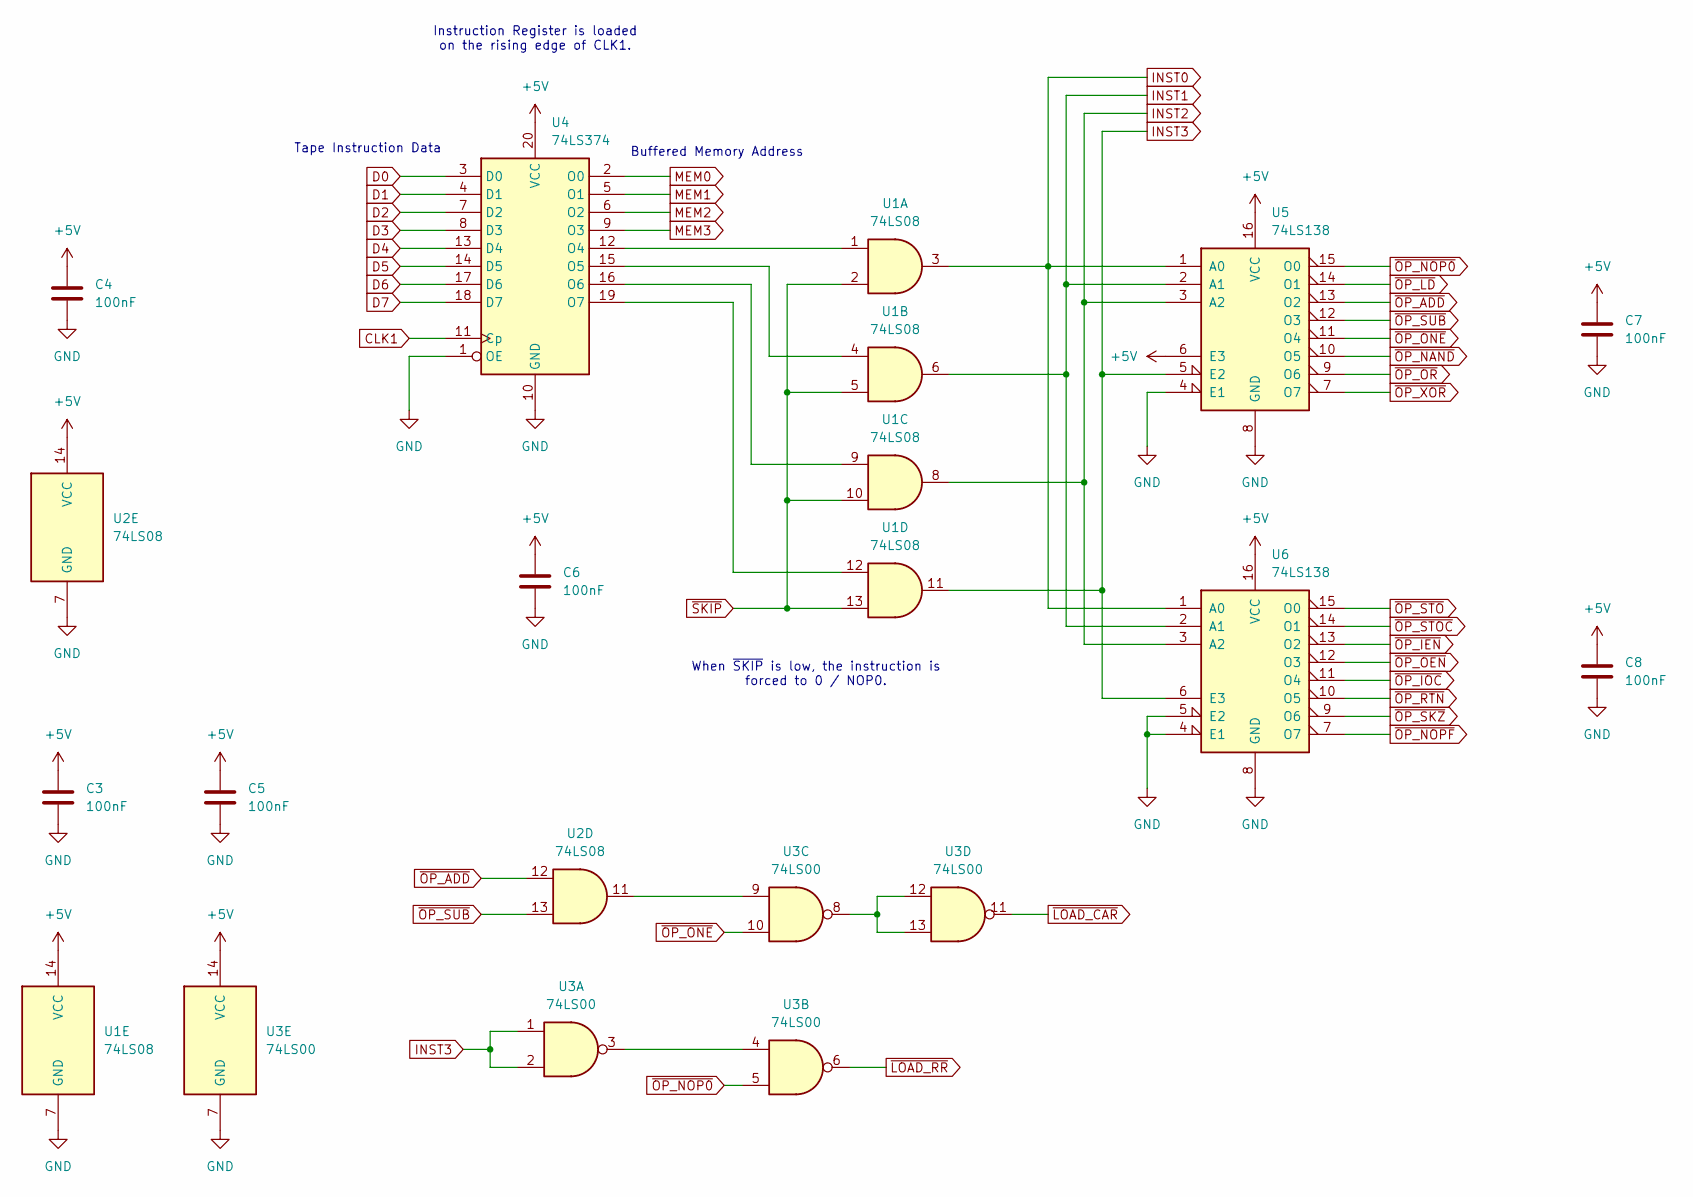
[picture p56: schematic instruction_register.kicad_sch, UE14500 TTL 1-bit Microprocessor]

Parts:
C3, C4, C5, C6, C7, C8: 100nF; C_Disc_D5.0mm_W2.5mm_P5.00mm
U1, U2: 74LS08; DIP-14_W7.62mm
U3: 74LS00; DIP-14_W7.62mm
U4: 74LS374; DIP-20_W7.62mm
U5, U6: 74LS138; DIP-16_W7.62mm

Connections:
+5V: C3.1, C4.1, C5.1, C6.1, C7.1, C8.1, U1.14 (VCC), U2.14 (VCC), U3.14 (VCC), U4.20 (VCC), U5.6 (E3), U5.16 (VCC), U6.16 (VCC); also elsewhere on the board
CLK1: U4.11 (Cp); also elsewhere on the board
D0: U4.3 (D0); also elsewhere on the board
D1: U4.4 (D1); also elsewhere on the board
D2: U4.7 (D2); also elsewhere on the board
D3: U4.8 (D3); also elsewhere on the board
D4: U4.13 (D4); also elsewhere on the board
D5: U4.14 (D5); also elsewhere on the board
D6: U4.17 (D6); also elsewhere on the board
D7: U4.18 (D7); also elsewhere on the board
GND: C3.2, C4.2, C5.2, C6.2, C7.2, C8.2, U1.7 (GND), U2.7 (GND), U3.7 (GND), U4.1 (OE), U4.10 (GND), U5.4 (E1), U5.8 (GND), U6.4 (E1), U6.5 (E2), U6.8 (GND); also elsewhere on the board
INST0: U1.3, U5.1 (A0), U6.1 (A0); also elsewhere on the board
INST1: U1.6, U5.2 (A1), U6.2 (A1); also elsewhere on the board
INST2: U1.8, U5.3 (A2), U6.3 (A2); also elsewhere on the board
INST3: U1.11, U3.1, U3.2, U5.5 (E2), U6.6 (E3); also elsewhere on the board
MEM0: U4.2 (O0); also elsewhere on the board
MEM1: U4.5 (O1); also elsewhere on the board
MEM2: U4.6 (O2); also elsewhere on the board
MEM3: U4.9 (O3); also elsewhere on the board
unnamed: U2.11, U3.9
unnamed: U3.3, U3.4
unnamed: U3.8, U3.12, U3.13
unnamed: U1.1, U4.12 (O4)
unnamed: U1.4, U4.15 (O5)
unnamed: U1.9, U4.16 (O6)
unnamed: U1.12, U4.19 (O7)
~LOAD_CAR: U3.11; also elsewhere on the board
~LOAD_RR: U3.6; also elsewhere on the board
~OP_ADD: U2.12, U5.13 (O2)
~OP_IEN: U6.13 (O2); also elsewhere on the board
~OP_IOC: U6.11 (O4); also elsewhere on the board
~OP_LD: U5.14 (O1)
~OP_NAND: U5.10 (O5)
~OP_NOP0: U3.5, U5.15 (O0); also elsewhere on the board
~OP_NOPF: U6.7 (O7); also elsewhere on the board
~OP_OEN: U6.12 (O3); also elsewhere on the board
~OP_ONE: U3.10, U5.11 (O4); also elsewhere on the board
~OP_OR: U5.9 (O6)
~OP_RTN: U6.10 (O5); also elsewhere on the board
~OP_SKZ: U6.9 (O6); also elsewhere on the board
~OP_STOC: U6.14 (O1); also elsewhere on the board
~OP_STO: U6.15 (O0); also elsewhere on the board
~OP_SUB: U2.13, U5.12 (O3); also elsewhere on the board
~OP_XOR: U5.7 (O7)
~SKIP: U1.2, U1.5, U1.10, U1.13; also elsewhere on the board

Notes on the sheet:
Tape Instruction Data
When ~{SKIP} is low, the instruction is forced to 0 / NOP0.
Instruction Register is loaded on the rising edge of CLK1.
Buffered Memory Address

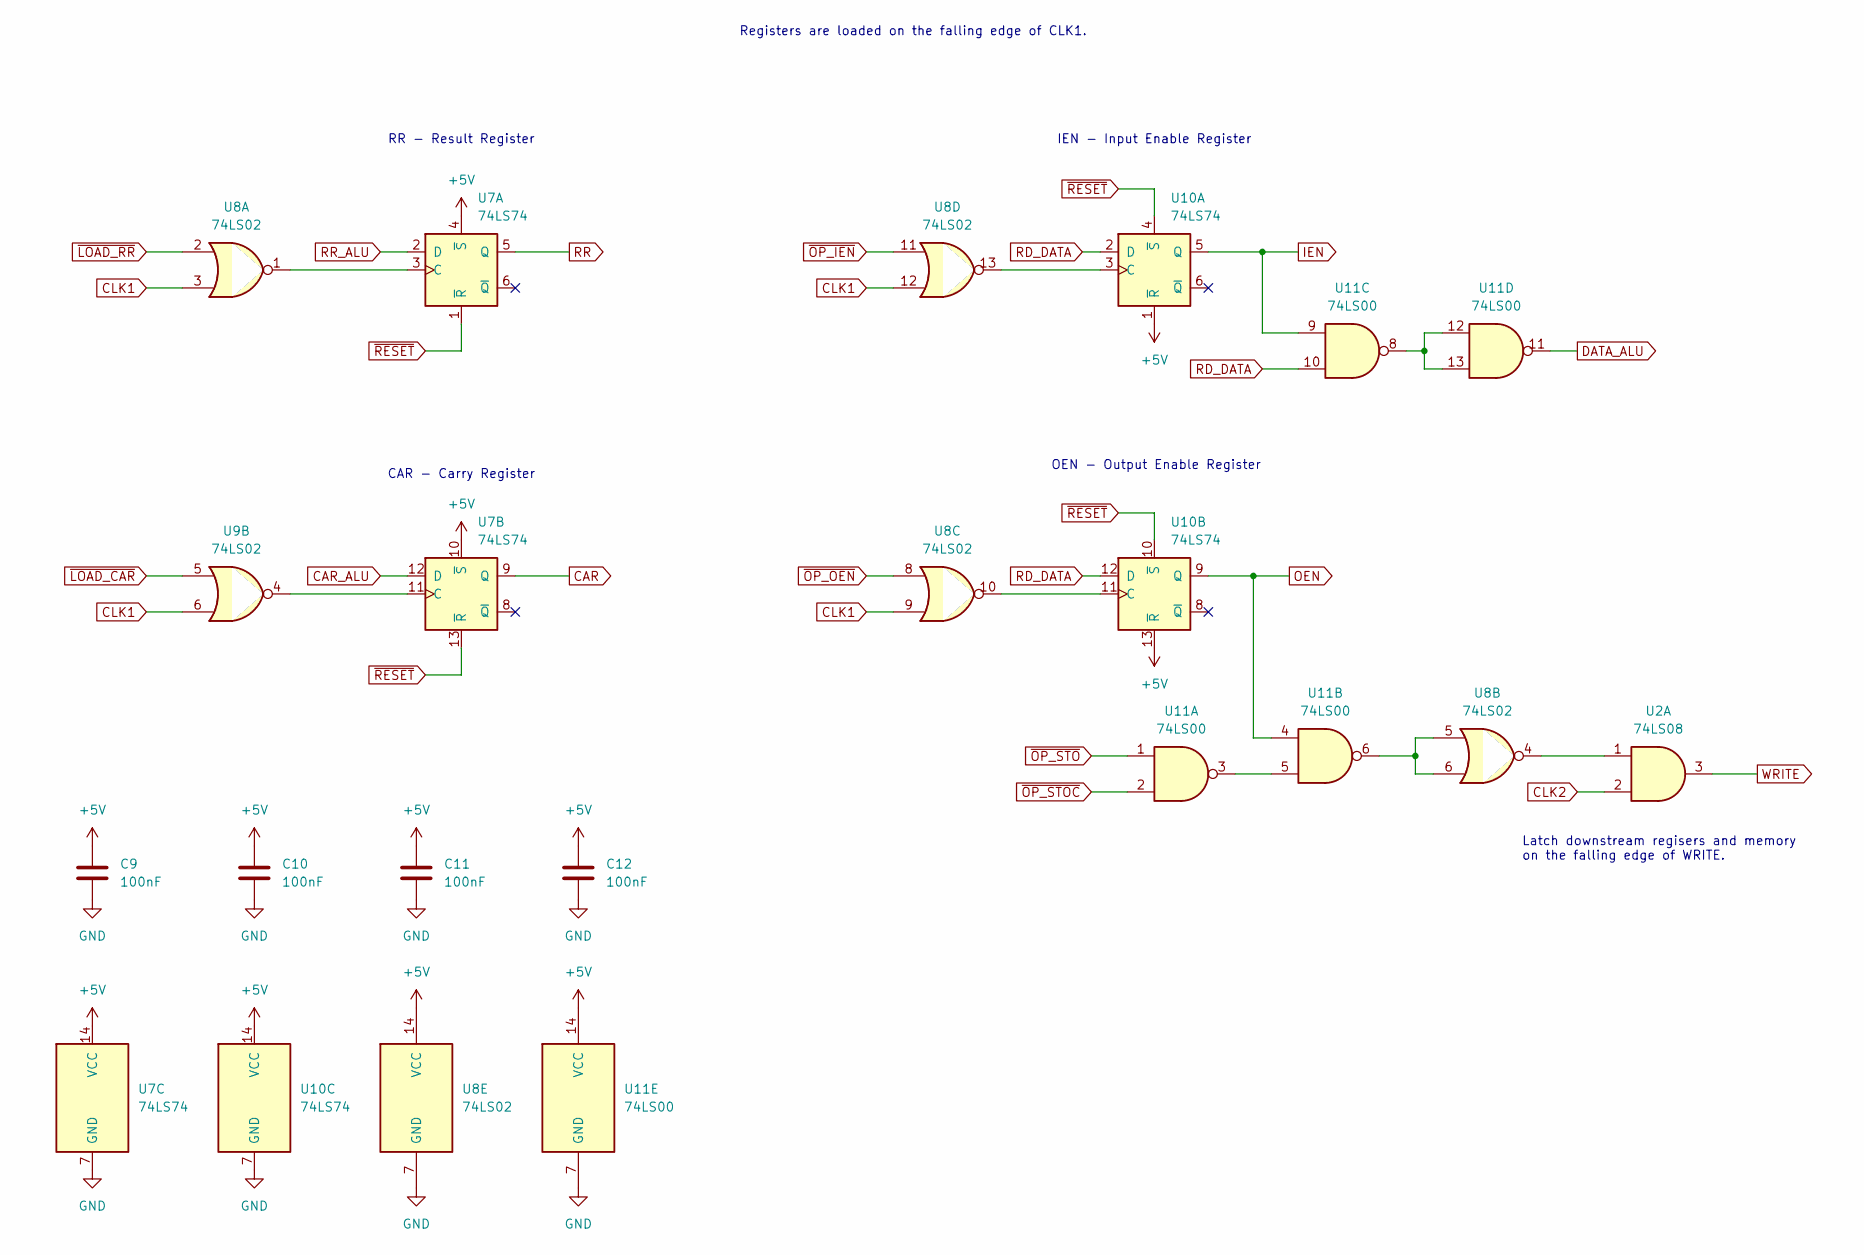
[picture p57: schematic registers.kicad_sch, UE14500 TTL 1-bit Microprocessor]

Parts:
C9, C10, C11, C12: 100nF; C_Disc_D5.0mm_W2.5mm_P5.00mm
U2: 74LS08; DIP-14_W7.62mm
U7, U10: 74LS74; DIP-14_W7.62mm
U8, U9: 74LS02; DIP-14_W7.62mm
U11: 74LS00; DIP-14_W7.62mm

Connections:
+5V: C9.1, C10.1, C11.1, C12.1, U7.4 (~S), U7.10 (~S), U7.14 (VCC), U8.14 (VCC), U10.1 (~R), U10.13 (~R), U10.14 (VCC), U11.14 (VCC); also elsewhere on the board
CAR: U7.9 (Q); also elsewhere on the board
CAR_ALU: U7.12 (D); also elsewhere on the board
CLK1: U8.3, U8.9, U8.12, U9.6; also elsewhere on the board
CLK2: U2.2; also elsewhere on the board
DATA_ALU: U11.11; also elsewhere on the board
GND: C9.2, C10.2, C11.2, C12.2, U7.7 (GND), U8.7 (GND), U10.7 (GND), U11.7 (GND); also elsewhere on the board
IEN: U10.5 (Q), U11.9; also elsewhere on the board
unnamed: U2.1, U8.4
unnamed: U7.3 (C), U8.1
unnamed: U7.11 (C), U9.4
unnamed: U8.13, U10.3 (C)
unnamed: U8.10, U10.11 (C)
unnamed: U11.3, U11.5
unnamed: U8.5, U8.6, U11.6
unnamed: U11.8, U11.12, U11.13
OEN: U10.9 (Q), U11.4; also elsewhere on the board
RD_DATA: U10.2 (D), U10.12 (D), U11.10; also elsewhere on the board
RR: U7.5 (Q); also elsewhere on the board
RR_ALU: U7.2 (D); also elsewhere on the board
WRITE: U2.3; also elsewhere on the board
~LOAD_CAR: U9.5; also elsewhere on the board
~LOAD_RR: U8.2; also elsewhere on the board
~OP_IEN: U8.11; also elsewhere on the board
~OP_OEN: U8.8; also elsewhere on the board
~OP_STOC: U11.2; also elsewhere on the board
~OP_STO: U11.1; also elsewhere on the board
~RESET: U7.1 (~R), U7.13 (~R), U10.4 (~S), U10.10 (~S); also elsewhere on the board

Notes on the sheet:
Registers are loaded on the falling edge of CLK1.
RR - Result Register
Latch downstream regisers and memory on the falling edge of WRITE.
IEN - Input Enable Register
OEN - Output Enable Register
CAR - Carry Register


Board: 2 copper layers, 76.8 x 99.1 mm, 43 parts (0 on the bottom side), 80 nets.

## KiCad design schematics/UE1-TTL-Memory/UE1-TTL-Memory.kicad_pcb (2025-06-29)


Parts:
H1, H2, H3, H4: 3mm; MountingHole_3mm
J1: Edge 1; PinSocket_1x36_P2.54mm_Horizontal
J2: Edge 2; PinHeader_1x36_P2.54mm_Horizontal

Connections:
+5V: J1.1, J1.36, J2.1, J2.36; also elsewhere on the board
CAR: J1.23, J2.23
CLK1: J1.32, J2.32
CLK2: J1.33, J2.33; also elsewhere on the board
D0: J1.3; also elsewhere on the board
D1: J1.4; also elsewhere on the board
D2: J1.5; also elsewhere on the board
D3: J1.6; also elsewhere on the board
D4: J1.7; also elsewhere on the board
D5: J1.8; also elsewhere on the board
D6: J1.9; also elsewhere on the board
D7: J1.10; also elsewhere on the board
GND: J1.2, J1.35, J2.2, J2.35; also elsewhere on the board
IEN: J1.24, J2.24
IR1: J2.12; also elsewhere on the board
IR2: J2.13; also elsewhere on the board
IR3: J2.14; also elsewhere on the board
IR4: J2.15; also elsewhere on the board
IR5: J2.16; also elsewhere on the board
IR6: J2.17; also elsewhere on the board
IR7: J2.18; also elsewhere on the board
MEM0: J1.11; also elsewhere on the board
MEM1: J1.12; also elsewhere on the board
MEM2: J1.13; also elsewhere on the board
MEM3: J1.14; also elsewhere on the board
OEN: J1.25, J2.25
OR0: J2.3; also elsewhere on the board
OR1: J2.4; also elsewhere on the board
OR2: J2.5; also elsewhere on the board
OR3: J2.6; also elsewhere on the board
OR4: J2.7; also elsewhere on the board
OR5: J2.8; also elsewhere on the board
OR6: J2.9; also elsewhere on the board
OR7: J2.10; also elsewhere on the board
RD_DATA: J1.19, J2.19; also elsewhere on the board
REWIND: J1.30, J2.30; also elsewhere on the board
RR: J1.22, J2.22; also elsewhere on the board
SPARE: J1.31, J2.31
WRITE: J1.21, J2.21; also elsewhere on the board
WR_DATA: J1.20, J2.20; also elsewhere on the board
~OP_IOC: J1.28, J2.28
~OP_NOP0: J1.26, J2.26
~OP_NOPF: J1.27, J2.27
~OP_RTN: J1.29, J2.29
~RESET: J1.34, J2.34; also elsewhere on the board


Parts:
C4: 100nF; C_Disc_D5.0mm_W2.5mm_P5.00mm
R2, R3, R4, R5, R6, R7, R8: 100K; R_Axial_DIN0207_L6.3mm_D2.5mm_P7.62mm_Horizontal
SW1: Inputs; SW_DIP_SPSTx08_Slide_6.7x21.88mm_W7.62mm_P2.54mm_LowProfile
U4: 74LS251; DIP-16_W7.62mm

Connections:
+5V: C4.1, SW1.10, SW1.11, SW1.12, SW1.13, SW1.14, SW1.15, SW1.16, U4.16 (VCC); also elsewhere on the board
GND: C4.2, R2.2, R3.2, R4.2, R5.2, R6.2, R7.2, R8.2, U4.8 (GND); also elsewhere on the board
IR1: R2.1, SW1.7, U4.3 (I1); also elsewhere on the board
IR2: R3.1, SW1.6, U4.2 (I2); also elsewhere on the board
IR3: R4.1, SW1.5, U4.1 (I3); also elsewhere on the board
IR4: R5.1, SW1.4, U4.15 (I4); also elsewhere on the board
IR5: R6.1, SW1.3, U4.14 (I5); also elsewhere on the board
IR6: R7.1, SW1.2, U4.13 (I6); also elsewhere on the board
IR7: R8.1, SW1.1, U4.12 (I7); also elsewhere on the board
MEM0: U4.11 (S0); also elsewhere on the board
MEM1: U4.10 (S1); also elsewhere on the board
MEM2: U4.9 (S2); also elsewhere on the board
RD_DATA: U4.5 (Y); also elsewhere on the board
RR: U4.4 (I0); also elsewhere on the board
~RD_IR: U4.7 (~OE); also elsewhere on the board

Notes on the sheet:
If the external inputs are driven, then all switches on the memory board must be in the OFF position.


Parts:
C5: 100nF; C_Disc_D5.0mm_W2.5mm_P5.00mm
D1: OR0; LED_D3.0mm
D2: OR1; LED_D3.0mm
D3: OR2; LED_D3.0mm
D4: OR3; LED_D3.0mm
D5: OR4; LED_D3.0mm
D6: OR5; LED_D3.0mm
D7: OR6; LED_D3.0mm
D8: OR7; LED_D3.0mm
R9, R10, R11, R12, R13, R14, R15, R16: RLED; R_Axial_DIN0207_L6.3mm_D2.5mm_P7.62mm_Horizontal
U5: 74LS259; DIP-16_W7.62mm

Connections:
+5V: C5.1, U5.16 (VCC); also elsewhere on the board
GND: C5.2, D1.1 (K), D2.1 (K), D3.1 (K), D4.1 (K), D5.1 (K), D6.1 (K), D7.1 (K), D8.1 (K), U5.8 (GND); also elsewhere on the board
MEM0: U5.1 (A0); also elsewhere on the board
MEM1: U5.2 (A1); also elsewhere on the board
MEM2: U5.3 (A2); also elsewhere on the board
unnamed: D1.2 (A), R9.2
unnamed: D2.2 (A), R10.2
unnamed: D3.2 (A), R11.2
unnamed: D4.2 (A), R12.2
unnamed: D5.2 (A), R13.2
unnamed: D6.2 (A), R14.2
unnamed: D7.2 (A), R15.2
unnamed: D8.2 (A), R16.2
OR0: R9.1, U5.4 (Q0); also elsewhere on the board
OR1: R10.1, U5.5 (Q1); also elsewhere on the board
OR2: R11.1, U5.6 (Q2); also elsewhere on the board
OR3: R12.1, U5.7 (Q3); also elsewhere on the board
OR4: R13.1, U5.9 (Q4); also elsewhere on the board
OR5: R14.1, U5.10 (Q5); also elsewhere on the board
OR6: R15.1, U5.11 (Q6); also elsewhere on the board
OR7: R16.1, U5.12 (Q7); also elsewhere on the board
WR_DATA: U5.13 (D); also elsewhere on the board
~RESET: U5.15 (Clr); also elsewhere on the board
~WR_OR: U5.14 (E); also elsewhere on the board

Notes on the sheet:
Choose RLED values to match the properties of the LED's you are using. RLED = (5 - VLED) / ILED Examples: VLED = 1.7V, ILED = 15mA, RLED = 220R VLED = 1.9V, ILED = 2mA, RLED = 1550R (1K8 should be fine) VLED = 1.9V, ILED = 10mA, RLED = 310R (330R should be fine) Recommend 2mA LED's to reduce curren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


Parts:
C1, C2, C3: 100nF; C_Disc_D5.0mm_W2.5mm_P5.00mm
R1: 10K; R_Axial_DIN0207_L6.3mm_D2.5mm_P7.62mm_Horizontal
U1: 74LS139; DIP-16_W7.62mm
U2: 74LS259; DIP-16_W7.62mm
U3: 74LS251; DIP-16_W7.62mm

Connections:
+5V: C1.1, C2.1, C3.1, R1.1, U1.16 (VCC), U2.16 (VCC), U3.16 (VCC); also elsewhere on the board
GND: C1.2, C2.2, C3.2, U1.1 (E), U1.8 (GND), U1.13 (A1), U1.15 (E), U2.8 (GND), U3.8 (GND); also elsewhere on the board
MEM0: U2.1 (A0), U3.11 (S0); also elsewhere on the board
MEM1: U2.2 (A1), U3.10 (S1); also elsewhere on the board
MEM2: U2.3 (A2), U3.9 (S2); also elsewhere on the board
MEM3: U1.3 (A1); also elsewhere on the board
unnamed: U2.4 (Q0), U3.4 (I0)
unnamed: U2.5 (Q1), U3.3 (I1)
unnamed: U2.6 (Q2), U3.2 (I2)
unnamed: U2.7 (Q3), U3.1 (I3)
unnamed: U2.9 (Q4), U3.15 (I4)
unnamed: U2.10 (Q5), U3.14 (I5)
unnamed: U2.11 (Q6), U3.13 (I6)
unnamed: U2.12 (Q7), U3.12 (I7)
RD_DATA: R1.2, U3.5 (Y); also elsewhere on the board
RESET: U1.11 (O1); also elsewhere on the board
WRITE: U1.2 (A0); also elsewhere on the board
WR_DATA: U2.13 (D); also elsewhere on the board
~RD_IR: U1.6 (O2); also elsewhere on the board
~RD_SR: U1.4 (O0), U3.7 (~OE)
~RESET: U1.14 (A0), U2.15 (Clr); also elsewhere on the board
~WR_OR: U1.7 (O3); also elsewhere on the board
~WR_SR: U1.5 (O1), U2.14 (E)

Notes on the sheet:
Acts as an inverter to convert ~{RESET} into RESET.
Pull-up to stop RD_DATA floating when nothing is driving it.


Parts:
C6, C7, C8, C9: 100nF; C_Disc_D5.0mm_W2.5mm_P5.00mm
R17, R18, R19: 100K; R_Axial_DIN0207_L6.3mm_D2.5mm_P7.62mm_Horizontal
SW2: Select Program; SW_DIP_SPSTx03_Slide_6.7x9.18mm_W7.62mm_P2.54mm_LowProfile
U6, U7: 74LS393; DIP-14_W7.62mm
U8: 74LS32; DIP-14_W7.62mm
U9: 28C256; DIP-28_W15.24mm_Socket

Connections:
+5V: C6.1, C7.1, C8.1, C9.1, SW2.4, SW2.5, SW2.6, U6.14 (VCC), U7.14 (VCC), U8.14 (VCC), U9.27 (~WE), U9.28 (VCC); also elsewhere on the board
CLK2: U6.1 (CP); also elsewhere on the board
D0: U9.11 (D0); also elsewhere on the board
D1: U9.12 (D1); also elsewhere on the board
D2: U9.13 (D2); also elsewhere on the board
D3: U9.15 (D3); also elsewhere on the board
D4: U9.16 (D4); also elsewhere on the board
D5: U9.17 (D5); also elsewhere on the board
D6: U9.18 (D6); also elsewhere on the board
D7: U9.19 (D7); also elsewhere on the board
GND: C6.2, C7.2, C8.2, C9.2, R17.2, R18.2, R19.2, U6.7 (GND), U7.7 (GND), U7.12 (MR), U7.13 (CP), U8.1, U8.2, U8.4, U8.5, U8.7 (GND), U8.12, U8.13, U9.14 (GND), U9.20 (~CS), U9.22 (~OE); also elsewhere on the board
unnamed: U6.3 (Q0), U9.10 (A0)
unnamed: U6.4 (Q1), U9.9 (A1)
unnamed: U6.5 (Q2), U9.8 (A2)
unnamed: U6.6 (Q3), U6.13 (CP), U9.7 (A3)
unnamed: U6.11 (Q0), U9.6 (A4)
unnamed: U6.10 (Q1), U9.5 (A5)
unnamed: U6.9 (Q2), U9.4 (A6)
unnamed: U6.8 (Q3), U7.1 (CP), U9.3 (A7)
unnamed: U7.3 (Q0), U9.25 (A8)
unnamed: U7.4 (Q1), U9.24 (A9)
unnamed: U7.5 (Q2), U9.21 (A10)
unnamed: U7.6 (Q3), U9.23 (A11)
PGM0: R17.1, SW2.3, U9.2 (A12)
PGM1: R18.1, SW2.2, U9.26 (A13)
PGM2: R19.1, SW2.1, U9.1 (A14)
RESET: U8.9; also elsewhere on the board
REWIND: U8.10; also elsewhere on the board
REWIND_TAPE: U6.2 (MR), U6.12 (MR), U7.2 (MR), U8.8

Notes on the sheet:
Selects 1 of 8 programs
Counters advance on falling edge of CLK2


Board: 2 copper layers, 76.8 x 99.1 mm, 53 parts (0 on the bottom side), 82 nets.

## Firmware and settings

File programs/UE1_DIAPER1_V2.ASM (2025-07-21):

;
; UE1 DIAPER 1 - Diagnostic Program for Easy Repair - Algorithmic Tests
;
; Version 1 - Original version
; Version 2 - Improve the IEN tests for NAND, OR, XOR, ADD
;
; Authors:
;       Rhys Weatherley
;
; This program tests the algorithmic behaivours of the UE1:  Loads, stores,
; arithmetic, logic, skips, IEN/OEN, and static RAM.
;
; Not tested: Inputs and outputs as they require human intervention to confirm.
; The output register is used to display the test number, but that's it.
;
; It is assumed that your UE1 (real or emulated) is already running simple
; programs such as the "UE1FIBO" example.  Otherwise you won't get very far
; with this test suite.
;
; For each test, the test number is displayed on the output register.
; After each test, the bell will ring once on success.  The program will
; halt with the failing test number on the output registers and no bell if a
; failure occurred.
;
; If all tests succeed, then all outputs are turned on, the bell will ring
; three times, and then the program will halt.
;
;   Test 1    - Check that "NAND RR" works as an inverter.
;   Test 2    - Exhaustive truth table test on "NAND".
;   Test 3    - Exhaustive truth table test on "OR".
;   Test 4-11 - Test each of SR0..SR7 in turn (Test 4 is SR0, Test 11 is SR7).
;   Test 12   - Exhaustive truth table test on "XOR".
;   Test 13   - Exhaustive truth table test on "ADD".
;   Test 14   - Exhaustive truth table test on "SUB".
;   Test 15   - Tests the "SKZ" instruction.
;   Test 16   - Tests the "RTN" instruction.
;   Test 17   - Tests the "OEN" instruction.
;   Test 18   - Tests "IEN" with the "LD" instruction.
;   Test 19   - Tests "IEN" with the "NAND" instruction.
;   Test 20   - Tests "IEN" with the "OR" instruction.
;   Test 21   - Tests "IEN" with the "XOR" instruction.
;   Test 22   - Tests "IEN" with the "ADD" instruction.
;   Test 23   - Tests "IEN" with the "SUB" instruction.
;   Test 24   - Tests "LD RR" in loopback mode.
;
; "NAND" and "OR" are tested before the scratch register because the SR
; tests make heavy use of "NAND" and "OR".  Tests 1 to 3 need SR0, SR6,
; and SR7 to basically work, but the rest of the scratch register is
; ignored until Test 4.
;
; There are no explicit tests for "ONE", which is heavily used in every test.
; If it doesn't work, you have bigger problems to worry about.
;
; The tests below also assume that the "SKZ" will do a skip when RR is 0.
; Most of the skips below are taken, because they skip over a halt for test
; failure.  So a "SKZ" implementation that always skips will work fine
; until Test 15.  Test 15 checks the other cases of skips taken / not taken.
; A "SKZ" instruction that never skips on RR = 0 will fail in Test 1.
;

;
; Initialize the registers: RR = 1, CAR = 0, IEN = 1, OEN = 1
;
; The "ONE" instruction is done twice, just in case the skip register
; is set to 1 when the program starts.  Otherwise we skip the init!
; We will test the skip register properly later.
;
ONE  SR0
ONE  SR0
IEN  RR
OEN  RR
;
; Clear all scratch registers and the output register.  Use "STOC" because
; RR is currently set to 1.  Normally, "NAND RR" can be used to flip RR to 0,
; but we can't trust that "NAND RR" works yet.
;
STOC SR0
STOC SR1
STOC SR2
STOC SR3
STOC SR4
STOC SR5
STOC SR6
STOC SR7
STOC OR0
STOC OR1
STOC OR2
STOC OR3
STOC OR4
STOC OR5
STOC OR6
STOC OR7
;
; Test 1 - Test that "NAND RR" wowrks as a simple inverter.
;
; "NAND RR" is used a lot in the tests below to invert 1 results into a 0
; before a "SKZ", to give the effect of a "SKNZ" instruction.  We definitely
; need "NAND RR" to work even if the rest of "NAND" doesn't.
;
; Instructions that are tested:
;
;       NAND RR
;
; Instructions that are assumed to work for this test, and may cause
; test failure if they don't work:
;
;       ONE, STOC SR0, LD SR0, SKZ, NOPF
;
ONE  SR0        ; Write the test number to the output register (1).
STO  OR0
;
; The code below will indirectly test if "SKZ" actually skips.  The program
; will halt if "NAND" is fine, but "SKZ" is not.  If "SKZ" skips but never
; stops skipping, then the rest of the tape will spool by and no other tests
; will be performed.
;
NAND RR         ; 1 NAND 1 = 0
SKZ  RR         ; Skip if RR is zero.
NOPF SR0
;
STOC SR0        ; Set SR0 to 1.
NAND RR         ; 0 NAND 0 = 1
STOC SR0        ; Set SR0 to 0 if the NAND worked.
NAND RR         ; 1 NAND 1 = 0 (we know that this should work from above).
SKZ  RR         ; Test fails if RR is currently set to 1.
NOPF SR0
LD   SR0        ; Load the result from SR0, which should be 0 on success.
SKZ  RR         ; Test fails if RR is currently set to 1.
NOPF SR0
;
IOC  SR0        ; Test Passed!  Bell!
;
; At this point, we are reasonably sure that "NAND RR" works as an inverter.
;
; Test 2 - Test the entire NAND truth table using RR and SR.
;
; Instructions that are tested:
;
;       NAND
;
; Instructions that are assumed to work for this test, and may cause
; test failure if they don't work:
;
;       NAND RR, ONE, STO SR0, STOC SR0, STO SR6, STOC SR7,
;       LD SR0, LD SR7, SKZ, NOPF
;
ONE  SR0        ; Write the test number to the output register (2).
STOC OR0
STO  OR1
;
STO  SR6        ; Set SR6 to 1.
STOC SR7        ; Set SR7 to 0.
;
NAND SR6        ; Test if 1 NAND 1 = 0.
STO  SR0        ; Shadow the result in SR0.
SKZ  RR
NOPF SR0
LD   SR0        ; Cross-check: SR0 should be zero.
SKZ  RR
NOPF SR0
;
ONE  SR0        ; Test if 1 NAND 0 = 1.
NAND SR7
STOC SR0        ; Shadow the inverse of the result in SR0.
NAND RR
SKZ  RR
NOPF SR0
LD   SR0        ; Cross-check: SR0 should be zero.
SKZ  RR
NOPF SR0
;
LD   SR7        ; Test if 0 NAND 1 = 1.
NAND SR6
STOC SR0        ; Shadow the inverse of the result in SR0.
NAND RR
SKZ  RR
NOPF SR0
LD   SR0        ; Cross-check: SR0 should be zero.
SKZ  RR
NOPF SR0
;
LD   SR7        ; Test if 0 NAND 0 = 1.
NAND SR7
STOC SR0        ; Shadow the inverse of the result in SR0.
NAND RR
SKZ  RR
NOPF SR0
LD   SR0        ; Cross-check: SR0 should be zero.
SKZ  RR
NOPF SR0
;
IOC  SR0        ; Test Passed!  Bell!
;
; Test 3 - Test the entire OR truth table using RR and SR.
;
; Instructions that are tested:
;
;       OR
;
; Instructions that are assumed to work for this test, and may cause
; test failure if they don't work:
;
;       NAND RR, ONE, STO SR0, STOC SR0, STO SR6, STOC SR7,
;       LD SR0, LD SR7, SKZ, NOPF
;
ONE  SR0        ; Write the test number to the output register (3).
STO  OR0
STO  OR1
;
STO  SR6        ; Set SR6 to 1.
STOC SR7        ; Set SR7 to 0.
;
OR   SR6        ; Test if 1 OR 1 = 1.
STOC SR0        ; Shadow the inverse of the result in SR0.
NAND RR
SKZ  RR
NOPF SR0
LD   SR0        ; Cross-check: SR0 should be zero.
SKZ  RR
NOPF SR0
;
ONE  SR0        ; Test if 1 OR 0 = 1.
OR   SR7
STOC SR0        ; Shadow the inverse of the result in SR0.
NAND RR
SKZ  RR
NOPF SR0
LD   SR0        ; Cross-check: SR0 should be zero.
SKZ  RR
NOPF SR0
;
LD   SR7        ; Test if 0 OR 1 = 1.
OR   SR6
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

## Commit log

2025-06-26 Schematic for the UE14500-TTL
    [ALU.kicad_sch, UE14500-TTL.kicad_pcb, UE14500-TTL.kicad_sch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]
2025-06-26 Schematics for the memory board
    [UE1-TTL-Memory.kicad_pcb, UE1-TTL-Memory.kicad_sch, input_register.kicad_sch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]
2025-06-27 Clock and Front Panel schematic
    [UE1-TTL-Clock.kicad_pcb, UE1-TTL-Clock.kicad_sch, bell.kicad_sch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]
2025-06-27 Add a tape "REWIND" opcode to reset the PC early
    [ALU.kicad_sch, UE1-TTL-Memory.kicad_pcb, UE1-TTL-Memory.kicad_sch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]
2025-06-27 Make some renderings of the computer
    [ALU.kicad_sch, UE1-TTL-Memory.kicad_pcb, UE14500-TTL.kicad_pcb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]
2025-06-28 Lay out CPU board
    [ALU.kicad_sch, UE14500-TTL.kicad_pcb, UE14500-TTL.kicad_sch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]
2025-06-28 Lay out clock board
    [UE1-TTL-Clock.kicad_pcb, UE1-TTL-Clock.kicad_sch, bell.kicad_sch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]
2025-06-28 Lay out memory board
    [UE1-TTL-Memory.kicad_pcb, UE1-TTL-Memory.kicad_sch, input_register.kicad_sch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]
2025-06-28 Change 74LS151 to 74LS251
    [ALU.kicad_sch, UE14500-TTL.kicad_pcb]
2025-06-29 Generate Gerbers
    [UE1-TTL-Clock-B_Cu.gbl, UE1-TTL-Clock-B_Mask.gbs, UE1-TTL-Clock-B_Paste.gbp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]
2025-06-29 Change capacitor in reset RC circuit to 1uF
    [power_supply_and_clock.kicad_sch]
2025-07-04 Assembling and testing the clock board
2025-07-05 Assembling and testing the processor board
2025-07-05 Document the signals on the edge connectors
2025-07-11 Copy UE14500-TTL schematic to UE14500-TTL-V1
    [ALU.kicad_sch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]
2025-07-12 Fix WRITE gating on processor board
    [UE14500-TTL-B_Cu.gbl, UE14500-TTL-B_Mask.gbs, UE14500-TTL-B_Paste.gbp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]
2025-07-12 Test procedure for the memory board
2025-07-12 Document how to do single-stepping off-board
2025-07-21 Work around some issues with the REWIND instruction
    [UE1_DIAPER1_V2.ASM]
2025-07-21 Rabbit example for 8x8 LED dot matrix displays
2025-07-24 Update the CPU schematic with V2 modifications
    [ALU.kicad_sch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]
2025-07-24 Update the clock schematic with V2 modifications
    [UE1-TTL-Clock-B_Cu.gbl, UE1-TTL-Clock-B_Paste.gbp, UE1-TTL-Clock-F_Cu.gtl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]

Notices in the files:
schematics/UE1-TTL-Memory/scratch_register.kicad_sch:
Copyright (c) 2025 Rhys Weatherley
